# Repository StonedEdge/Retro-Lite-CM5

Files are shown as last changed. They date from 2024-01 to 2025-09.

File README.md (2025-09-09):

<div align="center">
  <h1>Retro Lite/RetrOLED CM5: RK3588s Gaming Handheld</h1>
</div>

<div align="center">
  Image of Retro Lite CM5
</div>
<p align="center">This is the RetroLED CM5, a handheld console designed by GinKage, notime2d8 and StonedEdge.</p>

<div align="center">
  Image of Retro Lite CM5
</div>
<p align="center">Running Hollow Knight via Box64 and Steam on upstream Armbian kernel.</p>

<div align="center">
  Image of Retro Lite CM5
</div>
<p align="center">Official Android support, thanks to the work of notime2d8.</p>

<div align="center">
  Image of Retro Lite CM5
</div>
<p align="center">Latest ROCKNIX images available with Vulkan driver support.</p>

<div align="center">
  Image of Retro Lite CM5
</div>
<p align="center">Open source hardware files available for download.</p>

The Retro Lite/RetrOLED CM5 is an upgrade to the Retro Lite CM4 handheld. The project goal is to create a more powerful handheld that can handle 3DS, PS2 and GC emulation (none of which the Pi can do). I also would like to be able to play some games via Box64/86. It has a relatively large battery so run time should be excellent, considering it is ARM based. **Now with an optional OLED upgrade!**

Powered by the RK3588s compute module from Radxa, which is an SBC SOM module with an ARMv8 64-bit processor. Features 8 cores/threads - 4 x ARM Cortex-A55/A76 cores with A55 cores clocked at 1.8GHz, and A76 cores clocked at 2.4GHz. It also has a built-in Mali G610 GPU. 

The Retro Lite/RetrOLED CM5 offers a more modern gaming experience with DisplayPort via USB Type-C, USB 3.0 & HDMI 2.1. Built-in PCIe WiFI 6.0 & BT 5.2, as well as a new 720p IPS display @ 5.5" with touchscreen support & dual tact trigger buttons for GameCube support, make this a much more viable low-powered ARM SBC gaming PC than the Raspberry Pi 4. 

The operating system will be based on Armbian, with a custom device tree for hardware interfacing & RetroPie pre-installed. However, the user can use it however they would like, either in a Linux desktop environment or with other Linux based frontends, such as ES-DE. This handheld should be able to play the entire PS2 library at least 1x native resolution for all games, as well as GameCube at 1x on Linux with OpenGLES drivers. Android is currently more performant due to Vulkan drivers, however Linux Vulkan blobs should come soon (or someday, who knows). We also now have succesfully compiled ROCKNIX as well. Eventually I will compile all of the final images to GitHub. 

For regular updates/following progress on the build, please check out the forum post here:
https://bitbuilt.net/forums/index.php?threads/retro-lite-cm5.5815/

# Retro Lite/RetrOLED CM5: Radxa RK3588s Handheld 

## Features

Hardware specifications:

- 3D printable housing in PLA. Comfort grips for added ergonomics
- Radxa CM5 Compute Module (8GB RAM/64GB eMMC)
- SoC – Rockchip RK3588S octa-core processor with 4x Cortex‑A76 cores @ up to 2.4GHz, 4x Cortex‑A55 core @ 1.8GHz
Arm Mali-G610 MP4 “Odin” GPU Video decoder – 8Kp60 H.265, VP9, AVS2, 8Kp30 H.264 AVC/MVC, 4Kp60 AV1, 1080p60 MPEG-2/-1, VC-1, VP8 Video encoder – 8Kp30 H.265/H.264 video encoder
- WiFi 6/Bluetooth 5.2 via PCIe E-key slot (Intel AX210) - https://www.intel.com/content/www/us/en/products/sku/204836/intel-wifi-6e-ax210-gig/specifications.html
- 6 layer carrier board with 3 B2B mezzanine connectors to interface with any Radxa CM5 module 
- 5v boost rated at 3.5A continuous current
- RP2040 gamepad - complete with SDL mappings and evdev gyro support/mouse control via MPU6050
- 1280 x 720p (5.5" DSI IPS LCD): DSI video output on internal display
**- New: Optional 1920 x 1080p (5.44" AMOLED): DSI video output on internal display** 
- Up to 4k HDMI video output via HDMI output
- Up to 4k DisplayPort Alternate Mode via Type-C
- USB 2.0/3.1 capable USB-C data transfer
- USB-C dual role port functionality (sink/source)
- Brightness and volume HUD adjustment. Brightness is adjusted by holding plus hotkey + down/up. Volume controlled either by volume buttons or plus hotkey + left right DPAD
- USB-C PD charging support via sink profiles supporting 5V/3A, 9V/3A, 12V/2A & 15V/2.6A (switch charger) via TPS65987D PD controller (see binary in TPS65987D folder). Recommended to use <12V for best charge and play performance 
- Stereo Audio Output via i2s. Dual stereo speakers with ported chambers
- Headphone jack, with automatic switching
- 5000mAh lipo, providing around 1.5-5 hours of gameplay depending on load (to be upgraded soon to >8000mAh)
- Dual stacked shoulder buttons (L, R, LZ, RZ) with dual tact buttons for GameCube functionality (LR analog/LR digital)
- 2x hall effect analog sticks running at 3v3
- Resin casted ABXY, DPAD, start+select, shoulder buttons
- Silicone membranes for nice button feel 

Software specifications:

- Armbian GNOME desktop (Kernel 6.1.57 as of this post)
- Android 13 support (beta)
- Full upstream Rocknix support
- Wayland windowing system (xorg capable)
- Hardware graphics support via Panfrost/OpenGLES/I want a broken vulkan driver "support"
- Safe software/hardware shutdown (either from software or via button)
- Low power sleep mode - in my tests, 24 hours in standby mode draws around 6% of total battery life
- Range adjustable joysticks in software by pressing plus hotkey plus R3 --> A --> rotate sticks --> A combination
-------------------------------------------------------------------------------------------------------

### CAD
Enclosure files have been uploaded in STL and STEP format [here.](https://github.com/StonedEdge/Retro-Lite-CM5/tree/main/enclosure)
Make sure to use v2 as these contain all the latest and greatest changes. 

-------------------------------------------------------------------------------------------------------

### PCB
v1 Controller PCBs have been uploaded [here.](https://github.com/StonedEdge/Retro-Lite-CM5/tree/main/rp2040_gamepad/PCB)
Please note that you will not be able to assemble the unit with the UART/serial debug components soldered onto the boards, so make sure these aren't populated. 

v1.1 CM5 carrier boards have been uploaded [here.](https://github.com/StonedEdge/Retro-Lite-CM5/tree/main/cm5_carrier_pcb)

-------------------------------------------------------------------------------------------------------

### BOM (Bill of Materials) 
v1 Right Controller PCB BOM have been uploaded [here.](https://github.com/StonedEdge/Retro-Lite-CM5/blob/main/rp2040_gamepad/PCB/Retro_Lite_CM5_Right_PCB_v1%20-%20BOM.csv)

v1 Left Controller PCB BOM have been uploaded [here.](https://github.com/StonedEdge/Retro-Lite-CM5/blob/main/rp2040_gamepad/PCB/v1/Retro_Lite_CM5_Left_PCB_v1%20-%20BOM.csv)

v1 V2.2 Carrier PCB BOM has been uploaded [here.](https://github.com/StonedEdge/Retro-Lite-CM5/blob/main/cm5_carrier_pcb/Retro_Lite_CM5_IO_X2.2_BOM.csv) 
The board has been verified and fully functional with Radxa V2.2 CM5 modules! V2.21 also works fine. 

-------------------------------------------------------------------------------------------------------

### To-do
- [x] Hardware familiarization - Orange Pi 5/Radxa CM5/IO board schematics
- [x] Design v1 prototype left/right controller PCBs (ATMEGA32u4 based)
- [x] Design v1 DSI test display board
- [x] Design v1 Power Management/DisplayPort/USB-C PD test board
- [x] Order v1 Power Management/DisplayPort/USB-C PD test board
- [x] Design v2 prototype left/right controller PCBs (RP2040 based)
- [x] Test v1 Power Management/DisplayPort Alternate Mode/USB-C PD test board functionality - works!
- [x] Design CM5 carrier main board (v1.0) that implements new hardware features, such as DisplayPort, USB3 and PCIe
- [x] Order CM5 carrier board (v1.0) with desired fab house. (It's in production!)
- [x] Test CM5 carrier board (v1.0) hardware for a basic functioning prototype
- [x] Redesign CM5 carrier board (v1.1) with fixes for 3rd connector polarity & other small fixes
- [x] Reorder v1.1 carrier board
- [x] Investigate RK806 PMIC issue
- [x] Prepare an Armbian based OS image, including the BSP (bootloader, dtb and kernel) for the RK3588s Armbian rootfs. DTB should include the ILI9881C/WM8960 drivers
- [x] Integrate new 5.5 inch MIPI DSI display. This includes enabling the ILI9881C display driver, device tree customizations for the display
- [x] Test and verify display functionality, including proper backlight & 60 FPS. Verify display works with Armbian 
- [x] WM8960 codec integration via Orange Pi 5/CM5 IO for testing. Integrate the WM8960 i2c code driver including any device tree customizations for codec. Finally, test and verify audio works correctly
- [x] Integrate touch/verify via the GT911 controller 
- [x] Test and verify emulators work correctly with Mali blobs and can be launched via EmulationStation front end
- [x] Setup Mali Open GL blob drivers to work with PS2 (AetherSX2) & GC (Dolphin) emulators due to no Vulkan backend available (yet!)
- [x] Write HID controller code for RP2040. Verify basic gamepad functionality works as intended
- [x] Integrate an IMU into the controller PCB for gyro functionality. Include EKF algorithm (MPU-6050 6-axis IMU) 
- [x] Redesign housing (increase 3mm in all directions) in Solidworks. Improve trigger feel and add battery mounting bracket
- [x] Redesign housing v2 (increase thickness to accomodate 6Ah battery cell at 3.8v, mount battery and fan to front housing)
- [x] Redesign housing with injection molding in mind - include appropriate draft angles, ribs, gussets, radiused corners & bosses
- [x] Redesign housing to use original switch lite fan enclosure 
- [x] Power on/power off/sleep mode via ATtiny84 (Power control)
- [x] Put together a fully functional dts for the CM5 IO Board (Device Tree Source) to understand hardware configuration 
- [x] MAX17055 integration into device tree 
- [x] Prepare reference implementation for launching games via EmulationStation/some form of frontend (likely ES-DE/RetroPie)
- [x] Implement an on-screen indicator for volume, brightness control via GPIOs
- [x] Rocknix upstream support
- [x] Android 13 support 
- [ ] Adjust BQ24292i registers to charge to 4.35v max instead of 4.2v due to using LiHv cell (might not do, given cells may go kaboom)
- [x] Other optimizations/improvements/bug fixes
- [x] Create prototype showcase video for YouTube
- [x] Final GitHub open source release & announcement!
- [x] Integrate OLED RM67199 patches
- [x] Integrate goodix gtx8 patches (GT9886)
-------------------------------------------------------------------------------------------------------

### Firmware 
At the moment, there are a couple of options for firmware which I will separate out into two devices, the Retro Lite CM5 and the RetrOLED CM5. 
We are continuing to work on these - few developers will be getting units soon which should accelerate the process of development as well.  

**Retro Lite CM5**
- [x] ROCKNIX
- [x] Armbian Gnome Desktop (OpenGL/OpenGLES)
- [x] Armbian Gnome Desktop (OpenGLES/Vulkan)
- [x] Android 13 (Beta)
- [ ] Android 14 (kind of lost interest in Android, probably not likely to happen anytime soon). 

**RetrOLED CM5**
- [x] ROCKNIX
- [x] Armbian Gnome Desktop (OpenGL/OpenGLES)
- [x] Armbian Gnome Desktop (OpenGLES/Vulkan)
- [ ] Android 13 (Beta - shit is broken, like brightness control which we never got working)
- [ ] Android 14 (kind of lost interest in Android, probably not likely to happen anytime soon). 
-------------------------------------------------------------------------------------------------------

### Frequently Asked Questions (FAQ) 
Q: How can I get my hand on a Retro Lite/RetrOLED CM5? Do you sell them or will you sell them?

A: Radxa have advised that **this device will not be mass produced**. There is no method to get your hands on one of these at this time. This project is mainly for fun, cost is not a huge consideration here. 

Q: How much does it cost in parts to build one of these?

A: Expect to spend at minimum around $350-400 for a single one-off build. 

Q: Why dont you use an OLED screen? 

A: **Funny you ask. We now have OLED support!** The OLED screen is functioning with touch integration. We are using this OLED screen here: https://www.alibaba.com/product-detail/oled-display-module-5-44inch-oled_60726980273.html
Make sure you confirm the model number is ET055FH06-GT. You will also need to order the flex PCB with JLCPCB (costs around $10). 2 layer is fine, make sure to send them the production files as a reference. I have verified that it works with the current carrier board. 

Q: Why do this when you can get an equivalent handheld from Aliexpress for $150? This is stupid and DOA! Makes no sense! Non-sensical! I'm going to buy myself a better handheld. 

A: Because it's fun to build something awesome. It's not about the end result, its the process for me. Thanks for visiting & farewell, this project probably isn't for you. 

Q: Is Vulkan working yet on Linux?

A: We have a temporarily solution for Vulkan on Linux, but the driver is not conformant yet. PanVk is on its way though. 

Q: Can you please make me one for exposure on YouTube? I promise to give incredible reviews!

A: Nope. I simply don't have time. Sorry. 

### License

[][cc-by-nc-sa]

This work is licensed under a
[Creative Commons Attribution-NonCommercial-ShareAlike 4.0 International License][cc-by-nc-sa].

[][cc-by-nc-sa]

[cc-by-nc-sa]: http://creativecommons.org/licenses/by-nc-sa/4.0/
[cc-by-nc-sa-image]: https://licensebuttons.net/l/by-nc-sa/4.0/88x31.png
[cc-by-nc-sa-shield]: https://img.shields.io/badge/License-CC%20BY--NC--SA%204.0-lightgrey.svg

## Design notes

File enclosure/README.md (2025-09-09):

### Current Status
The shell is complete. Rear triggers have been tweaked to work better than previous versions, but always open to feedback and improvements here. 

After assembling v1 and running tests, I am working on improvements to the design which will be uploaded to STL_v2 folder. It is recommended to assemble v2 only (v1 is now deprecated).

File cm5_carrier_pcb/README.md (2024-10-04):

# Retro Lite CM5 Carrier Board v1.1 

<p align="center">
  
</p>

## What is this folder?
Note: The current files are now tested and verified to work with Radxa v2.2 carrier boards. **Also now verified to work Radxa V2.21 boards!**

This folder contains the BOM, EAGLE schematic (.sch) and board (.brd) files, as well as pick & place files to order the board with JLCPCB or your fab of choice. 
The main carrier board is a 6-layer board and you should order the board with impedance matching, according to the JLC06081H-2116 (Standard) stackup offering (0.8mm thickness). 
Currently, this version is only compatible with the Radxa CM5 (version X2.2/X2.21) & I have not tested it with other SoMs, like the Raspberry Pi CM4. 

Expect to pay around $250 per board to have it fabbed and turnkeyed with JLCPCB.

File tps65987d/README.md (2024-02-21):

# TPS65987D Test Board v3

<p align="center">
   
</p>

## What is this folder? 
This folder contains the test fixture schematic and board files (EAGLE) designed to test the functionality of the TPS65987D PD controller and TUSB546A superspeed mux, as well as other features that will be included on the main carrier board for the final build. Feel free to use it as a reference design for a USB-C DRP application in your designs. 
It also contains the project file that can be used to edit specific parameters in the TPS65987x GUI Application Tool, depending on your required use case. I used an RP2040 to flash the binary to the SPI module & final binary to be used in the CM5 will be uploaded when ready. 

## Purpose of PCB
To provide an environment to test out the TPS6598x GUI Application Tool, change parameters and flash a binary for a USB-C DRP application. The current CM5 is programmed with the parameters found in the .pjt file here. You can use this tool if you want to play around with it or change certain parameters to suit your specific application: https://www.ti.com/tool/TPS6598X-CONFIG

The flash module is an W25X05 and communicates with the PD device over the SPI bus. It loads this flash either via 3V3 power or dead battery mode via VBUS power. You can also program the TPS65987D (the USB-PD controller) via the I2C bus. 

The bottom USB-C connector is for plugging in sink/source device to charge the battery or power a USB device (like a keyboard, mouse or thumb drive). This will be the port on the final handheld itself. 

The top two USB-C ports are for high speed data buses, namely DisplayPort & USB 3.1.

The ATtiny is connected to the button, which is used to control power, sleep & regulator enable. We use this to safely tell the CM5 to shutdown before the enable pin is driven low. The ATtiny is also connected to the BQ24292i over I2C & sets the specific registers required for monitoring the battery - charging current, termination current, and other parameters like charge cutoff voltage. 

Flash the SPI module via the command line, for example, using serprog. 
```flashrom -p serprog:dev=/dev/ttyACM0:115200,spispeed=12M -c W25X05 -w .bin```

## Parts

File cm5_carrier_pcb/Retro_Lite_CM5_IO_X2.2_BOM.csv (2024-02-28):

Qty | Value | Device | Package | Parts | Description
6 | N/A | LEDSML0603 | SML0603 | PDO1, PDO1_SRC, PDO2, PDO3, PDO4, SSMX_DP_ACTIVE, SSMX_FLIP_ACTIVE | BLUE_LED_GENERIC
1 | N/A | LEDSML0603 | SML0603 | CHRG | WHITE_LED_GENERIC
1 | N/A | LEDSML0603 | SML0603 | VBAT_L | RED_LED_GENERIC
5 | 0R | R-EU_R0402 | R0402 | JU_5, R13, R34, R36, R42 | Resistor
1 | 0.047µF | C-EUC0603 | C0603 | C29 | Capacitor
1 | 0.1uF | C-EUC0402 | C0402 | C20 | Capacitor
6 | 0.1uF | C-EUC0402-YVELTAL | C0402 | C17, C19, C39, C54, C62, C65 | Capacitor
4 | 0.1uF | C-EUC0603 | C0603 | C12, C13, C18, C26 | Capacitor
1 | 0.47uF | C-EUC0402-YVELTAL | C0402 | C64 | Capacitor
2 | 0R | R-EU_R0402 | R0402 | R51, R54 | Resistor
1 | 1.0uF | 1.0UF-0603-16V-10% | C0603 | C93 | Capacitor
5 | 1.8k | R-EU_R0402 | R0402 | R38, R47, R48, R52, R53 | Resistor
2 | 100K | R-EU_R0402 | R0402 | R60, R61 | Resistor
3 | 100R | R-EU_R0402 | R0402 | R8, R44, R55 | Resistor
1 | 100k | R-EU_R0402 | R0402 | R50 | Resistor
3 | 100k 1% | R-EU_R0402 | R0402 | R24, R64, R65 | Resistor
18 | 100nF | C-EUC0402 | C0402 | C6, C7, C21, C22, C24, C25, C33, C34, C37, C70, C71, C72, C73, C74, C75, C80, C81, C82 | Capacitor
12 | 100nF | C-EUC0402-YVELTAL | C0402 | C3, C5, C9, C32, C49, C51, C53, C56, C63, C67, C84, C94 | Capacitor
1 | 100pF | C-EUC0402-YVELTAL | C0402 | C57 | Capacitor
2 | 100uF | C-EUC1206 | C1206 | C35, C36 | Capacitor
1 | 105450-0101 | 105450-0101 | MOLEX_105450-0101 | J7 | USB-C Connector
1 | 1072TR | 1072TR | CONN_1072TR_KEY | J11 | Coin Cell Connector
5 | 10K | R-EU_R0402 | R0402 | R11, R27, R40, R62, R90 | Resistor
5 | 10R | R-EU_R0603 | R0603 | R15, R16, R17, R18, R19 | Resistor
12 | 10k | R-EU_R0402 | R0402 | R1, R2, R6, R31, R56, R77, R79, R80, R81, R82, R83, R85 | Resistor
2 | 10k | R-EU_R0603 | R0603 | R26, R35 | Resistor
1 | 10k 1% | R-EU_R0402 | R0402 | R63 | Resistor
1 | 10kΩ | R-EU_R0402 | R0402 | R45 | Resistor
1 | 10kΩ | R-EU_R0603 | R0603 | R46 | Resistor
4 | 10nF | C-EUC0805 | C0805 | C43, C44, C45, C48 | Capacitor
1 | 10uF | 1.0UF-0603-16V-10% | C0603 | C121 | Capacitor
1 | 10uF | 1.0UF-0805-25V-(+80/-20%) | C0805 | C38 | Capacitor
3 | 10uF | C-EUC0402 | C0402 | C86, C87, C89 | Capacitor
3 | 10uF | C-EUC0402-YVELTAL | C0402 | C58, C59, C66 | Capacitor
1 | 10uF | C-EUC0603 | C0603 | C78 | Capacitor
1 | 10uF | C-EUC0805 | C0805 | C83 | Capacitor
5 | 10µF | C-EUC0805 | C0805 | C4, C23, C27, C28, C31 | Capacitor
1 | 12pF | C-EUC0402-YVELTAL | C0402 | C85 | Capacitor
1 | 1M | R-EU_R0402 | R0402 | R92 | Resistor
2 | 1uF | C-EUC0402 | C0402 | C8, C50 | Capacitor
2 | 1uF | C-EUC0603 | C0603 | C30, C55 | Capacitor
1 | 1uH | SPM5020T-1R0M | IND_SPM5020T-1R0M | L3 | Inductor
2 | 1µF | C-EUC0603 | C0603 | C47, C120 | Capacitor
1 | 1µF | C-EUC0805 | C0805 | C1 | Capacitor
2 | 2.2k | R-EU_R0402 | R0402 | R23, R58 | Resistor
1 | 2.2uH | AMDLA4530S-2R2MT | IND_AMDLA4530S-2R2MT | L2 | Inductor
12 | 220nF | C-EUC0402 | C0402 | C10, C11, C40, C41, C42, C68, C76, C77, C79, C95, C96, C97 | Capacitor
1 | 220nF | C-EUC0603 | C0603 | C46 | Capacitor
2 | 220pF | C-EUC0402 | C0402 | C60, C61 | Capacitor
11 | 22R | R-EU_R0402 | R0402 | R9, R10, R12, R14, R20, R22, R25, R28, R29, R37, R86 | Resistor
3 | 22uF | 1.0UF-0805-25V-10% | 805 | C69, C91, C92 | Capacitor
1 | 22uF | C-EUC0402 | C0402 | C52 | Capacitor
1 | 22µH | VLCF4020T-220MR56 | VLCF4020_1 | L1 | Inductor
1 | 232k | R-EU_R0402 | R0402 | R78 | Resistor
1 | 261Ω | R-EU_R0402 | R0402 | R41 | Resistor
1 | 27.4k | R-EU_R0402 | R0402 | R57 | Resistor
2 | 2M | R-EU_R0402 | R0402 | R49, R75 | Resistor
4 | 3.3k | R-EU_R0402 | R0402 | R3, R4, R30, R66 | Resistor
7 | 4.7k | R-EU_R0402 | R0402 | R5, R32, R33, R67, R68, R71, R72 | Resistor
1 | 4.7uF | C-EUC0402 | C0402 | C88 | Capacitor
3 | 4.7uF | C-EUC0603 | C0603 | C14, C15, C16 | Capacitor
1 | 4.7µF 50v | C-EUC0805 | C0805 | C119 | Capacitor
1 | 47K | R-EU_R0402 | R0402 | R7 | Resistor
1 | 47k | R-EU_R0402 | R0402 | R43 | Resistor
1 | 47uF | C-EUC0603 | C0603 | C90 | Capacitor
1 | 5025700893 | 5025700893 | MOLEX_5025700893 | J1 | SD Card Connector
2 | 5034802000 | 5034802000 | CON_5034802000_MOL | J6, J12 | Controller Board Connector
1 | 5040500491 | 5040500491 | MOLEX_5040500491 | J13 | Battery Connector
2 | 5051100492 | 5051100492 | CON_5051100492_MOL | J4, J14 | Fan/Volume/Power Connector
1 | 5051100892 | 5051100892 | CON_5051100892_MOL | J10 | CTP Connector
1 | 5051103091 | 5051103091 | CON_5051103091_MOL | J9 | MIPI Panel Connector
1 | 51k | R-EU_R0402 | R0402 | R84 | Resistor
1 | 5Ω | R-EU_R0603 | R0603 | R21 | Resistor
1 | 685119136923 | 685119136923 | WURTH_685119136923 | J5 | HDMI Mini Connector
9 | AO3400A | AO3400A | SOT95P280X125-3N | Q1, Q2, Q3, Q4, Q5, Q6, Q7, Q8, Q9 | Trans MOSFET N-CH 30V 5.7A 3-Pin SOT-23
1 | ASPI-0630HI | ASPI-0630HI | ASPI-0630HI | L6 | Inductor
2 | B5819WS-TP | B5819WS-TP | SOD2512X115N | D3, D4 | Diode 40 V 1A Surface Mount SOD-323
1 | BQ24292I | BQ24292I | QFN50P400X400X100-25N | U5 | BQ24292i Charger IC Lithium Ion/Polymer 24-VQFN (4x4)
3 | DF40C-100DS-0.4V(51) | DF40C-100DS-0.4V(51) | HRS_DF40C-100DS-0.4V(51) | CONNECTOR1, CONNECTOR2, CONNECTOR3 | DF40 Series 100 Position Dual Row 0.4 mm Pitch Surface Mount Vertical Receptacle (Mezzanines)
1 | ECS-.327-12.5-12R-TR | ECS-.327-12.5-12R-TR | XTAL_ECS-.327-12.5-12R-TR | Y2 | SMD Crystal
1 | ECS-3225MV-240-BN-TR | ECS-3225MV-240-BN-TR | OSC_ECS-2333-160-BN-TR | Y1 | SMD Crystal
1 | 9774015243R (rev1) v1 | 9774015243R (rev1) v1 | 9774015243R (rev1) v1 | H1 | Round Standoff Threaded M2x0.4 Steel 0.059" (1.50mm)
1 | MAX17055ETB+T | MAX17055ETB+T | 21-100013A_T102A2+1C_MXM | U11 | Fuel Gauge
1 | MBR0540T1G | MBR0540T1G | SOD3716X135N | D2 | 0.5A 40V Schottky Rectifier, MBR0540T1G ON Semiconductor MBR0540T1G Schottky Diode, 0.5A, 40V, 2-Pin SOD-123
1 | MCU-ATTINY84A-MU(QFN20) | MCU-ATTINY84A-MU(QFN20) | QFN20G-0.5-4X4MM | U14 | ATtiny84 Microcontroller
1 | MDT320E01001 | MDT320E01001 | AMPHENOL_MDT320E01001 | J8 | 67 Position Female Connector M.2 (NGFF) Mini Card Gold 0.020" (0.50mm) Black - Board Lock, E-Keyed (WiFi)
1 | PS0306DRF7T0R01L | PS0306DRF7T0R01L | PS0306DRF7T0R01L | R39 | 10 mOhms ±0.5% 0.5W, 1/2W Chip Resistor Wide 0603 (1608 Metric), 0306 Current Sense Metal Element
1 | SJ-43516-SMT | SJ-43516-SMT | CUI_SJ-43516-SMT | J2 | Conn 3.5MM Audio Jack F 6 POS Solder RA SMD 6 Terminal 1 Port
2 | SN74LVC1G17DCKR | SN74LVC1G17DCKR | SOT65P210X110-5N | U19, U20 | Buffer, Non-Inverting 1 Element 1 Bit per Element Push-Pull Output SC-70-5
1 | SY8089AAACSY8089AAAC_SGY-L | SY8089AAACSY8089AAAC_SGY-L | SY8089AAAC_SGY-L | U12 | SY8089 and SY8089A are high-efficiency, high frequency synchronous step-down DC-DC regulator IC capable of delivering up to 2A output current
4 | TPD4E05U06DQAR | TPD4E05U06DQAR | IC_TPD4E05U06DQAR | U2, U3, U22, U24 | 14V Clamp 2.5A (8/20µs) Ipp Tvs Diode Surface Mount 10-USON (2.5x1)
1 | TPS61160ADRVT | TPS61160ADRVT | SON65P200X200X80-7N | U16 | White LED Driver with PWM Brightness Control in 2mm x 2mm Package. Up to 10 LEDs in Series
1 | TPS61235PRWLT | TPS61235PRWLT | CONV_TPS61235PRWLT | U7 | TPS6123x 8-A Valley Current Synchronous Boost Converters with Constant Current Output Feature 9-VQFN-HR -40 to 85 Check availability
1 | TPS65987DDHRSHR | TPS65987DDHRSHR | IC_TPS65987DDHRSHR | U21 | USB Type-C™ and USB PD Controller With Integrated Power Switches 56-VQFN -40 to 85 Check availability
1 | HYM8563TS | HYM8563TS | HYM8563TS | U18 | HYM8563 CMOS RTC IC
1 | TUSB546-DCIRNQT | TUSB546-DCIRNQT | QFN40P400X600X80-41N | U23 | Buffer, ReDriver 2 Channel 8.1Gbps 40-WQFN (4x6)
4 | UM3204QQFN14_3.5X3.5_UM3204_USC-L | UM3204QQFN14_3.5X3.5_UM3204_USC-L | QFN14_3.5X3.5_UM3204_USC-L | U8, U9, U10, U13 | Bidirectional Voltage-Level Translators
1 | W25X05CLUXIGTR | W25X05CLUXIGTR | PSON50P300X200X60-9N | U4 | SPI Flash Module
1 | WM8960 | WM8960 | QFN50P500X500X100-33N | U6 | Audio Amplifier

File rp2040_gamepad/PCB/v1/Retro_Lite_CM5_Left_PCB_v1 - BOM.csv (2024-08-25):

Comment | Designator | Footprint | Qty | DNP
0.1uF | C10 C14 | C0402 | 2 | U$8
5034802000 | J2 | CON_5034802000_MOL | 1
BM02B-SURS-TF(LF)(SN) | J1 | JST_BM02B-SURS-TF(LF)(SN) | 1
SWITCHSTICK_BREAKOUT | U$7 | SWITCHSTICK_BREAKOUT | 1
TMHF07 | U$8 | TMHF07 | 1
TPTP07R | TP1 TP2 TP3 TP4 TP5 TP6 TP7 TP8 TP19 TP20 TP21 TP22 TP23 | TP07R | N/A
436333033816 | J3 | CONN3_3033816_WRE | 1
EVQ-Q2B03W | DPAD_DN DPAD_L DPAD_R DPAD_UP DPAD_UP1 SELECT | EVQQ2_3 | 6
MEMBRANEBUTTON | HOTKEY U$1 U$2 U$3 U$4 U$5 | MEMBRANEBUTTON | N/A

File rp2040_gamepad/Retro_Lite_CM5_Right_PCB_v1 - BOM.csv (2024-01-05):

Part Value/No | Designator | Quantity | Unit Price | Total | Footprint | Source Link
0.1uF | C2 C3 C10 C14 C25 C26 C27 C28 C30 C31 C33 C34 C35 C37 | 50 | 0.0054 | 0.27 | C0402 | https://www.digikey.jp/en/products/detail/samsung-electro-mechanics/CL05A104KA5NNNC/3886701
1K | R12 R15 | 10 | 0.015 | 0.15 | R0402 | https://www.digikey.jp/en/products/detail/yageo/RC0402FR-071KL/726513
1uF | C29 C32 C36 | 10 | 0.017 | 0.17 | C0402 | https://www.digikey.jp/en/products/detail/samsung-electro-mechanics/CL05A105KQ5NNNC/3886668
2.2nF | C1 | 1 | 0.11 | 0.11 | C0402 | https://www.digikey.jp/en/products/detail/kemet/C0402C222K3GEC7867/8644401
5.1K | R4 R5 | 10 | 0.012 | 0.12 | R0402 | https://www.digikey.jp/en/products/detail/yageo/RC0402FR-135K1L/14286364
10K | R1 R2 R3 R6 R11 | 10 | 0.012 | 0.12 | R0402 | https://www.digikey.jp/en/products/detail/bourns-inc/CR0402-FX-1002GLF/3593192
10pF | C15 C20 | 10 | 0.025 | 0.25 | C0402 | https://www.digikey.jp/en/products/detail/murata-electronics/GRM1555C1H100JA01D/3661907
10uF | C5 C6 | 10 | 0.019 | 0.19 | C0402 | https://www.digikey.jp/en/products/detail/murata-electronics/GRM155R60J106ME05D/11500166
274R | R9 R10 R16 | 10 | 0.015 | 0.15 | R0402 | https://www.digikey.jp/en/products/detail/yageo/RC0402FR-0727R4L/5280945
100R | R7 R8 | 10 | 0.015 | 0.15 | R0402 | https://www.digikey.jp/en/products/detail/yageo/RC0402FR-07100RL/726527
434133025816 | S1 U9 | 2 | 0.54 | 1.08 | SMD_025816_WRE | https://www.digikey.jp/en/products/detail/w%C3%BCrth-elektronik/434133025816/9950810
5034802000 | J4 | 1 | 1.79 | 1.79 | CON_5034802000_MOL | https://www.digikey.jp/en/products/detail/molex/5034802000/2356628
AP2112K-3.3 | U3 | 1 | 0.35 | 0.35 | SOT23-5 | https://www.digikey.jp/en/products/detail/diodes-incorporated/AP2112K-3-3TRG1/4470746
BM02B-SURS-TF(LF)(SN) | J1 | 1 | 0.44 | 0.44 | JST_BM02B-SURS-TF(LF)(SN) | https://www.digikey.jp/en/products/detail/jst-sales-america-inc/BM02B-SURS-TF/2241777
BM03B-SRSS-TB(LF)(SN) | J5 | 1 | 0.53 | 0.53 | CONN_BM03B-SRSS-TB(LF)(SN)_JST | https://www.digikey.jp/en/products/detail/jst-sales-america-inc/BM03B-SRSS-TB/926695
ECS-120-18-33-JGN-TR3 | Y1 | 1 | 0.4 | 0.4 | XTAL_ECS-120-18-33-JGN-TR3 | https://www.digikey.jp/en/products/detail/ecs-inc/ECS-120-18-33-JGN-TR3/14825142
MPU-6050 | U2 | 1 | 8.71 | 8.71 | QFN24_4MM_SMSC | https://www.digikey.jp/en/products/detail/tdk-invensense/MPU-6050/4038009
RP2040 | U6 | 1 | 0.7 | 0.7 | QFN40P700X700X90-57N | https://www.digikey.jp/en/products/detail/raspberry-pi/SC0914-13/14306010
5051100592 | U1 | 1 | 0.7 | 0.7 | 5051100592 | https://www.digikey.jp/en/products/detail/molex/5051100592/5700453
TMHF07 | U2 | 1 | 0.2 | 0.2 | TMHF07 | https://www.alibaba.com/product-detail/kejian-tmhf07-6-5-6-2_1600173857791.html
U262-161N-4BVC11 | J2 | 1 | 1 | 1 | U262-161N-4BVC11 | https://www.lcsc.com/product-detail/USB-Connectors_XKB-Connectivity-U262-161N-4BVC11_C319148.html
W25Q64JVXGIQ_TR | U5 | 1 | 1.1 | 1.1 | DFN_XGIQ_TR_WIN | https://www.digikey.jp/en/products/detail/winbond-electronics/W25Q64JVXGIQ-TR/15181863
EVQQ2B03W | A B X Y START | 5 | 0.26 | 1.3 | EVQQ2B03W | https://www.digikey.jp/en/products/detail/panasonic-electronic-components/EVQ-Q2B03W/762882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
 |  |  | Total BOM | 19.98

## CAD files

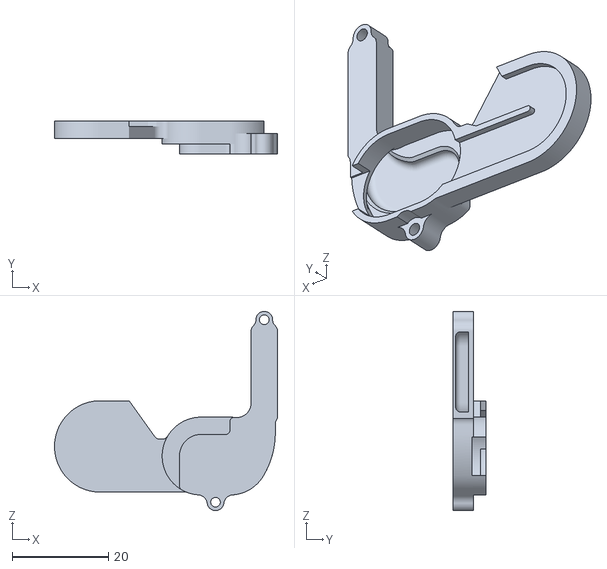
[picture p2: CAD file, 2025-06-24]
enclosure/STL_V2/Left Speaker Chamber Assembly.stl
46.4 x 6.80 x 41.4

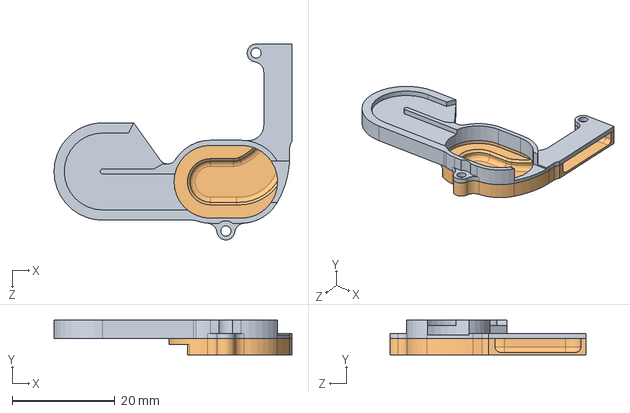
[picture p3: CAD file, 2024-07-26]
enclosure/Solidworks/Speaker Assembly.SLDASM
46.4 x 6.80 x 38.2 mm
Speaker Duct
Speaker Duct Lower

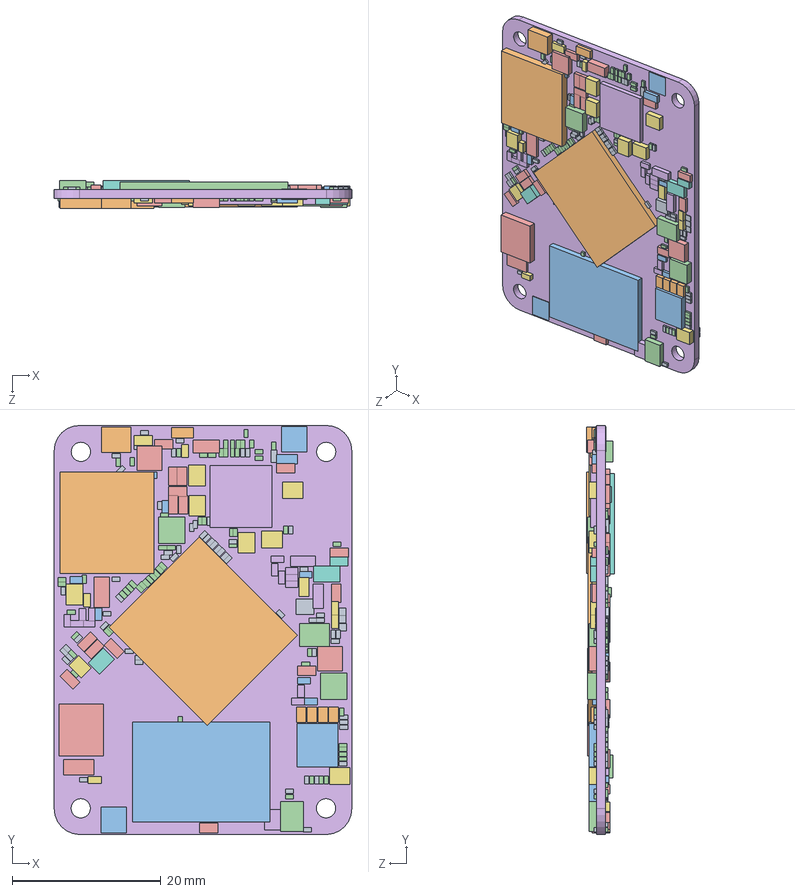
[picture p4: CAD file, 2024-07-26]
enclosure/Solidworks/Radxa CM3.SLDASM
40.0 x 55.0 x 3.70 mm
Board_outline
ANT2
C1 x 27
C10 x 204
C105 x 45
D1 x 2
ED8144 x 5
ED8147
FB1 x 6
FB5 x 4
FB9
J1
J90033 x 2
L1
L10 x 7
L13
L2 x 125
LED1
M1 x 4
Q4
Q5 x 2
R1 x 25
R24 x 5
R9216 x 2
TP1 x 13
U1
U2
U3 x 3
U4300
U4301
U4302
U5
U7
U8
U9
Y1 x 3
Y4
Board_outline(1)

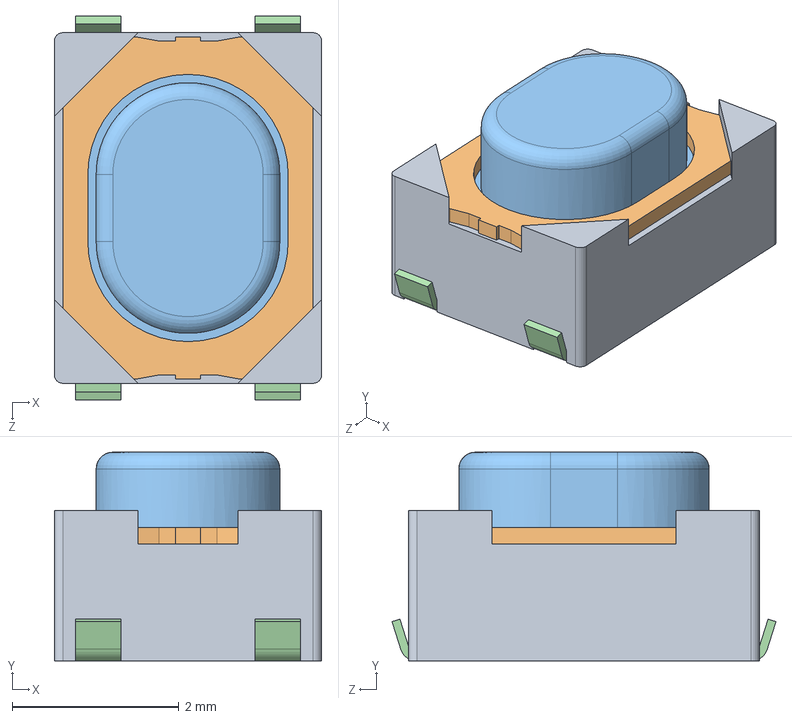
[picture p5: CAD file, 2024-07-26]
enclosure/Solidworks/RESET (rev1) v1.SLDASM
3.20 x 2.50 x 4.60 mm
Frame
Cover
Stem
Terminal x 4

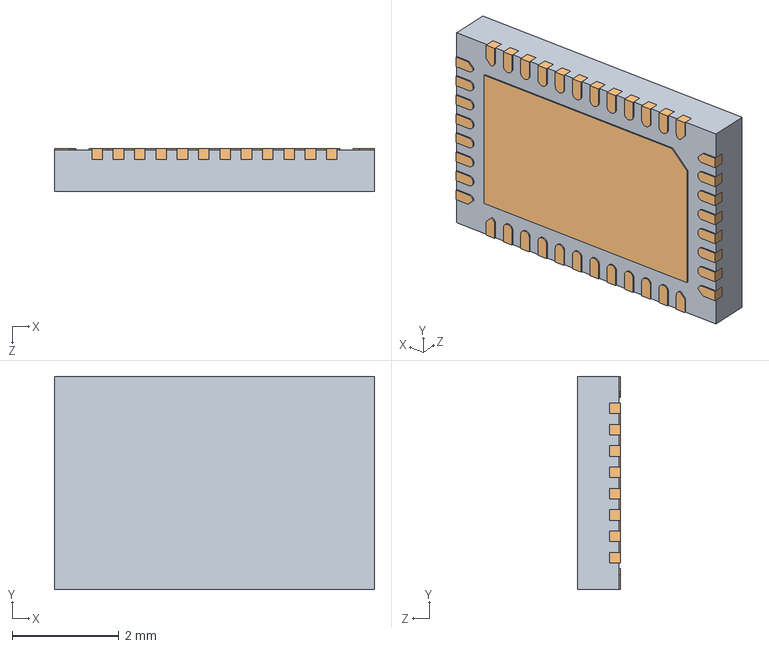
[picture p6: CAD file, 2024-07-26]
enclosure/Solidworks/RNQ0040A v1.SLDASM
6.00 x 4.00 x 0.8 mm
BODY-QFN
FRAME-RNQ0040A

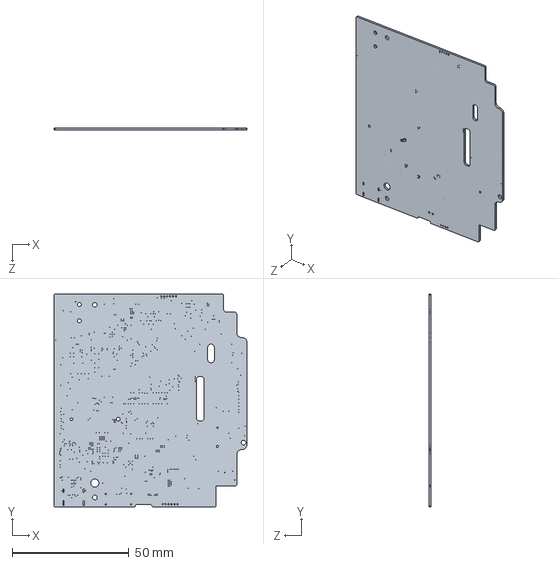
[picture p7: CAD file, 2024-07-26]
enclosure/Solidworks/Retro Lite CM5 Carrier Board_CM5IO_Mapping_X2.0 v3.SLDASM
82.7 x 91.2 x 0.972 mm

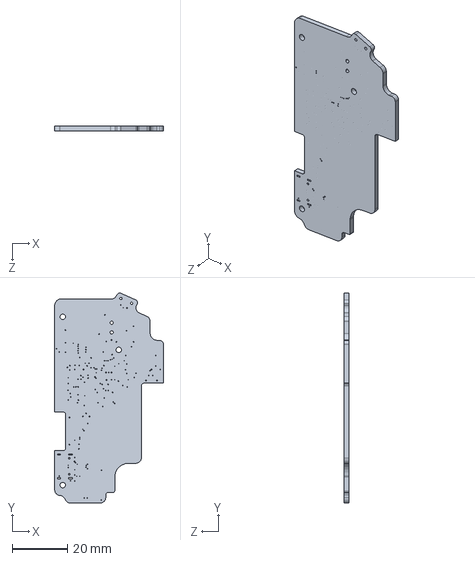
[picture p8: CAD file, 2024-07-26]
enclosure/Solidworks/Retrolite CM5 RCPCB v1 - RP2040 v2.SLDASM
39.5 x 76.1 x 1.67 mm

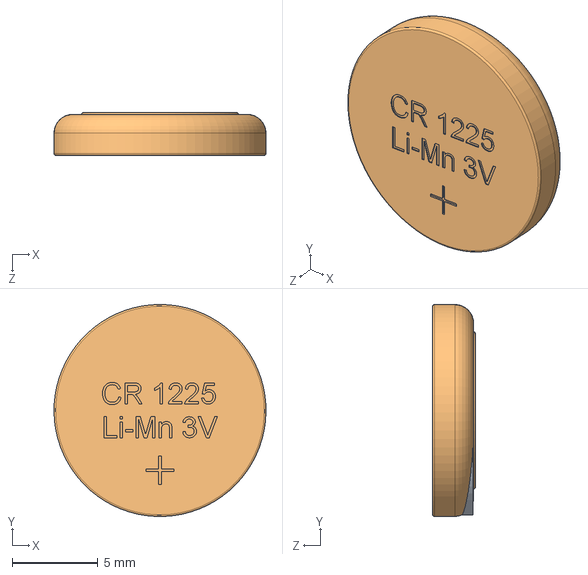
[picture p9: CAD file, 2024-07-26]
enclosure/Solidworks/User Library-CR1225 v1.SLDASM
12.4 x 12.4 x 2.50 mm
refine_Revolution001
refine_Cut001

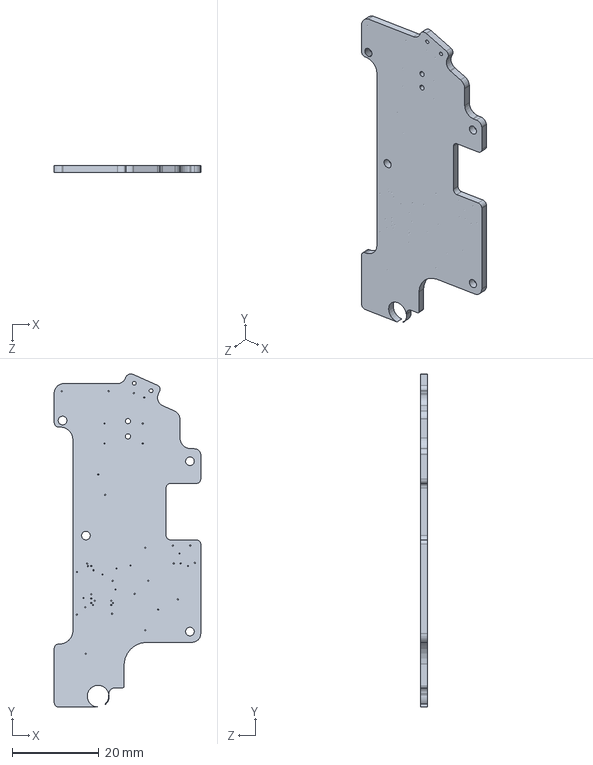
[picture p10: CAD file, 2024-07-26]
enclosure/Solidworks/Retrolite CM5 LCPCB v2 v1 (4).SLDASM
33.8 x 76.7 x 1.67 mm

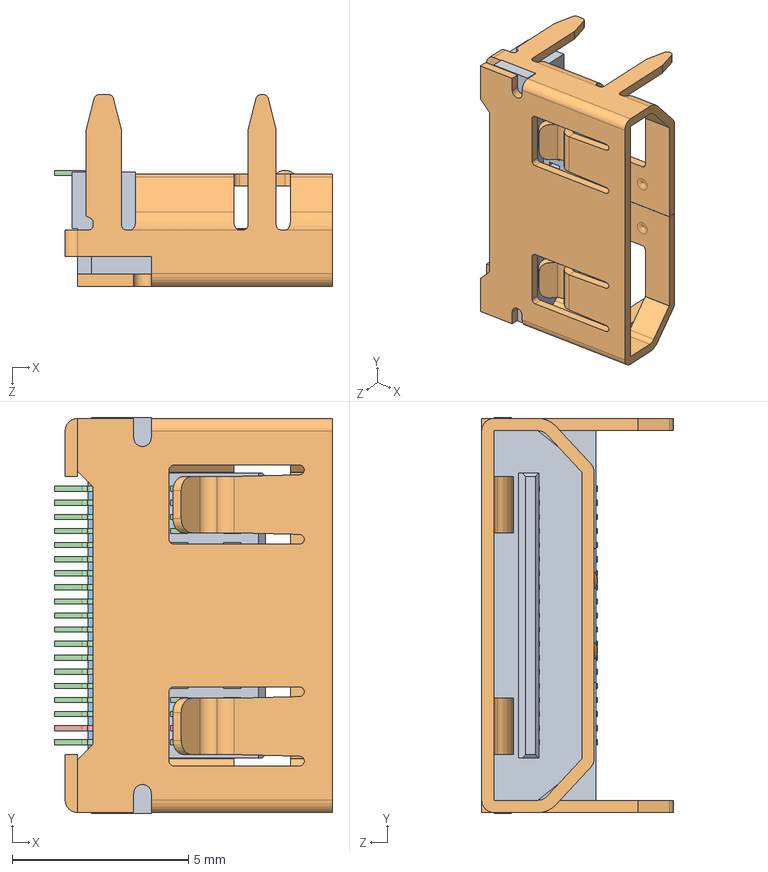
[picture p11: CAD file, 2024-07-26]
enclosure/Solidworks/Mini HDMI 685119136923.SLDASM
7.90 x 11.2 x 5.45 mm
Housing
Shielding
Housing2
Pin1 x 18
Pin2

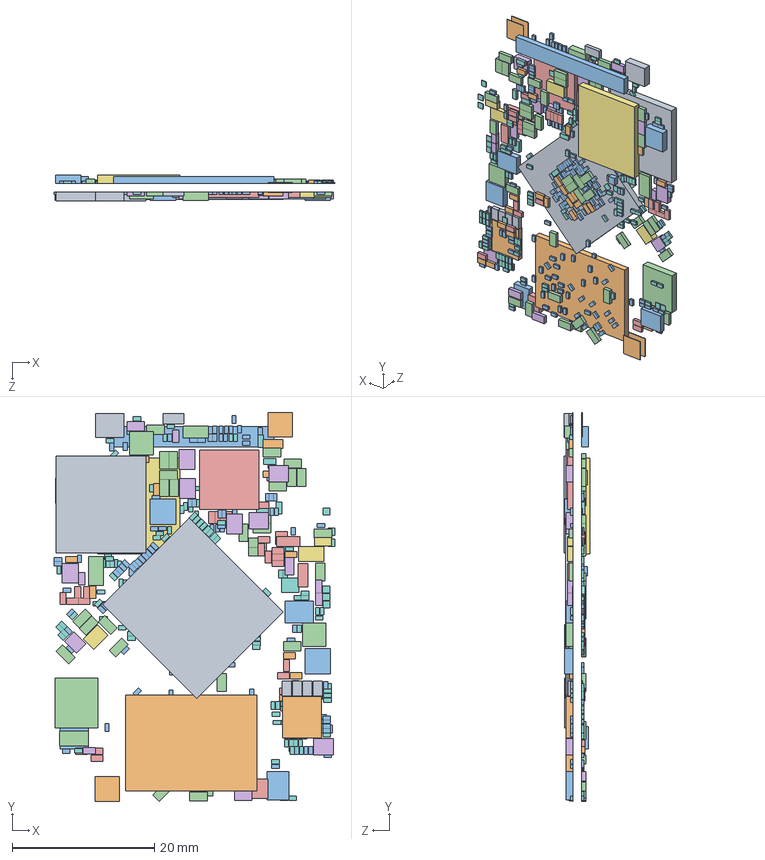
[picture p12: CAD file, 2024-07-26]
enclosure/Solidworks/EMP_Models.SLDASM
39.5 x 54.7 x 3.70 mm
ANT2
C1 x 27
C10 x 204
C105 x 45
D1 x 2
ED8144 x 5
ED8147
FB1 x 6
FB5 x 4
FB9
J1
J90033 x 2
L1
L10 x 7
L13
L2 x 125
LED1
M1 x 4
Q4
Q5 x 2
R1 x 25
R24 x 5
R9216 x 2
TP1 x 13
U1
U2
U3 x 3
U4300
U4301
U4302
U5
U7
U8
U9
Y1 x 3
Y4

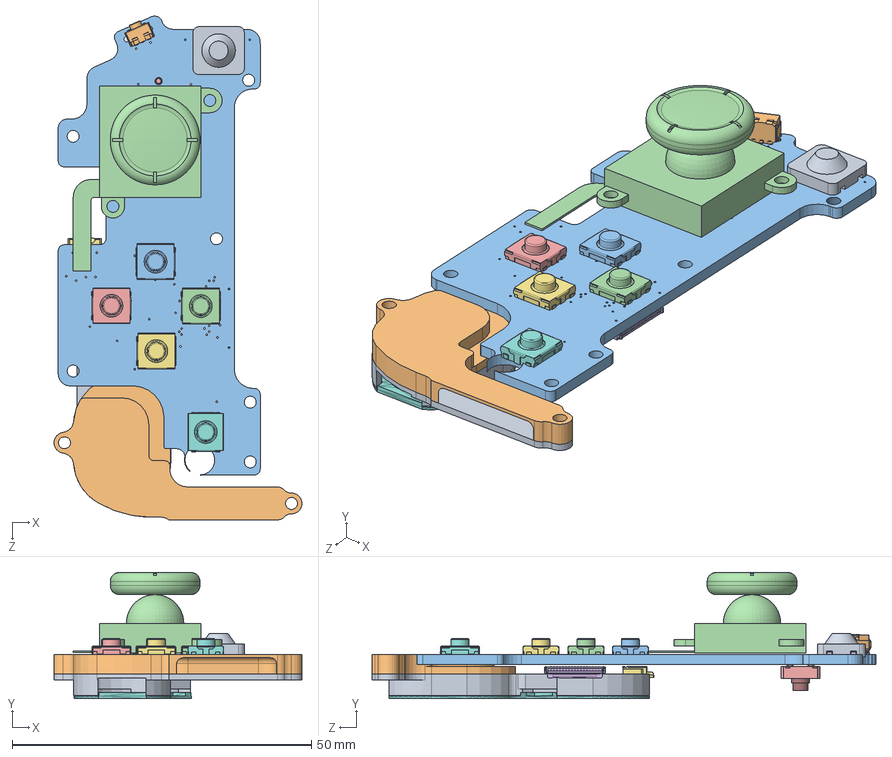
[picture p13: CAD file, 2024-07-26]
enclosure/Solidworks/Assembly Left PCB Controller.SLDASM
41.5 x 21.1 x 84.2 mm
MirrorSpeaker Duct (2)
MirrorSpeaker Duct Lower (2)
Board (38)
Switch Joystick Blank
dualtact_BBStore v1
5034801700 v1
505110-0592 v1
Printed-Speaker-Duct-Lid-Mirrored v1
Single Silicone Cap
436333033816 v1
Retro Lite CM5 (Latest)
Retro Lite CM5 (Latest)-6
Retro Lite CM5 (Latest)-7
Retro Lite CM5 (Latest)-8
Retro Lite CM5 (Latest)-9
Retro Lite CM5 (Latest)-10

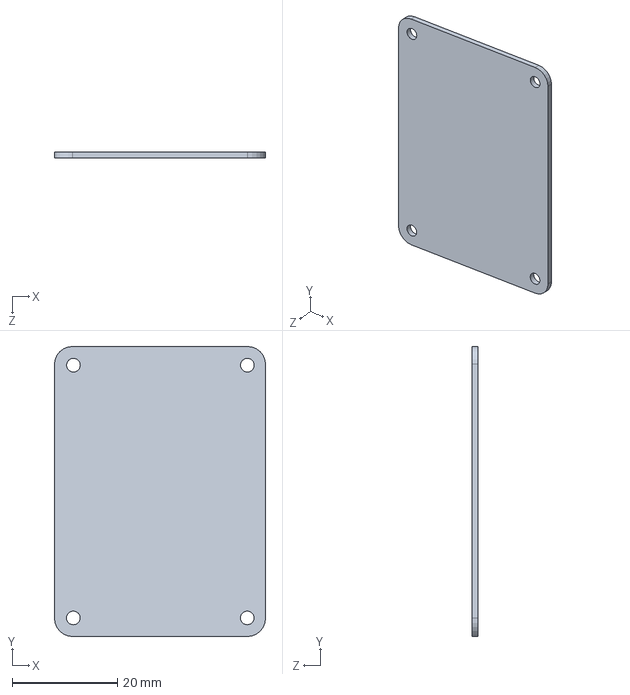
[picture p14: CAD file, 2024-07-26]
enclosure/Solidworks/Board_Geoms.SLDASM
40.0 x 55.0 x 1.20 mm

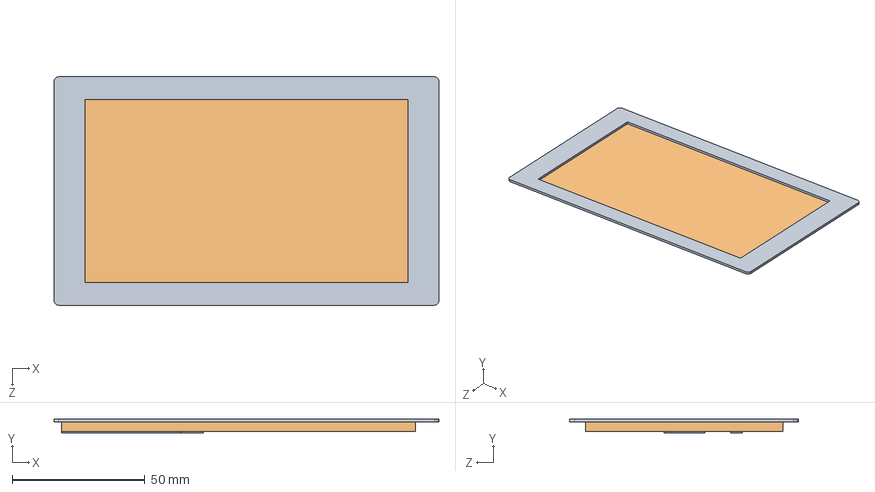
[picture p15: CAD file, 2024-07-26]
enclosure/Solidworks/5.5_ Touch Display MIPI.SLDASM
145.0 x 5.25 x 86.1 mm
CTP
5.5_ Touch Display MIPI-3
5.5_ Touch Display MIPI-4
5.5_ Touch Display MIPI-5

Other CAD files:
enclosure/STL_V2/Right Speaker Chamber Assembly.stl
enclosure/Solidworks/MirrorSpeaker Assembly (2).SLDASM
enclosure/Solidworks/AX210 PCIe Card.SLDASM
enclosure/Solidworks/Assembly Right PCB Controller.SLDASM
enclosure/STL_V2/A.stl
enclosure/STL_V2/B.stl
enclosure/STL_V2/Battery Bracket (5000mAh).stl
enclosure/STL_V2/Battery Bracket (8000mAh).stl
enclosure/STL_V2/Button Rotation Stopper Bracket.stl
enclosure/STL_V2/Button Spacers.stl
enclosure/STL_V2/Case Front (OLED) - Fix outer surface face.stl
enclosure/STL_V2/Case Front (OLED).stl
enclosure/STL_V2/Case Front.stl
enclosure/STL_V2/Case Rear (Smaller Vent Holes).stl
enclosure/STL_V2/Case Rear.stl
enclosure/STL_V2/DPAD.stl
enclosure/STL_V2/Fan Bracket.stl
enclosure/STL_V2/Left Speaker Chamber Bottom.stl
enclosure/STL_V2/Left Speaker Chamber Top.stl
enclosure/STL_V2/Left Speaker Cover.stl
enclosure/STL_V2/Minus Hotkey.stl
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

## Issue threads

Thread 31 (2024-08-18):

Changing pins breaks rp2040 controller

micahvdm, 2024-08-18:
Let me start by saying this is a fantastic project! I’m reusing the rp2040 Gamepad code for my own device, but when I change the pins, then some of the buttons stop working…in particular the R3 button. Are there any other references where the button pins are set that could cause this?

StonedEdge, 2024-08-28:
I will leave this one to @ginkage. Currently we're investigating the R3 shenanigans actually, as I also too had some issues with it freezing the controller with some new firmware.

ginkage, 2024-08-28:
@micahvdm The pins are defined here: https://github.com/StonedEdge/Retro-Lite-CM5/blob/main/rp2040_gamepad/src/gamepad.cpp#L8-L36 and it's the only place, really.
The only reason R3 could misbehave in that code is when HotkeyPlus is pressed at the same time, other than that it's kind of unlikely. What pin are you trying to use, maybe it's mapped to some other function by default (e.g. UART or I2C or something)?

micahvdm, 2024-08-29:
@ginkage I've tried with the default pins as well as with pins that are not mapped to anything else (i2c/spi/uart). The issue happens before I press any buttons. I plugged into a windows machine and all the buttons register except R3. Wiring is good because I wrote a circuitpython code with the same pins and all the buttons work. Not sure why it’s not working…I’ve tried to compile on WSL, an ubuntu machine and a vm and all end with the same result…thought I’d post here as I’ve spent about 4days troubleshooting and still can’t find what going on…baffled is about where I’m at now

ginkage, 2024-09-06:
We've found the issue, will push the fix shortly.

Closed 2024-09-06.

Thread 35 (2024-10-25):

Radxa 10FHD DSI Display

pterodyne, 2024-10-25:
Im interested in using your carrier board to design around a tablet PC.  I have a Radxa FHD10 DSI display.  It appears as if it would be compatible from what I can tell, and uses a standard overlay available from Radxa.  Any thoughts before I endeavor down this path?  Ive denuded a Rockchip Rock 5C, but have 2xRadxaCM5 units.  They work great on CM4 carriers, but Im really wanting to use the DSI display for simplicity.  Dealing with HDMI cables is a PITA.  The Radxa carrier is far to large for my project.  Your carrier looks like it would be perfect.

If you have the time, let me know if you think it would work.

StonedEdge, 2024-10-30:
Sorry, not sure how this is related to our project, but please feel free to use whatever assets in the repository for your use case.

Closed 2024-10-30.

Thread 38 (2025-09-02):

No Main PCB Gerber

Botman64, 2025-09-02:
I have decided to go with the cm5 setup you have going on and noticed the CPL comes with this one already but the gerber folder for the main board is missing.

StonedEdge, 2025-09-09:
Indeed, looks like they were missing. I've generated them and uploaded them now.

Thanks.

Closed 2025-09-09.

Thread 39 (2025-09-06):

SCHEMATIC

nothing76, 2025-09-06:
The PDF files for the RP2040 folder are not available and no explanation has been given about it.
Please upload the pdf file.

StonedEdge, 2025-09-09:
Sorry, what explanation is needed? Can you be more specific? Do you mean schematics in the form of a PDF?

https://github.com/StonedEdge/Retro-Lite-CM5/tree/main/rp2040_gamepad/PCB/v1
The PCB files are here, all you need is a form of EAGLE to open them, or you can view them in an online schematic viewer.

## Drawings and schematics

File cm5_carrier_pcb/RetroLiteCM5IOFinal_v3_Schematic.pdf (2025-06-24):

15 15 | 16 | 16 17 17 | 18 | 18 19 19 | 20 | 20 21 21 | 22 | 22 23 23 | 24 | 24 25 25 | 26 | 26 27 27 | 28 | 28 29 29 | 30 | 30 31 31 | 32 | 32 33 33 | 34 | 34 35 35 | 36 | 36 37 37 | 38 | 38 39 39 | 40 | 40 41 41 | 42 | 42 43 43 | 44 | 44 45 45 | 46 | 46 47 47 | 48 | 48 49 49 | 50 | 50 51 51 | 52 | 52 53 53 | 54 | 54 55 55 | 56 | 56 57 57 | 58 | 58 59 59 | 60 | 60 61 61 | 62 | 62 63 63 | 64 | 64 65 65 | 66 | 66 67 67 | 68 | 68 69 69 | 70 | 70 71 71 | 72 | 72 73 73 | 74 | 74

A

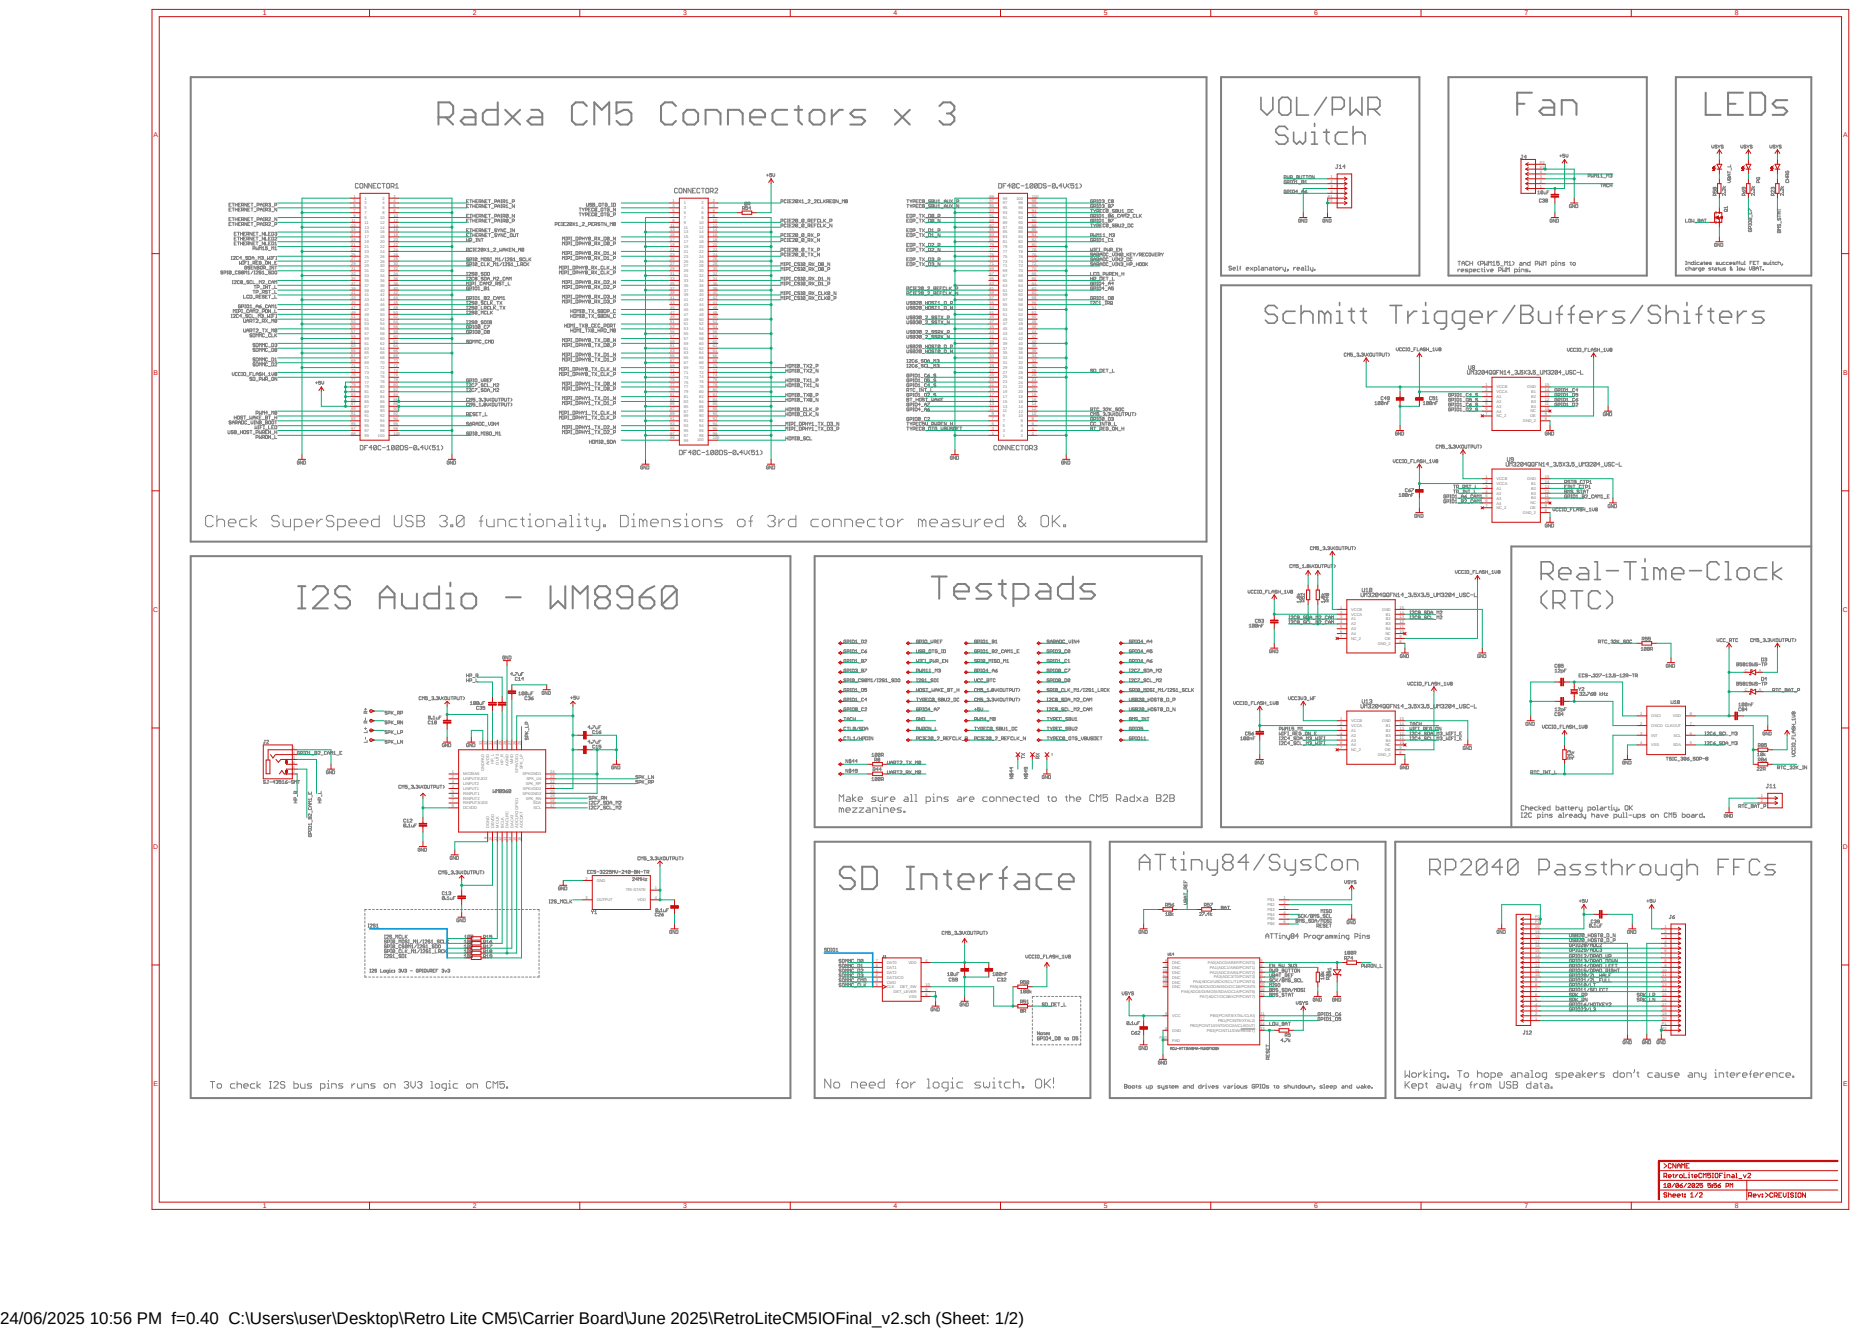
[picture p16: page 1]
MICBIAS 1 LINPUT3/JD2 2 LINPUT2 3 LINPUT1 4 RINPUT1 5 RINPUT2 6 RINPUT3/JD3 7; DCVDD 8; DGND; SCL; 17 SDA; 18 SPK_RN; 19 SPKGND2; 20 SPKVDD2; 21 SPK_RP; 22 SPK_LN; 23 SPKGND1; 24 SPK_LP ²⁵ SPKVDD¹ ²⁶ VMID ²⁷ AGND ²⁸ HP_R ²⁹ OUT3 30 HP_L 31 AVDD ³² GNDPAD ³³; TRI-STATE; VDD; 4 OUTPUT 3; GND 2; VCCB 1 VCCA 2 A1 3 A2 4 A3 5 A4 6 NC_2 7; GND_2; GND; DAT2 1 DAT3/CD 2 CMD 3; CLK 5; VSS; DAT0 7 DAT1 8; DET_LEVER; DET_SW; DNC 18 DNC 19; PB0(PCINT8/XTAL/CLKI) 11; PB2(PCINT10/INT0/OC0A/CLKOUT) 14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

9 DBVDD 10 MCLK 11 BCLK 12 DACLRC 13 DACAT 14 ADCLRC/GPIO1 15 ADCDAT 16

DNC 6
DNC 17 DNC 10 DNC 7

PA4(ADC4/USCK/SCL/T1/PCINT4) 1
PA5(ADC5/DO/MISO/OC1B/PCINT5 20
PA6(ADC6/DI/MOSI/SDA/OC1A/PCINT6) 16

24/06/2025 10:56 PM f=0.40 C:\Users\user\Desktop\Retro Lite CM5\Carrier Board\June 2025\RetroLiteCM5IOFinal_v2.sch (Sheet: 1/2)

A

A

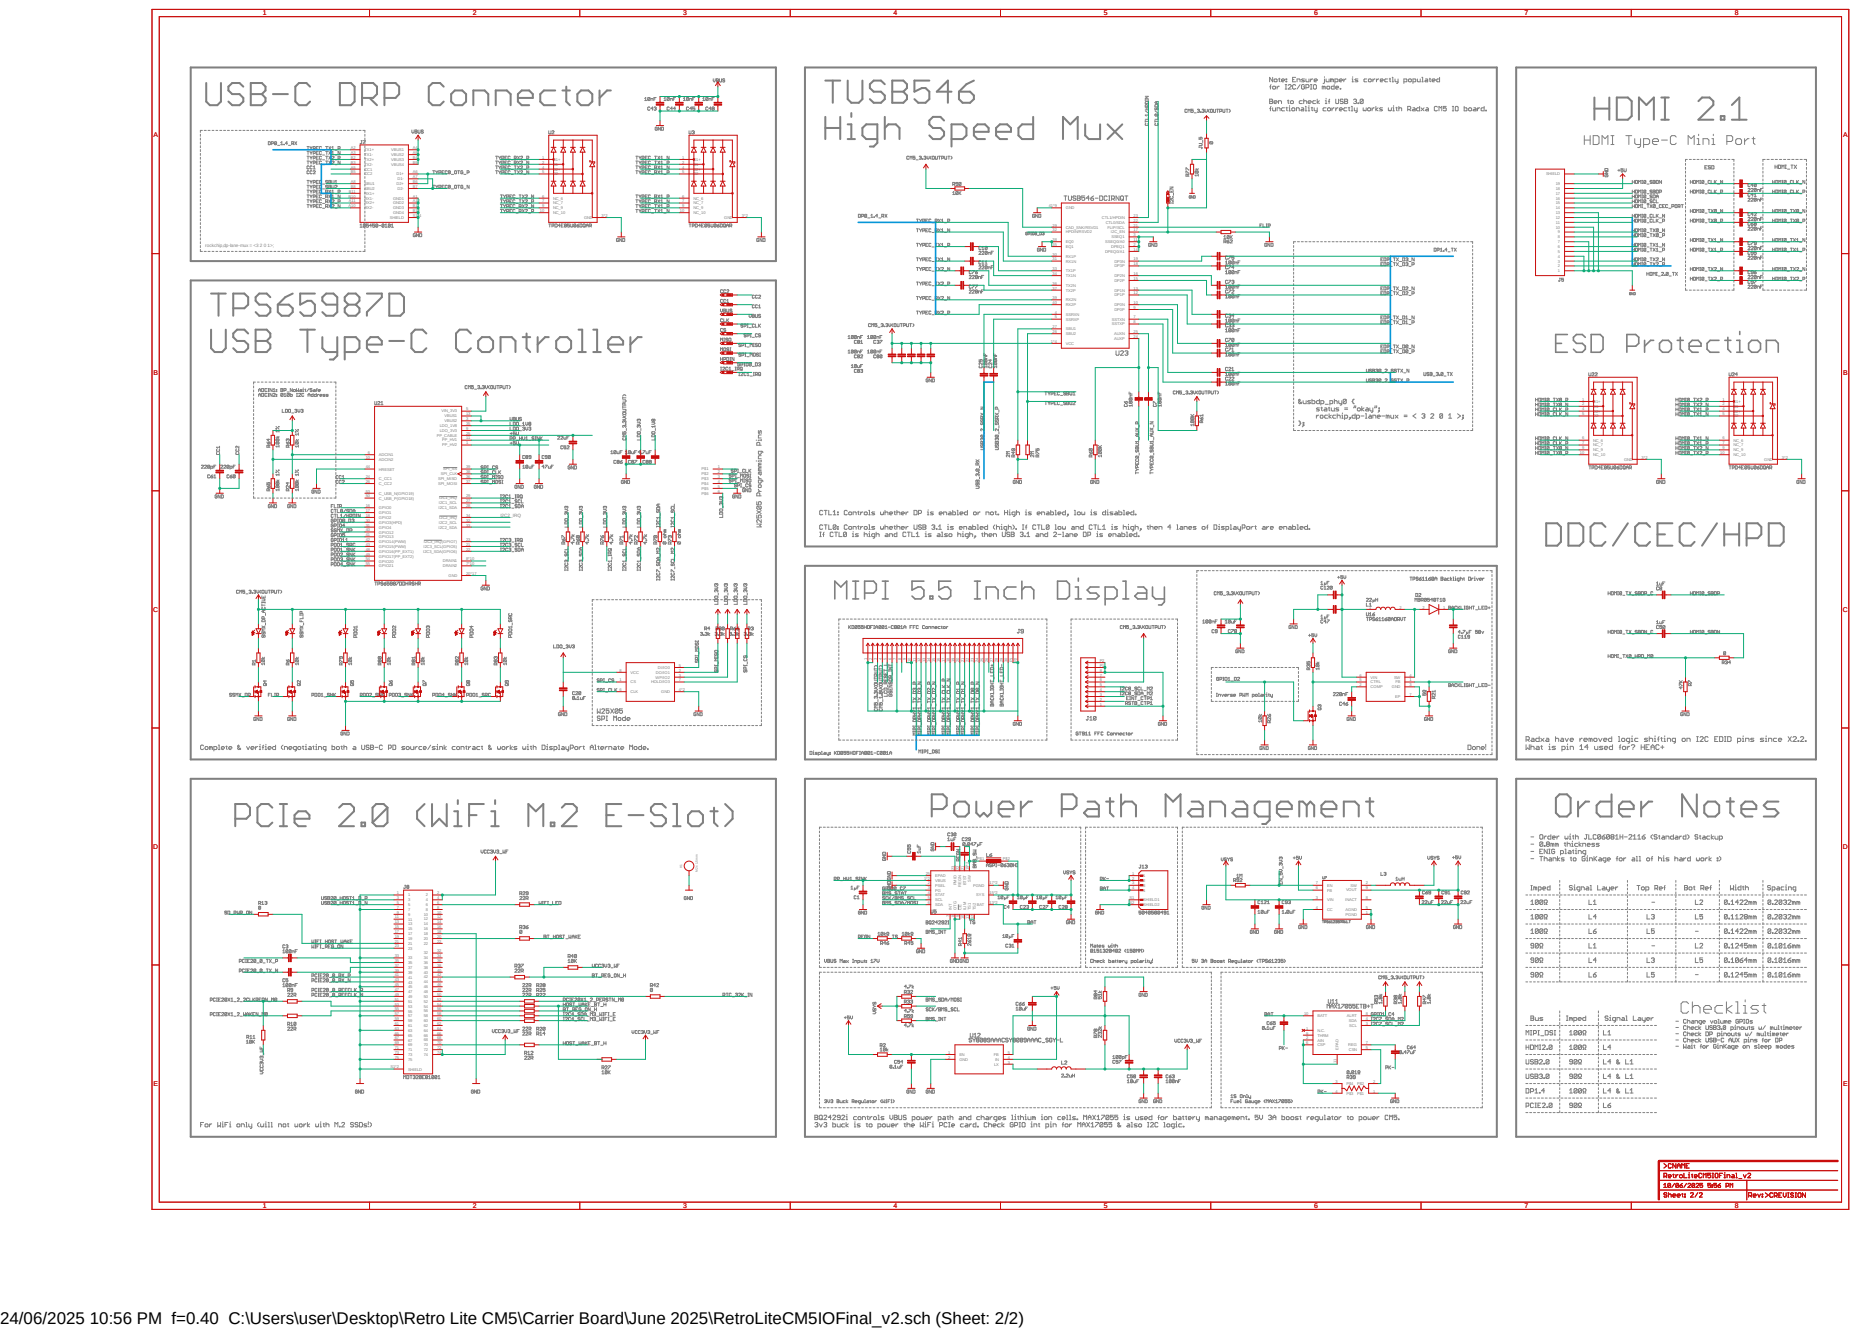
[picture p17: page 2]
ADCIN1 6 ADCIN2 10; C_USB_N(GPIO19) 53 C_USB_P(GPIO18) 50; DRAIN1; DRAIN2; GPIO0 16; GND; GPIO1 17 GPIO2 18 GPIO3(HPD) 30 GPIO4 31; I2C3_SCL(GPIO5); I2C3_SDA(GPIO6); I2C3_IRQ(GPIO7); GPIO12 40; GPIO14(PWM) 42; GPIO13 41; GPIO15(PWM) 43 GPIO16(PP_EXT1) 48 GPIO17(PP_EXT2) 49 GPIO20 54 GPIO21 55; HRESET 44; I2C1_IRQ; I2C1_SCL; I2C2_IRQ; I2C1_SDA; I2C2_SCL; I2C2_SDA; LDO_1V8; LDO_3V3; PP_CABLE; SPI_CLK; SPI_MOSI; 37 SPI_MISO; SPI_SS; VBUS1; VBUS2; VIN_3V3; DPEQ1; SSEQ1; SSRXN 4; SSRXP 5; SSTXN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

rockchip,dp-lane-mux = <3 2 0 1>;

24/06/2025 10:56 PM f=0.40 C:\Users\user\Desktop\Retro Lite CM5\Carrier Board\June 2025\RetroLiteCM5IOFinal_v2.sch (Sheet: 2/2)

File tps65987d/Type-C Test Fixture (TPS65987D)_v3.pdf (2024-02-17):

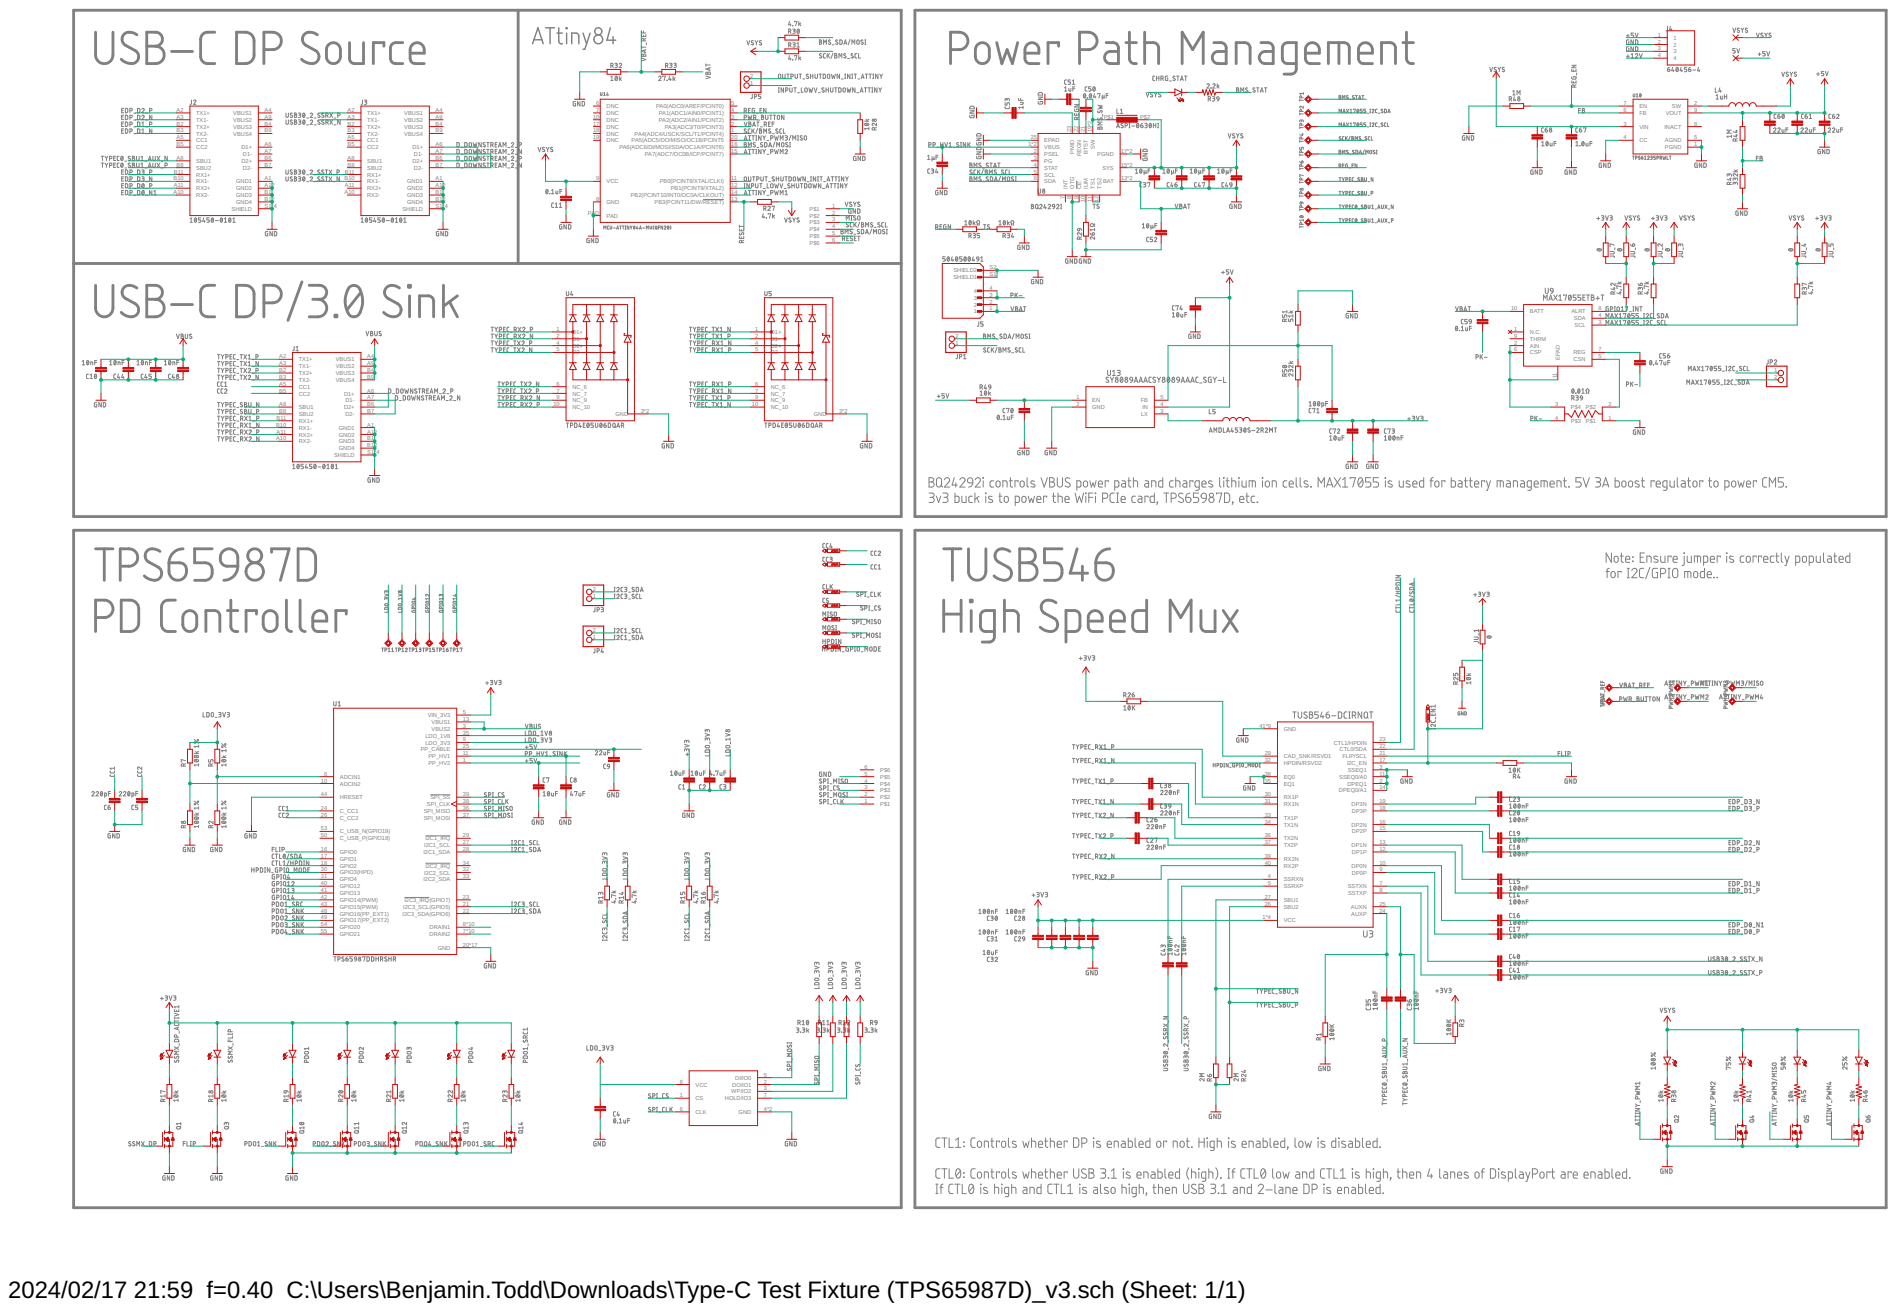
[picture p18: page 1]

2024/02/17 21:59 f=0.40 C:\Users\Benjamin.Todd\Downloads\Type-C Test Fixture (TPS65987D)_v3.sch (Sheet: 1/1)

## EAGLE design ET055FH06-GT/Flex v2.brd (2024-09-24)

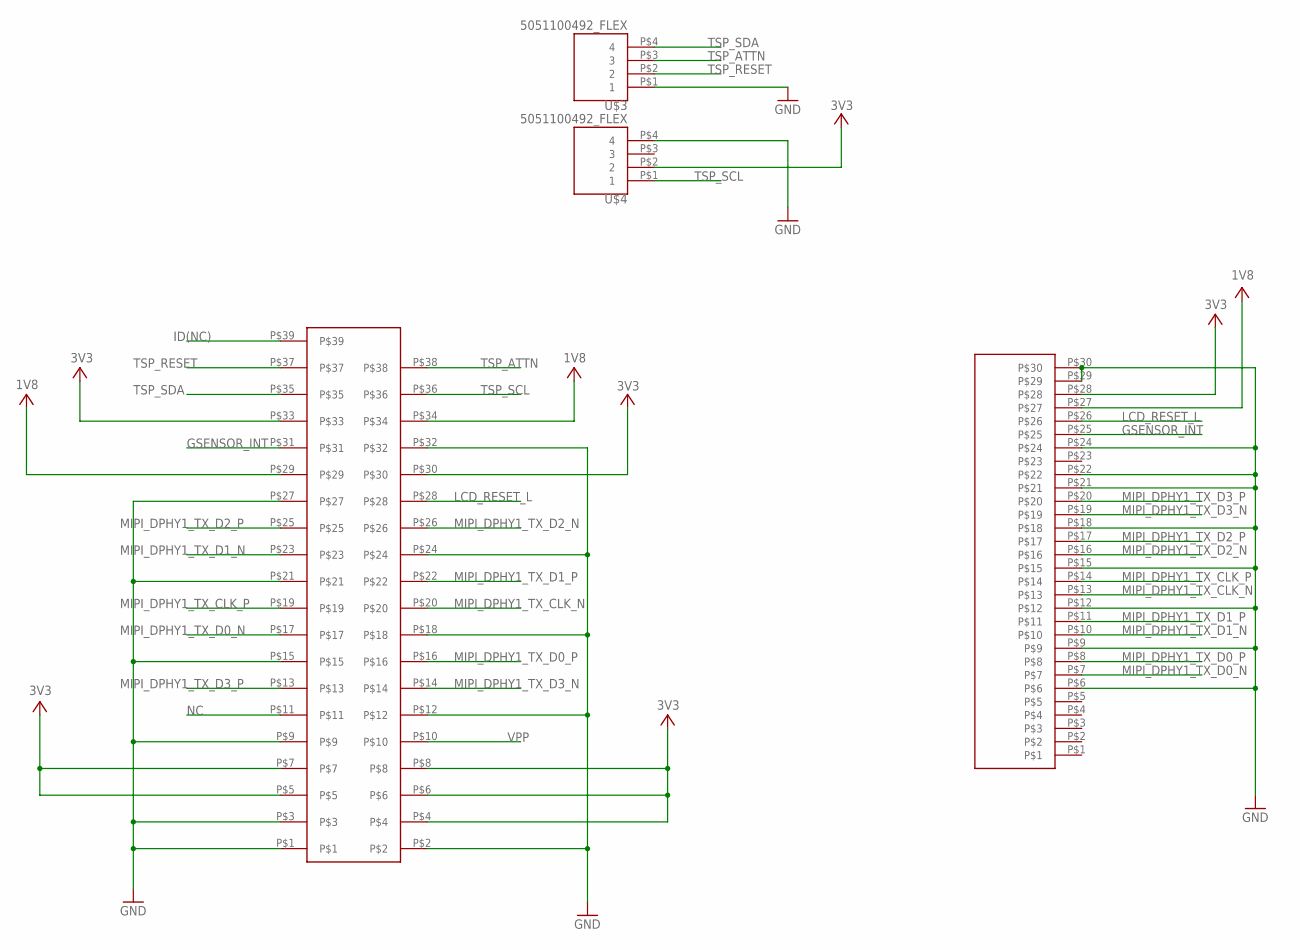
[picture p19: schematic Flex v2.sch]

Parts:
U$1: FH26-39S-0.3SHW_FLEX
U$2: 5051103091
U$3, U$4: 5051100492_FLEX

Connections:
1V8: U$1.P$29, U$1.P$34, U$2.P$27
3V3: U$1.P$4, U$1.P$5, U$1.P$6, U$1.P$7, U$1.P$8, U$1.P$30, U$1.P$33, U$2.P$28, U$4.P$2 (2)
GND: U$1.P$1, U$1.P$2, U$1.P$3, U$1.P$9, U$1.P$12, U$1.P$15, U$1.P$18, U$1.P$21, U$1.P$24, U$1.P$27, U$1.P$32, U$2.P$6, U$2.P$9, U$2.P$12, U$2.P$15, U$2.P$18, U$2.P$21, U$2.P$22, U$2.P$24, U$2.P$29, U$2.P$30, U$3.P$1 (1), U$4.P$4 (4)
GSENSOR_INT: U$1.P$31, U$2.P$25
ID(NC): U$1.P$39
LCD_RESET_L: U$1.P$28, U$2.P$26
MIPI_DPHY1_TX_CLK_N: U$1.P$20, U$2.P$13
MIPI_DPHY1_TX_CLK_P: U$1.P$19, U$2.P$14
MIPI_DPHY1_TX_D0_N: U$1.P$17, U$2.P$7
MIPI_DPHY1_TX_D0_P: U$1.P$16, U$2.P$8
MIPI_DPHY1_TX_D1_N: U$1.P$23, U$2.P$10
MIPI_DPHY1_TX_D1_P: U$1.P$22, U$2.P$11
MIPI_DPHY1_TX_D2_N: U$1.P$26, U$2.P$16
MIPI_DPHY1_TX_D2_P: U$1.P$25, U$2.P$17
MIPI_DPHY1_TX_D3_N: U$1.P$14, U$2.P$19
MIPI_DPHY1_TX_D3_P: U$1.P$13, U$2.P$20
NC: U$1.P$11
TSP_ATTN: U$1.P$38, U$3.P$3 (3)
TSP_RESET: U$1.P$37, U$3.P$2 (2)
TSP_SCL: U$1.P$36, U$4.P$1 (1)
TSP_SDA: U$1.P$35, U$3.P$4 (4)
VPP: U$1.P$10

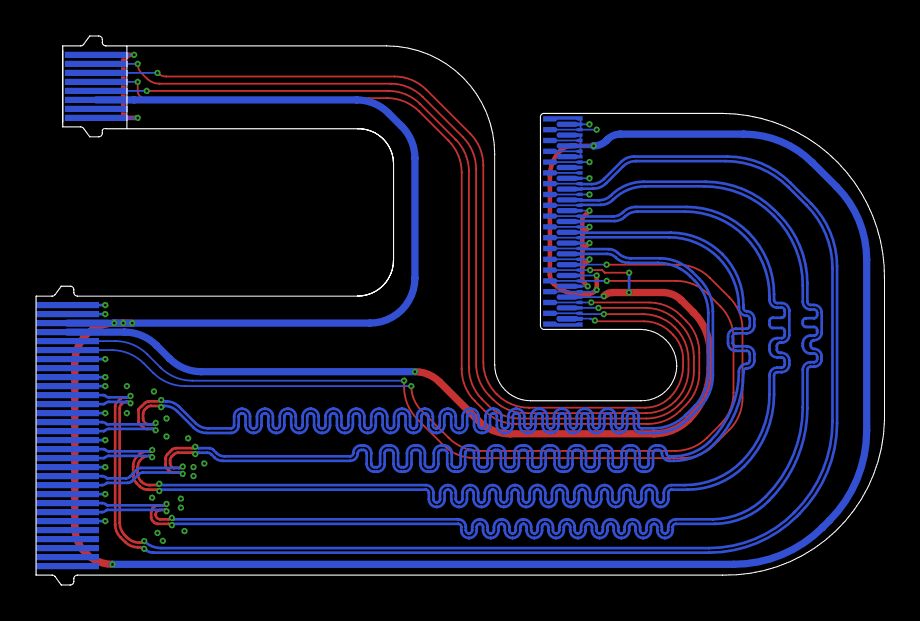
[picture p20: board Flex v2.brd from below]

Board: 2 copper layers, 47.1 x 30.5 mm, 4 parts (4 on the bottom side), 19 nets.

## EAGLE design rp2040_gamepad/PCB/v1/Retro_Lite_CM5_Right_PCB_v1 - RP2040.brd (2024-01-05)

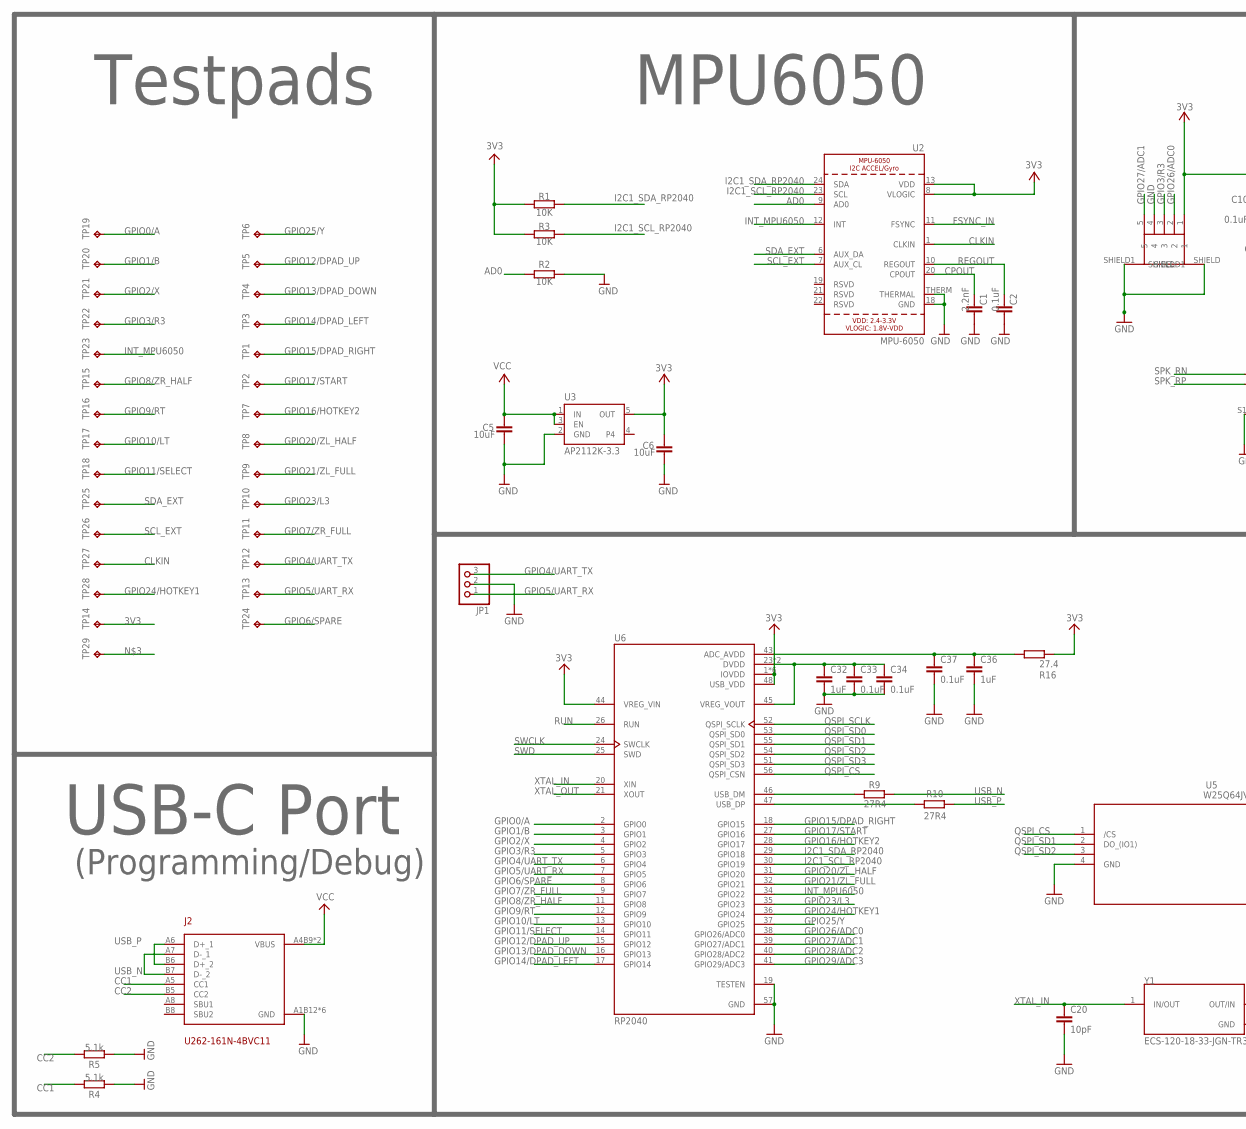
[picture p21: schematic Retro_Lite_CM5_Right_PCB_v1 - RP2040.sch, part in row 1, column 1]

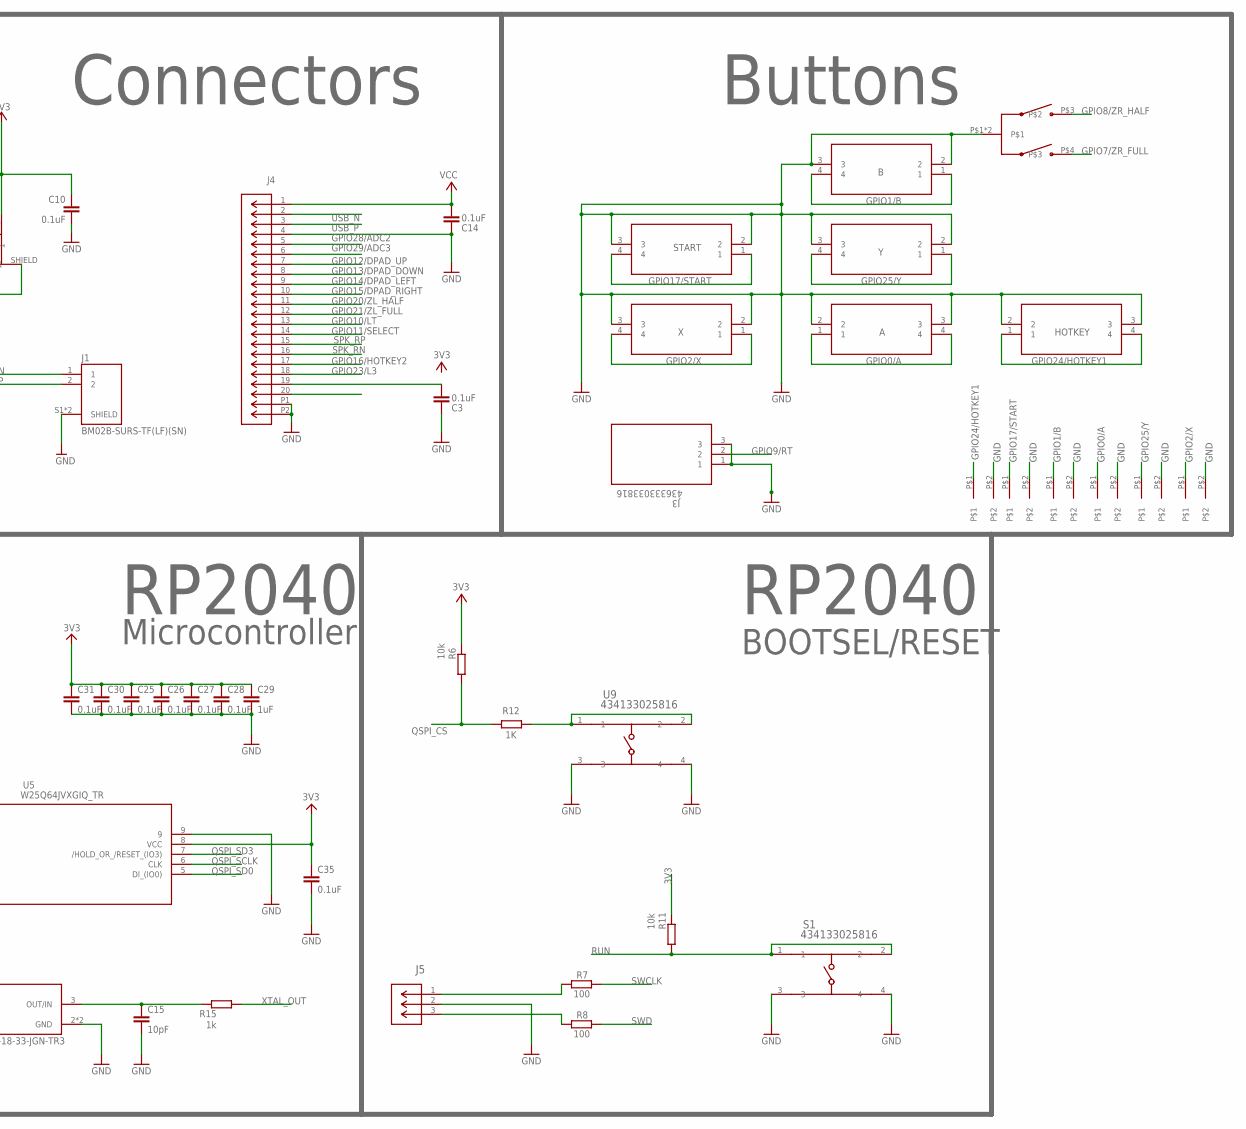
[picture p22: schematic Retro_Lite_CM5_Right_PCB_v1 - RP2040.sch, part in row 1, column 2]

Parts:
A: A; EVQQ2_3
AA: MEMBRANEBUTTON
B: B; EVQQ2_3
BB: MEMBRANEBUTTON
C1: 2.2nF; C0402
C2, C3, C10, C14, C25, C26, C27, C28, C30, C31, C33, C34, C35, C37: 0.1uF; C0402
C5, C6: 10uF; C0402
C15, C20: 10pF; C0402
C29, C32, C36: 1uF; C0402
HOTKEY: A; EVQQ2_3
J1: BM02B-SURS-TF(LF)(SN); JST_BM02B-SURS-TF(LF)(SN)
J2: U262-161N-4BVC11
J3: 436333033816; CONN3_3033816_WRE
J4: 5034802000; CON_5034802000_MOL
J5: BM03B-SRSS-TB(LF)(SN); CONN_BM03B-SRSS-TB(LF)(SN)_JST
JP1: PINHD-1X3; 1X03
R1, R2, R3: 10K; R0402
R4, R5: 5.1k; R0402
R6, R11: 10k; R0402
R7, R8: 100; R0402
R9, R10: 27R4; R0402
R12: 1K; R0402
R15: 1k; R0402
R16: 27.4; R0402
S1: 434133025816; SMD_025816_WRE
START: START; EVQQ2_3
START1: MEMBRANEBUTTON
T1: MEMBRANEBUTTON
TP1, TP2, TP3, TP4, TP5, TP6, TP7, TP8, TP9, TP10, TP11, TP12, TP13, TP14, TP15, TP16, TP17, TP18, TP19, TP20, TP21, TP22, TP23, TP24, TP25, TP26, TP27, TP28, TP29: TPTP07R; TP07R
U2: MPU-6050; QFN24_4MM_SMSC
U3: AP2112K-3.3; SOT23-5
U5: W25Q64JVXGIQ_TR; DFN_XGIQ_TR_WIN
U6: RP2040; QFN40P700X700X90-57N
U9: 434133025816; SMD_025816_WRE
U$1: SWITCHSTICK_BREAKOUT
U$2: TMHF07
X: X; EVQQ2_3
XX: MEMBRANEBUTTON
Y: Y; EVQQ2_3
Y1: ECS-120-18-33-JGN-TR3; XTAL_ECS-120-18-33-JGN-TR3
YY: MEMBRANEBUTTON

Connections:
3V3: C3.2, C6.1, C10.1, C25.1, C26.1, C27.1, C28.1, C29.1, C30.1, C31.1, C35.1, J4.19, R1.1, R3.1, R6.2, R11.2, R16.2, TP14.TP, U2.8 (VLOGIC), U2.13 (VDD), U3.5 (OUT), U5.8 (VCC), U6.1 (IOVDD), U6.10 (IOVDD), U6.22 (IOVDD), U6.33 (IOVDD), U6.42 (IOVDD), U6.44 (VREG_VIN), U6.48 (USB_VDD), U6.49 (IOVDD), U$1.1
AD0: R2.1, U2.9 (AD0)
CC1: J2.A5 (CC1), R4.2
CC2: J2.B5 (CC2), R5.2
CLKIN: TP27.TP, U2.1 (CLKIN)
CPOUT: C1.1, U2.20 (CPOUT)
FSYNC_IN: U2.11 (FSYNC)
GND: A.2, A.3, AA.P$2, B.2, B.3, BB.P$2, C1.2, C2.2, C3.1, C5.2, C6.2, C10.2, C14.1, C15.2, C20.2, C25.2, C26.2, C27.2, C28.2, C29.2, C30.2, C31.2, C32.2, C33.2, C34.2, C35.2, C36.2, C37.2, HOTKEY.2, HOTKEY.3, J1.S1 (SHIELD), J1.S2 (SHIELD), J2.A1B12 (GND), J2.B1A12 (GND), J2.SHIELD_1 (GND), J2.SHIELD_2 (GND), J2.SHIELD_3 (GND), J2.SHIELD_4 (GND), J3.1, J3.3, J4.4, J4.P1, J4.P2, J5.2, JP1.2, R2.2, R4.1, R5.1, S1.3, S1.4, START.2, START.3, START1.P$2, T1.P$2, U2.18 (GND), U2.THERM (THERMAL), U3.2 (GND), U5.4 (GND), U5.9, U6.19 (TESTEN), U6.57 (GND), U9.3, U9.4, U$1.4, U$1.SHIELD, U$1.SHIELD1, U$2.P$1, U$2.P$2, X.2, X.3, XX.P$2, Y.2, Y.3, Y1.2 (GND), Y1.4 (GND), YY.P$2
GPIO0/A: A.1, A.4, AA.P$1, TP19.TP, U6.2 (GPIO0)
GPIO1/B: B.1, B.4, BB.P$1, TP20.TP, U6.3 (GPIO1)
GPIO2/X: TP21.TP, U6.4 (GPIO2), X.1, X.4, XX.P$1
GPIO3/R3: TP22.TP, U6.5 (GPIO3), U$1.3
GPIO4/UART_TX: JP1.3, TP12.TP, U6.6 (GPIO4)
GPIO5/UART_RX: JP1.1, TP13.TP, U6.7 (GPIO5)
GPIO6/SPARE: TP24.TP, U6.8 (GPIO6)
GPIO7/ZR_FULL: TP11.TP, U6.9 (GPIO7), U$2.P$4
GPIO8/ZR_HALF: TP15.TP, U6.11 (GPIO8), U$2.P$3
GPIO9/RT: J3.2, TP16.TP, U6.12 (GPIO9)
GPIO10/LT: J4.13, TP17.TP, U6.13 (GPIO10)
GPIO11/SELECT: J4.14, TP18.TP, U6.14 (GPIO11)
GPIO12/DPAD_UP: J4.7, TP5.TP, U6.15 (GPIO12)
GPIO13/DPAD_DOWN: J4.8, TP4.TP, U6.16 (GPIO13)
GPIO14/DPAD_LEFT: J4.9, TP3.TP, U6.17 (GPIO14)
GPIO15/DPAD_RIGHT: J4.10, TP1.TP, U6.18 (GPIO15)
GPIO16/HOTKEY2: J4.17, TP7.TP, U6.28 (GPIO17)
GPIO17/START: START.1, START.4, START1.P$1, TP2.TP, U6.27 (GPIO16)
GPIO20/ZL_HALF: J4.11, TP8.TP, U6.31 (GPIO20)
GPIO21/ZL_FULL: J4.12, TP9.TP, U6.32 (GPIO21)
GPIO23/L3: J4.18, TP10.TP, U6.35 (GPIO23)
GPIO24/HOTKEY1: HOTKEY.1, HOTKEY.4, T1.P$1, TP28.TP, U6.36 (GPIO24)
GPIO25/Y: TP6.TP, U6.37 (GPIO25), Y.1, Y.4, YY.P$1
GPIO26/ADC0: U6.38 (GPIO26/ADC0), U$1.2
GPIO27/ADC1: U6.39 (GPIO27/ADC1), U$1.5
GPIO28/ADC2: J4.5, U6.40 (GPIO28/ADC2)
GPIO29/ADC3: J4.6, U6.41 (GPIO29/ADC3)
I2C1_SCL_RP2040: R3.2, U2.23 (SCL), U6.30 (GPIO19)
I2C1_SDA_RP2040: R1.2, U2.24 (SDA), U6.29 (GPIO18)
INT_MPU6050: TP23.TP, U2.12 (INT), U6.34 (GPIO22)
unnamed: C15.1, R15.2, Y1.3 (OUT/IN)
unnamed: J5.1, R7.1
unnamed: J4.20, TP29.TP
unnamed: J5.3, R8.1
unnamed: C32.1, C33.1, C34.1, U6.23 (DVDD), U6.45 (VREG_VOUT), U6.50 (DVDD)
unnamed: R9.2, U6.46 (USB_DM)
unnamed: R10.2, U6.47 (USB_DP)
unnamed: R12.1, U9.1, U9.2
unnamed: C36.1, C37.1, R16.1, U6.43 (ADC_AVDD)
QSPI_CS: R6.1, R12.2, U5.1 (/CS), U6.56 (QSPI_CSN)
QSPI_SCLK: U5.6 (CLK), U6.52 (QSPI_SCLK)
QSPI_SD0: U5.5 (DI_(IO0)), U6.53 (QSPI_SD0)
QSPI_SD1: U5.2 (DO_(IO1)), U6.55 (QSPI_SD1)
QSPI_SD2: U5.3 (/WP_(IO2)), U6.54 (QSPI_SD2)
QSPI_SD3: U5.7 (/HOLD_OR_/RESET_(IO3)), U6.51 (QSPI_SD3)
REGOUT: C2.1, U2.10 (REGOUT)
RUN: R11.1, S1.1, S1.2, U6.26 (RUN)
SCL_EXT: TP26.TP, U2.7 (AUX_CL)
SDA_EXT: TP25.TP, U2.6 (AUX_DA)
SPK_RN: J1.1, J4.16
SPK_RP: J1.2, J4.15
SWCLK: R7.2, U6.24 (SWCLK)
SWD: R8.2, U6.25 (SWD)
USB_N: J2.A7 (D-_1), J2.B7 (D-_2), J4.2, R9.1
USB_P: J2.A6 (D+_1), J2.B6 (D+_2), J4.3, R10.1
VCC: C5.1, C14.2, J2.A4B9 (VBUS), J2.B4A9 (VBUS), J4.1, U3.1 (IN), U3.3 (EN)
XTAL_IN: C20.1, U6.20 (XIN), Y1.1 (IN/OUT)
XTAL_OUT: R15.1, U6.21 (XOUT)

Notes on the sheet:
MPU6050
RP2040
Buttons
Connectors
USB-C Port
Testpads
(Programming/Debug)
Microcontroller
BOOTSEL/RESET

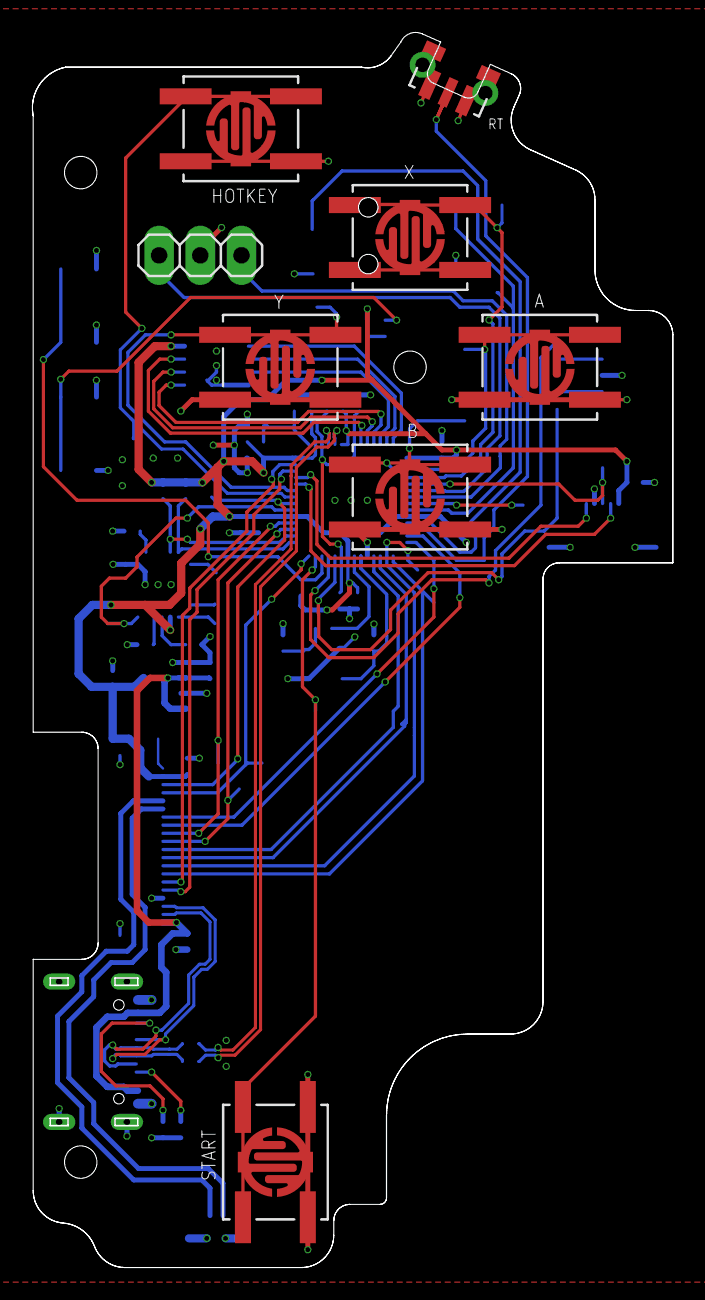
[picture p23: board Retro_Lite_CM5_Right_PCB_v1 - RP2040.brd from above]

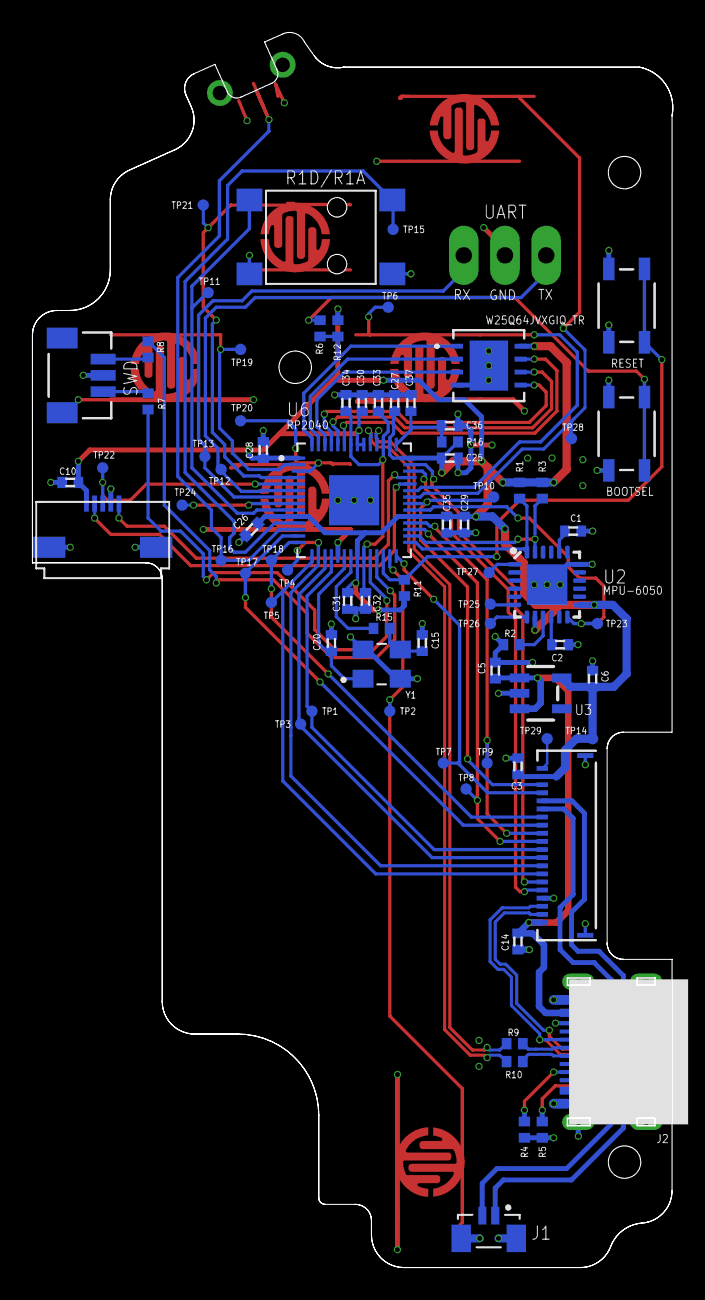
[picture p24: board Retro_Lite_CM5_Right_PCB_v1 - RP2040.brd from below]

Board: 2 copper layers, 39.5 x 76.1 mm, 92 parts (78 on the bottom side), 65 nets.

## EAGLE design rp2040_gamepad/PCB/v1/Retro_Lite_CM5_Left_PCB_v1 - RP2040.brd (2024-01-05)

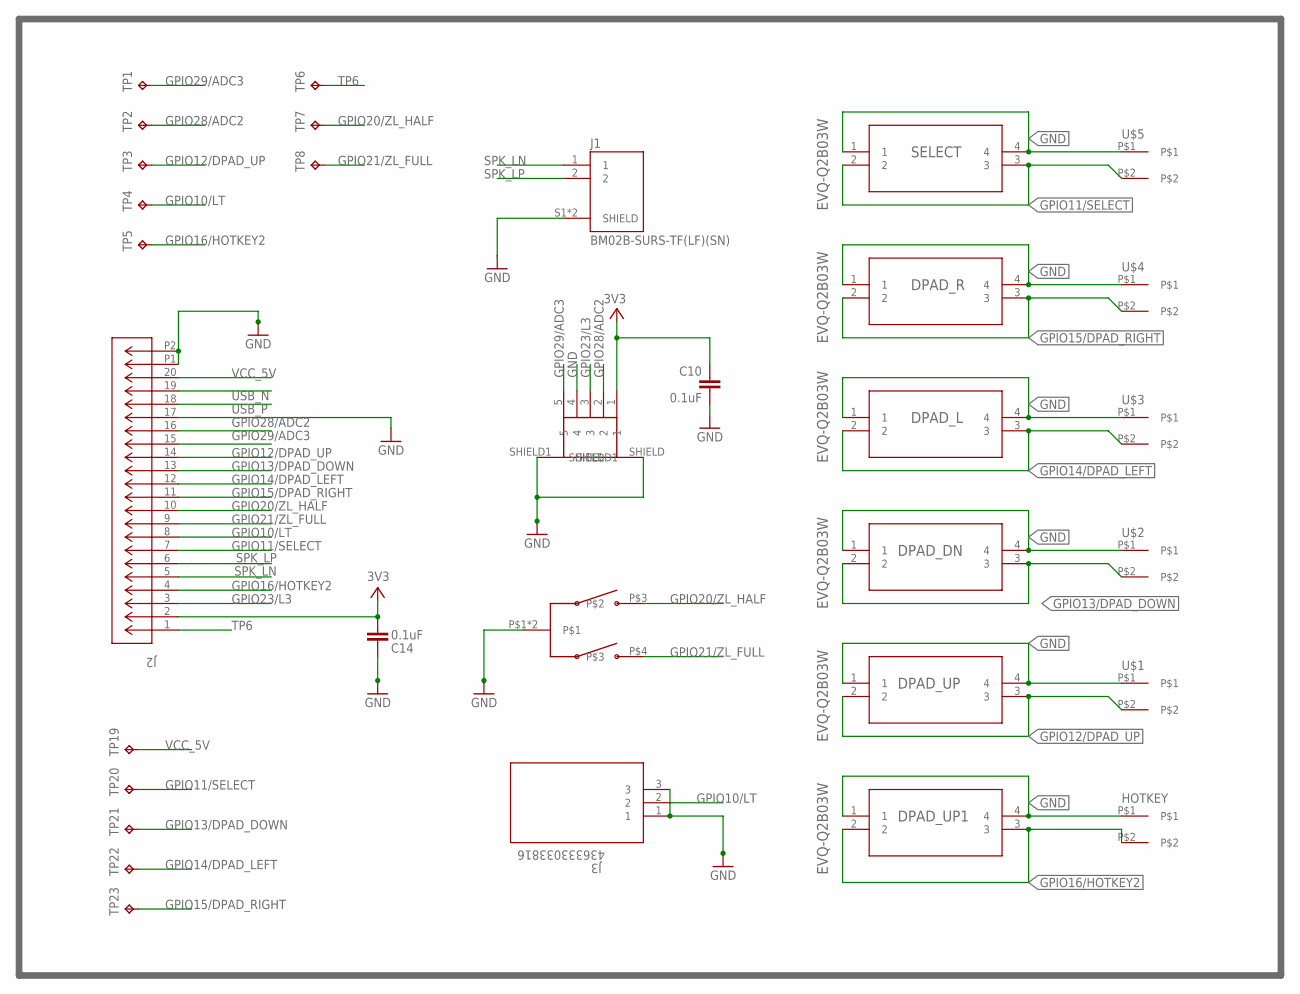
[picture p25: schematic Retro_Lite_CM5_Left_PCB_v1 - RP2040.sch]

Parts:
C10, C14: 0.1uF; C0402
DPAD_DN: EVQ-Q2B03W; EVQQ2_3
DPAD_L: EVQ-Q2B03W; EVQQ2_3
DPAD_R: EVQ-Q2B03W; EVQQ2_3
DPAD_UP, DPAD_UP1: EVQ-Q2B03W; EVQQ2_3
HOTKEY: MEMBRANEBUTTON
J1: BM02B-SURS-TF(LF)(SN); JST_BM02B-SURS-TF(LF)(SN)
J2: 5034802000; CON_5034802000_MOL
J3: 436333033816; CONN3_3033816_WRE
SELECT: EVQ-Q2B03W; EVQQ2_3
TP1, TP2, TP3, TP4, TP5, TP6, TP7, TP8, TP19, TP20, TP21, TP22, TP23: TPTP07R; TP07R
U$1, U$2, U$3, U$4, U$5: MEMBRANEBUTTON
U$7: SWITCHSTICK_BREAKOUT
U$8: TMHF07

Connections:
3V3: C10.1, C14.2, J2.2, U$7.1
GND: C10.2, C14.1, DPAD_DN.1, DPAD_DN.4, DPAD_L.1, DPAD_L.4, DPAD_R.1, DPAD_R.4, DPAD_UP.1, DPAD_UP.4, DPAD_UP1.1, DPAD_UP1.4, HOTKEY.P$1, J1.S1 (SHIELD), J1.S2 (SHIELD), J2.17, J2.P1, J2.P2, J3.1, J3.3, SELECT.1, SELECT.4, U$1.P$1, U$2.P$1, U$3.P$1, U$4.P$1, U$5.P$1, U$7.4, U$7.SHIELD, U$7.SHIELD1, U$8.P$1, U$8.P$2
GPIO10/LT: J2.8, J3.2, TP4.TP
GPIO11/SELECT: J2.7, SELECT.2, SELECT.3, TP20.TP, U$5.P$2
GPIO12/DPAD_UP: DPAD_UP.2, DPAD_UP.3, J2.14, TP3.TP, U$1.P$2
GPIO13/DPAD_DOWN: DPAD_DN.2, DPAD_DN.3, J2.13, TP21.TP, U$2.P$2
GPIO14/DPAD_LEFT: DPAD_L.2, DPAD_L.3, J2.12, TP22.TP, U$3.P$2
GPIO15/DPAD_RIGHT: DPAD_R.2, DPAD_R.3, J2.11, TP23.TP, U$4.P$2
GPIO16/HOTKEY2: DPAD_UP1.2, DPAD_UP1.3, HOTKEY.P$2, J2.4, TP5.TP
GPIO20/ZL_HALF: J2.10, TP7.TP, U$8.P$3
GPIO21/ZL_FULL: J2.9, TP8.TP, U$8.P$4
GPIO23/L3: J2.3, U$7.3
GPIO28/ADC2: J2.16, TP2.TP, U$7.2
GPIO29/ADC3: J2.15, TP1.TP, U$7.5
SPK_LN: J1.1, J2.5
SPK_LP: J1.2, J2.6
TP6: J2.1, TP6.TP
USB_N: J2.19
USB_P: J2.18
VCC_5V: J2.20, TP19.TP

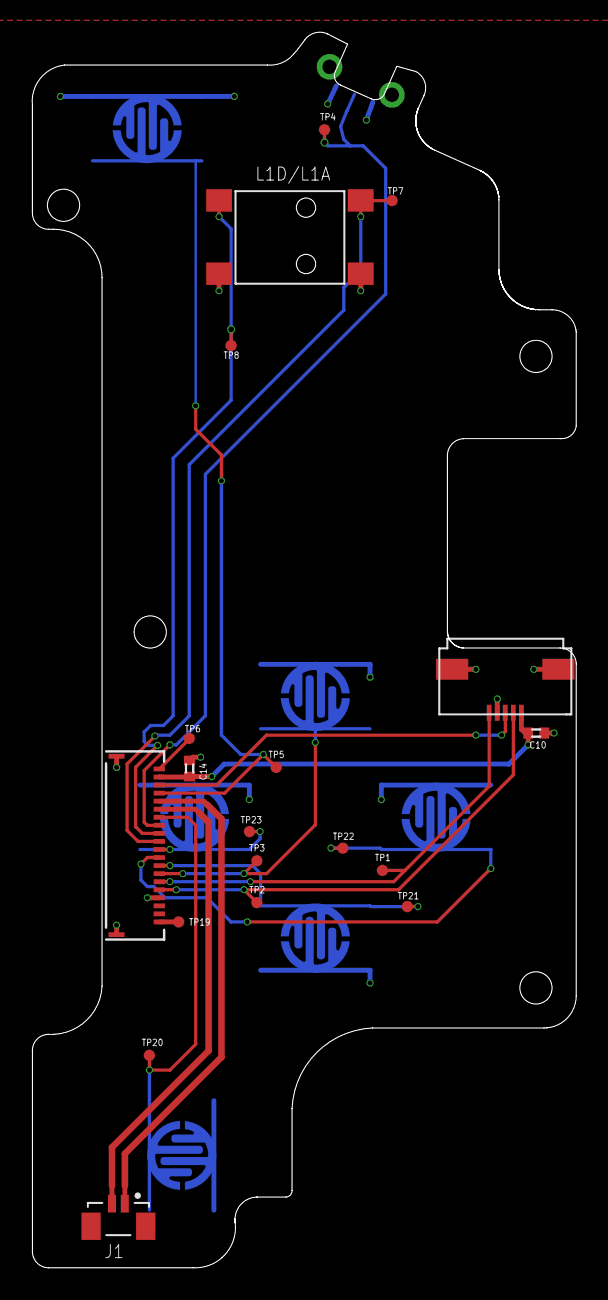
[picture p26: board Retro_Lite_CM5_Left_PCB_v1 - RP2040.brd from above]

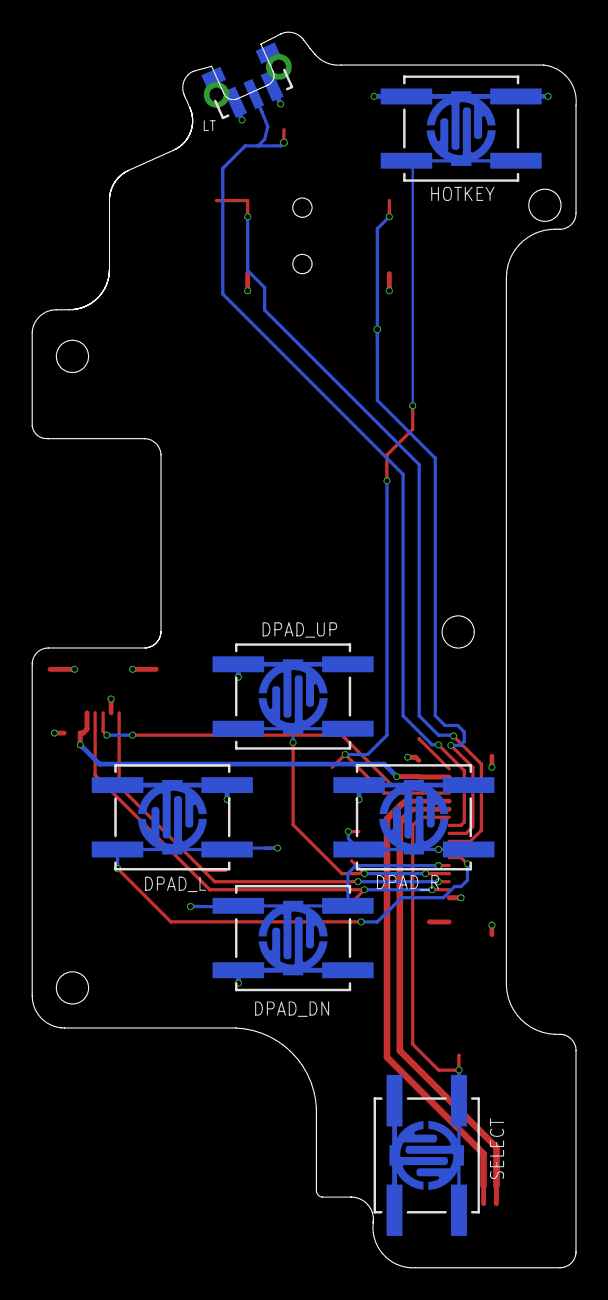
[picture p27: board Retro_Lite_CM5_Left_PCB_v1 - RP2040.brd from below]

Board: 2 copper layers, 33.8 x 76.7 mm, 32 parts (13 on the bottom side), 18 nets.

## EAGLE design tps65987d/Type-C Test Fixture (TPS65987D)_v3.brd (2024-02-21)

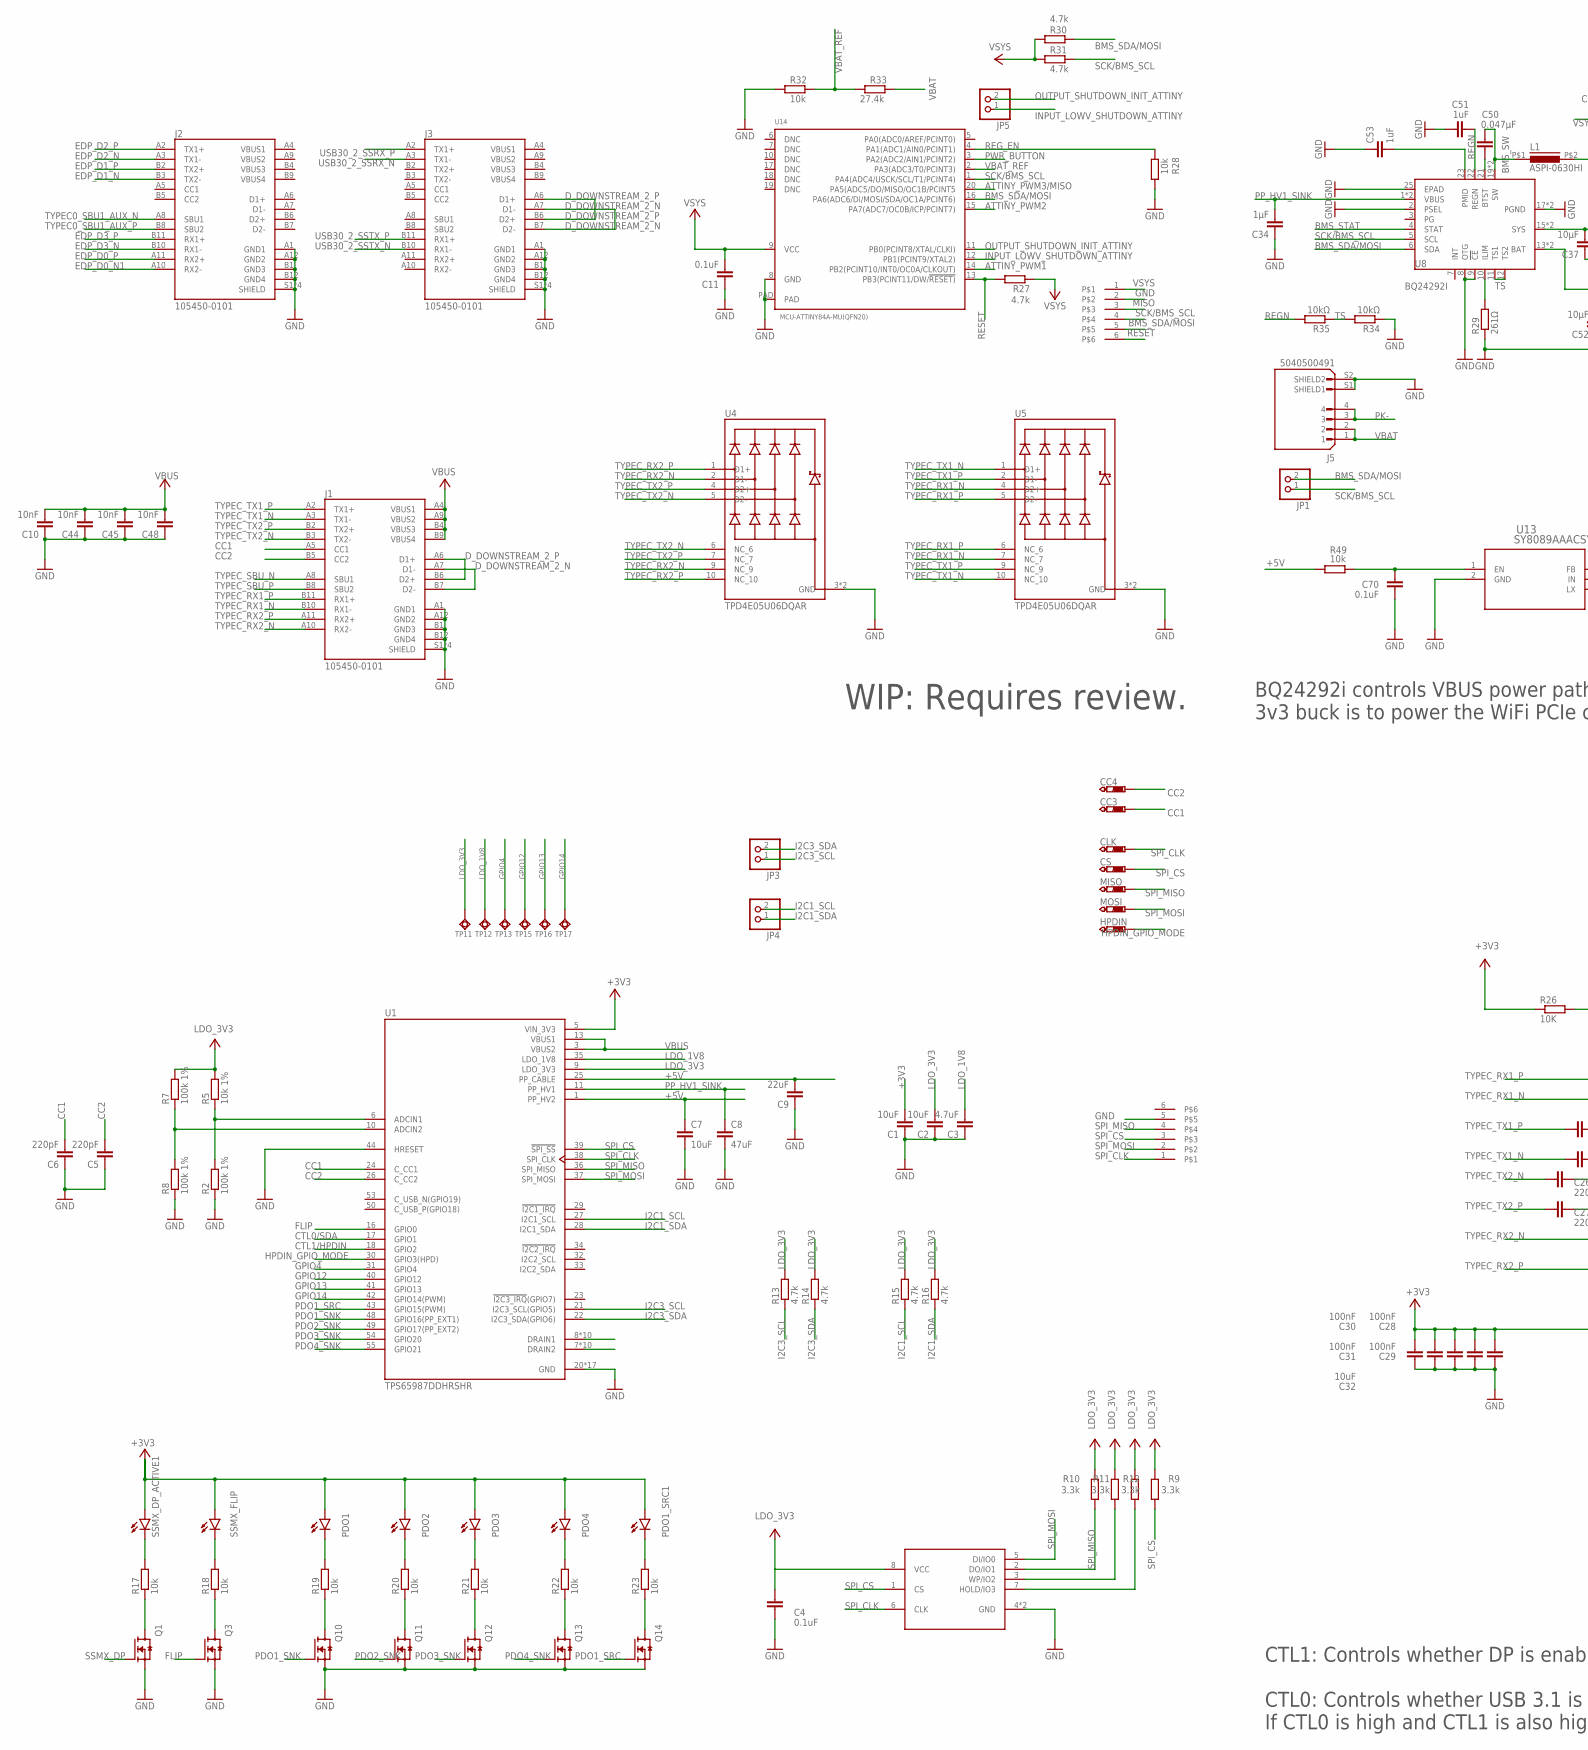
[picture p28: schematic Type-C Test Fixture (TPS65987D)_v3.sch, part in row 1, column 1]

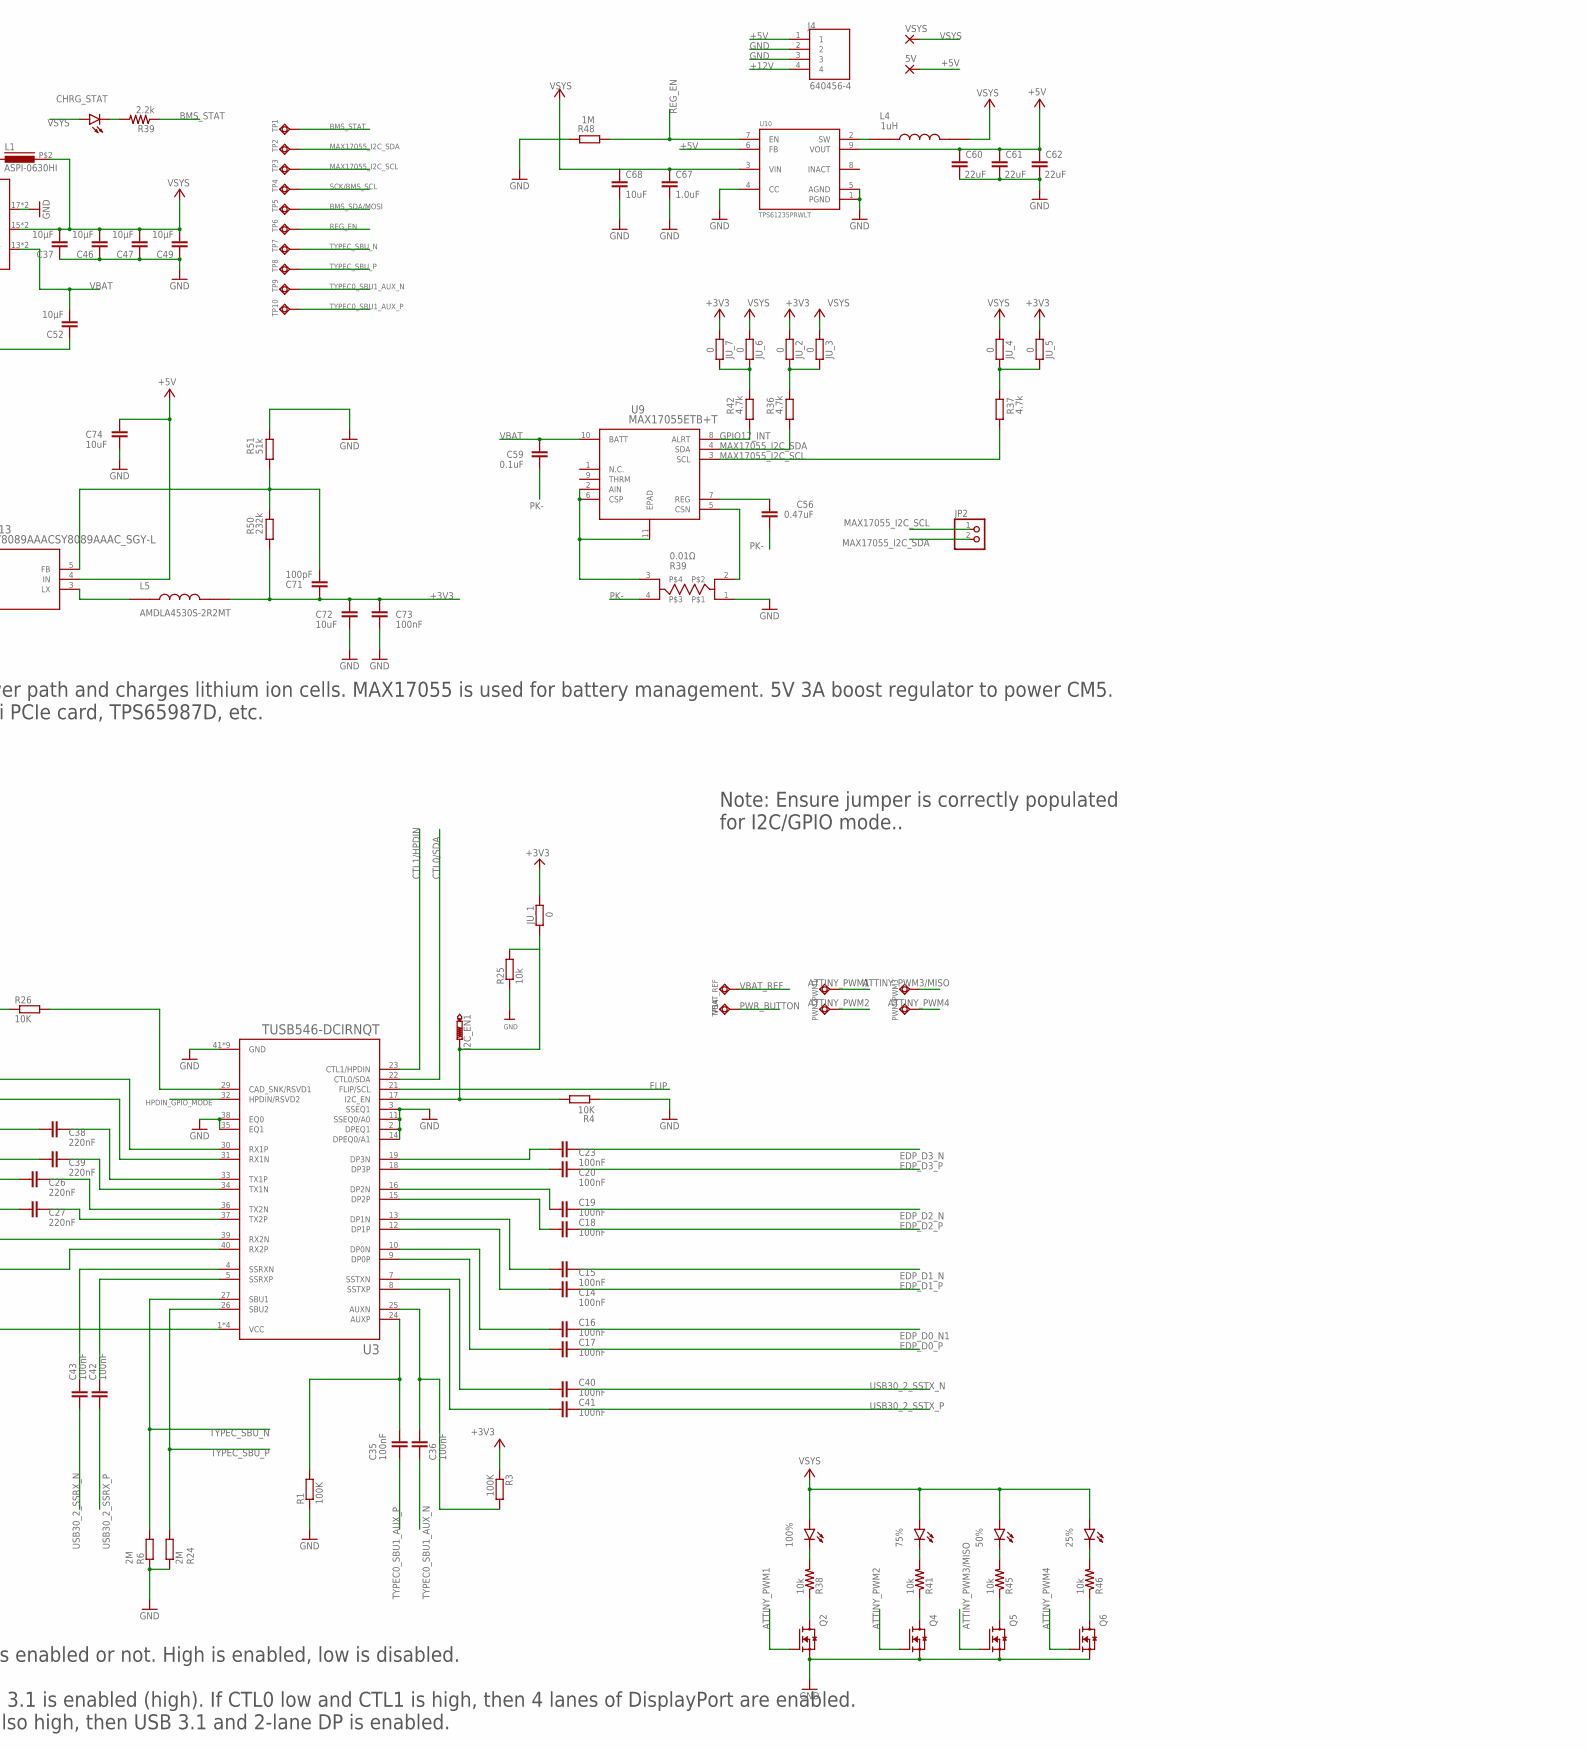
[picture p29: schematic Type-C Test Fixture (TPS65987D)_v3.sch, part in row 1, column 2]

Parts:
5V: SMD5; SMD2,54-5,08
25%, 50%, 75%, 100%: LEDSML0603; SML0603
C1, C2, C7, C72, C74: 10uF; C0402
C3: 4.7uF; C0402
C4, C11, C59, C70: 0.1uF; C0402
C5, C6: 220pF; C0402
C8: 47uF; C0603
C9: 22uF; C0402
C10, C44, C45, C48: 10nF; C0805
C14, C15, C16, C17, C18, C19, C20, C23, C28, C29, C30, C31, C35, C36, C40, C41, C42, C43, C73: 100nF; C0402
C26, C27, C38, C39: 220nF; C0402
C32: 10uF; C0805
C34: 1µF; C0805
C37, C46, C47, C49, C52: 10µF; C0805
C50: 0.047µF; C0603
C51, C53: 1uF; C0603
C56: 0.47uF; C0402
C60, C61, C62: 22uF; 0805
C67: 1.0uF; 0603
C68: 10uF; 0603
C71: 100pF; C0402
CC3, CC4: PTR1TP07R; TP07R
CHRG_STAT: LEDSML0603; SML0603
CLK: PTR1TP07R; TP07R
CS: PTR1TP07R; TP07R
HPDIN: PTR1TP07R; TP07R
I2C_EN1: PTR1TP07R; TP07R
J1, J2, J3: 105450-0101; MOLEX_105450-0101
J4: 640456-4; TE_640456-4
J5: 5040500491; MOLEX_5040500491
JP1, JP2, JP3, JP4, JP5: PINHD-1X2; 1X02
JU_1, JU_2, JU_3, JU_4, JU_5, JU_6, JU_7: 0; R0402
L1: ASPI-0630HI
L4: 1uH; IND_SPM5020T-1R0M
L5: AMDLA4530S-2R2MT; IND_AMDLA4530S-2R2MT
MISO: PTR1TP07R; TP07R
MOSI: PTR1TP07R; TP07R
PDO1, PDO1_SRC1, PDO2, PDO3, PDO4: LEDSML0603; SML0603
PWM1, PWM2, PWM3, PWM4: TPSQTP07R; TP07R
Q1, Q2, Q3, Q4, Q5, Q6, Q10, Q11, Q12, Q13, Q14: AO3400A; SOT95P280X125-3N
R1, R3: 100K; R0402
R2, R7, R8: 100k 1%; R0402
R4, R26: 10K; R0402
R5: 10k 1%; R0402
R6, R24: 2M; R0402
R9, R10, R11, R12: 3.3k; R0402
R13, R14, R15, R16, R27, R30, R31, R36, R37, R42: 4.7k; R0402
R17, R18, R19, R20, R21, R22, R23, R25, R28, R32, R49: 10k; R0402
R29: 261Ω; R0402
R33: 27.4k; R0402
R34: 10kΩ; R0402
R35: 10kΩ; R0603
R38, R41, R45, R46: 10k; R0201
R39: 2.2k; R0201
R40: PS0306DRF7T0R01L
R48: 1M; R0402
R50: 232k; R0402
R51: 51k; R0402
SSMX_DP_ACTIVE1: LEDSML0603; SML0603
SSMX_FLIP_ACTIVE1: SSMX_FLIP; SML0603
TP1, TP2, TP3, TP4, TP5, TP6, TP7, TP8, TP9, TP10, TP11, TP12, TP13, TP14, TP15, TP16, TP17: TPSQTP07R; TP07R
U1: TPS65987DDHRSHR; IC_TPS65987DDHRSHR
U2: W25X05CLUXIGTR; PSON50P300X200X60-9N
U3: TUSB546-DCIRNQT; QFN40P400X600X80-41N
U4, U5: TPD4E05U06DQAR; IC_TPD4E05U06DQAR
U8: BQ24292I; QFN50P400X400X100-25N
U9: MAX17055ETB+T; 21-100013A_T102A2+1C_MXM
U10: TPS61235PRWLT; CONV_TPS61235PRWLT
U13: SY8089AAACSY8089AAAC_SGY-L; SY8089AAAC_SGY-L
U14: MCU-ATTINY84A-MU(QFN20); QFN20G-0.5-4X4MM
U$3, U$5: 6PINEADER; 1MM_PIC-PROGRAMING_HEADER
VBAT_REF: TPSQTP07R; TP07R
VSYS: SMD5; SMD2,54-5,08

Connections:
+3V3: C1.2, C28.2, C29.2, C30.2, C31.2, C32.2, C71.1, C72.1, C73.1, JU_1.2, JU_2.1, JU_5.1, JU_7.1, L5.2, PDO1.A, PDO1_SRC1.A, PDO2.A, PDO3.A, PDO4.A, R3.1, R26.1, R50.2, SSMX_DP_ACTIVE1.A, SSMX_FLIP_ACTIVE1.A, U1.5 (VIN_3V3), U3.1 (VCC), U3.6 (VCC), U3.20 (VCC), U3.28 (VCC)
+5V: 5V.1, C7.1, C9.2, C60.1, C61.1, C62.1, C74.1, J4.1, R49.2, U1.1 (PP_HV2), U1.25 (PP_CABLE), U10.6 (FB), U10.9 (VOUT), U13.4 (IN)
+12V: J4.4
ATTINY_PWM1: PWM1.TP, Q2.1 (G), U14.14 (PB2(PCINT10/INT0/OC0A/CLKOUT))
ATTINY_PWM2: PWM2.TP, Q4.1 (G), U14.15 (PA7(ADC7/OC0B/ICP/PCINT7))
ATTINY_PWM3/MISO: PWM3.TP, Q5.1 (G), U14.20 (PA5(ADC5/DO/MISO/OC1B/PCINT5)
ATTINY_PWM4: PWM4.TP, Q6.1 (G)
BMS_SDA/MOSI: JP1.2, R30.2, TP5.TP, U8.6 (SDA), U14.16 (PA6(ADC6/DI/MOSI/SDA/OC1A/PCINT6)), U$5.5
BMS_STAT: R39.1, TP1.TP, U8.4 (STAT)
BMS_SW: C50.1, L1.P$1 (1), U8.19 (SW), U8.20 (SW)
CC1: C6.2, CC3.TP, J1.A5 (CC1), U1.24 (C_CC1)
CC2: C5.2, CC4.TP, J1.B5 (CC2), U1.26 (C_CC2)
CTL0/SDA: U1.17 (GPIO1), U3.22 (CTL0/SDA)
CTL1/HPDIN: U1.18 (GPIO2), U3.23 (CTL1/HPDIN)
D_DOWNSTREAM_2_N: J1.A7 (D1-), J1.B7 (D2-), J3.A7 (D1-), J3.B7 (D2-)
D_DOWNSTREAM_2_P: J1.A6 (D1+), J1.B6 (D2+), J3.A6 (D1+), J3.B6 (D2+)
EDP_D0_N1: C16.1, C16.2, J2.A10 (RX2-), U3.10 (DP0N)
EDP_D0_P: C17.1, C17.2, J2.A11 (RX2+), U3.9 (DP0P)
EDP_D1_N: C15.1, C15.2, J2.B3 (TX2-), U3.13 (DP1N)
EDP_D1_P: C14.1, C14.2, J2.B2 (TX2+), U3.12 (DP1P)
EDP_D2_N: C19.1, C19.2, J2.A3 (TX1-), U3.16 (DP2N)
EDP_D2_P: C18.1, C18.2, J2.A2 (TX1+), U3.15 (DP2P)
EDP_D3_N: C23.1, C23.2, J2.B10 (RX1-), U3.19 (DP3N)
EDP_D3_P: C20.1, C20.2, J2.B11 (RX1+), U3.18 (DP3P)
FLIP: Q3.1 (G), U1.16 (GPIO0), U3.21 (FLIP/SCL)
GND: C1.1, C2.1, C3.1, C4.1, C5.1, C6.1, C7.2, C8.2, C9.1, C10.1, C11.1, C28.1, C29.1, C30.1, C31.1, C32.1, C34.1, C37.1, C44.1, C45.1, C46.1, C47.1, C48.1, C49.1, C51.1, C52.1, C53.1, C60.2, C61.2, C62.2, C67.2, C68.2, C70.2, C72.2, C73.2, C74.2, J1.A1 (GND1), J1.A12 (GND2), J1.B1 (GND3), J1.B12 (GND4), J1.S1 (SHIELD), J1.S2 (SHIELD), J1.S3 (SHIELD), J1.S4 (SHIELD), J2.A1 (GND1), J2.A12 (GND2), J2.B1 (GND3), J2.B12 (GND4), J2.S1 (SHIELD), J2.S2 (SHIELD), J2.S3 (SHIELD), J2.S4 (SHIELD), J3.A1 (GND1), J3.A12 (GND2), J3.B1 (GND3), J3.B12 (GND4), J3.S1 (SHIELD), J3.S2 (SHIELD), J3.S3 (SHIELD), J3.S4 (SHIELD), J4.2, J4.3, J5.S1 (SHIELD1), J5.S2 (SHIELD2), Q1.2 (S), Q2.2 (S), Q3.2 (S), Q4.2 (S), Q5.2 (S), Q6.2 (S), Q10.2 (S), Q11.2 (S), Q12.2 (S), Q13.2 (S), Q14.2 (S), R1.1, R2.1, R4.1, R6.1, R8.1, R24.1, R25.1, R28.1, R29.1, R32.1, R34.1, R40.1, R48.1, R51.1, U1.20 (GND), U1.44 (HRESET), U1.45 (GND), U1.46 (GND), U1.47 (GND), U1.51 (GND), U1.59 (GND), U1.59_1 (GND), U1.59_2 (GND), U1.59_3 (GND), U1.59_4 (GND), U1.59_5 (GND), U1.59_6 (GND), U1.59_7 (GND), U1.59_8 (GND), U1.59_9 (GND), U1.59_10 (GND), U1.59_11 (GND), U2.4 (GND), U2.9 (GND), U3.2 (DPEQ1), U3.3 (SSEQ1), U3.11 (SSEQ0/A0), U3.14 (DPEQ0/A1), U3.35 (EQ1), U3.38 (EQ0), U3.41 (GND), U3.42 (GND), U3.43 (GND), U3.44 (GND), U3.45 (GND), U3.46 (GND), U3.47 (GND), U3.48 (GND), U3.49 (GND), U4.3 (GND), U4.8 (GND), U5.3 (GND), U5.8 (GND), U8.2 (PSEL), U8.8 (OTG), U8.9 (!CE), U8.17 (PGND), U8.18 (PGND), U8.25 (EPAD), U10.1 (PGND), U10.4 (CC), U10.5 (AGND), U13.2 (GND), U14.8 (GND), U14.PAD, U$3.5, U$5.2
GPIO4: TP13.TP, U1.31 (GPIO4)
GPIO12: TP15.TP, U1.40 (GPIO12)
GPIO13: TP16.TP, U1.41 (GPIO13)
GPIO14: TP17.TP, U1.42 (GPIO14(PWM))
GPIO17_INT: R42.2, U9.8 (ALRT)
HPDIN_GPIO_MODE: HPDIN.TP, U1.30 (GPIO3(HPD)), U3.32 (HPDIN/RSVD2)
I2C1_SCL: JP4.2, R15.1, U1.27 (I2C1_SCL)
I2C1_SDA: JP4.1, R16.1, U1.28 (I2C1_SDA)
I2C3_SCL: JP3.1, R13.1, U1.21 (I2C3_SCL(GPIO5))
I2C3_SDA: JP3.2, R14.1, U1.22 (I2C3_SDA(GPIO6))
INPUT_LOWV_SHUTDOWN_ATTINY: JP5.1, U14.12 (PB1(PCINT9/XTAL2))
LDO_1V8: C3.2, TP12.TP, U1.35 (LDO_1V8)
LDO_3V3: C2.2, C4.2, R5.2, R7.2, R9.2, R10.2, R11.2, R12.2, R13.2, R14.2, R15.2, R16.2, TP11.TP, U1.9 (LDO_3V3), U2.8 (VCC)
MAX17055_I2C_SCL: JP2.1, R37.2, TP3.TP, U9.3 (SCL)
MAX17055_I2C_SDA: JP2.2, R36.2, TP2.TP, U9.4 (SDA)
MISO: U$5.3
unnamed: R2.2, R5.1, U1.6 (ADCIN1)
unnamed: I2C_EN1.TP, JU_1.1, R4.2, R25.2, U3.17 (I2C_EN)
unnamed: R7.1, R8.2, U1.10 (ADCIN2)
unnamed: R26.2, U3.29 (CAD_SNK/RSVD1)
unnamed: JU_6.2, JU_7.2, R42.1
unnamed: JU_2.2, JU_3.2, R36.1
unnamed: JU_4.2, JU_5.2, R37.1
unnamed: C50.2, U8.21 (BTST)
unnamed: U1.8 (DRAIN1), U1.15 (DRAIN1), U1.19 (DRAIN1), U1.58 (DRAIN1), U1.58_1 (DRAIN1), U1.58_2 (DRAIN1), U1.58_3 (DRAIN1), U1.58_4 (DRAIN1), U1.58_5 (DRAIN1), U1.58_6 (DRAIN1)
unnamed: R29.2, U8.10 (ILIM)
unnamed: C53.2, U8.23 (PMID)
unnamed: U1.7 (DRAIN2), U1.52 (DRAIN2), U1.56 (DRAIN2), U1.57 (DRAIN2), U1.57_1 (DRAIN2), U1.57_2 (DRAIN2), U1.57_3 (DRAIN2), U1.57_4 (DRAIN2), U1.57_5 (DRAIN2), U1.57_6 (DRAIN2)
unnamed: R11.1, U2.3 (WP/IO2)
unnamed: R12.1, U2.7 (HOLD/IO3)
unnamed: R17.2, SSMX_DP_ACTIVE1.C
unnamed: R18.2, SSMX_FLIP_ACTIVE1.C
unnamed: Q1.3 (D), R17.1
unnamed: L4.1, U10.2 (SW)
unnamed: Q3.3 (D), R18.1
unnamed: PDO1.C, R19.2
unnamed: PDO2.C, R20.2
unnamed: PDO3.C, R21.2
unnamed: PDO4.C, R22.2
unnamed: PDO1_SRC1.C, R23.2
unnamed: Q14.3 (D), R23.1
unnamed: Q13.3 (D), R22.1
unnamed: Q12.3 (D), R21.1
unnamed: Q10.3 (D), R19.1
unnamed: Q11.3 (D), R20.1
unnamed: C56.1, U9.7 (REG)
unnamed: R40.2, U9.5 (CSN)
unnamed: R40.3, U9.2 (AIN), U9.6 (CSP), U9.11 (EPAD)
unnamed: C70.1, R49.1, U13.1 (EN)
unnamed: L5.1, U13.3 (LX)
unnamed: C71.2, R50.1, R51.2, U13.5 (FB)
unnamed: C36.2, R3.2, U3.25 (AUXN)
unnamed: C35.2, R1.2, U3.24 (AUXP)
unnamed: CHRG_STAT.C, R39.2
unnamed: 100%.C, R38.2
unnamed: 75%.C, R41.2
unnamed: 50%.C, R45.2
unnamed: 25%.C, R46.2
unnamed: Q2.3 (D), R38.1
unnamed: Q4.3 (D), R41.1
unnamed: Q5.3 (D), R45.1
unnamed: Q6.3 (D), R46.1
OUTPUT_SHUTDOWN_INIT_ATTINY: JP5.2, U14.11 (PB0(PCINT8/XTAL/CLKI))
PDO1_SNK: Q10.1 (G), U1.48 (GPIO16(PP_EXT1))
PDO1_SRC: Q14.1 (G), U1.43 (GPIO15(PWM))
PDO2_SNK: Q11.1 (G), U1.49 (GPIO17(PP_EXT2))
PDO3_SNK: Q12.1 (G), U1.54 (GPIO20)
PDO4_SNK: Q13.1 (G), U1.55 (GPIO21)
PK-: C56.2, C59.2, J5.3, J5.4, R40.4
PP_HV1_SINK: C8.1, C34.2, U1.11 (PP_HV1), U8.1 (VBUS), U8.24 (VBUS)
PWR_BUTTON: TP14.TP, U14.3 (PA2(ADC2/AIN1/PCINT2))
REGN: C51.2, R35.2, U8.22 (REGN)
REG_EN: R28.2, R48.2, TP6.TP, U10.7 (EN), U14.4 (PA1(ADC1/AIN0/PCINT1))
RESET: R27.2, U14.13 (PB3(PCINT11/DW/!RESET)), U$5.6
SCK/BMS_SCL: JP1.1, R31.2, TP4.TP, U8.5 (SCL), U14.1 (PA4(ADC4/USCK/SCL/T1/PCINT4)), U$5.4
SPI_CLK: CLK.TP, U1.38 (SPI_CLK), U2.6 (CLK), U$3.1
SPI_CS: CS.TP, R9.1, U1.39 (!SPI_SS), U2.1 (CS), U$3.3
SPI_MISO: MISO.TP, R10.1, U1.36 (SPI_MISO), U2.2 (DO/IO1), U$3.4
SPI_MOSI: MOSI.TP, U1.37 (SPI_MOSI), U2.5 (DI/IO0), U$3.2
SSMX_DP: Q1.1 (G)
TS: R34.2, R35.1, U8.11 (TS1), U8.12 (TS2)
TYPEC0_SBU1_AUX_N: C36.1, J2.A8 (SBU1), TP9.TP
TYPEC0_SBU1_AUX_P: C35.1, J2.B8 (SBU2), TP10.TP
TYPEC_RX1_N: J1.B10 (RX1-), U3.31 (RX1N), U5.4 (D2+), U5.7 (NC_7)
TYPEC_RX1_P: J1.B11 (RX1+), U3.30 (RX1P), U5.5 (D2-), U5.6 (NC_6)
TYPEC_RX2_N: J1.A10 (RX2-), U3.39 (RX2N), U4.2 (D1-), U4.9 (NC_9)
TYPEC_RX2_P: J1.A11 (RX2+), U3.40 (RX2P), U4.1 (D1+), U4.10 (NC_10)
TYPEC_SBU_N: J1.A8 (SBU1), R6.2, TP7.TP, U3.27 (SBU1)
TYPEC_SBU_P: J1.B8 (SBU2), R24.2, TP8.TP, U3.26 (SBU2)
TYPEC_TX1_N: C39.1, C39.2, J1.A3 (TX1-), U3.34 (TX1N), U5.1 (D1+), U5.10 (NC_10)
TYPEC_TX1_P: C38.1, C38.2, J1.A2 (TX1+), U3.33 (TX1P), U5.2 (D1-), U5.9 (NC_9)
TYPEC_TX2_N: C26.1, C26.2, J1.B3 (TX2-), U3.36 (TX2N), U4.5 (D2-), U4.6 (NC_6)
TYPEC_TX2_P: C27.1, C27.2, J1.B2 (TX2+), U3.37 (TX2P), U4.4 (D2+), U4.7 (NC_7)
USB30_2_SSRX_N: C43.1, C43.2, J3.A3 (TX1-), U3.4 (SSRXN)
USB30_2_SSRX_P: C42.1, C42.2, J3.A2 (TX1+), U3.5 (SSRXP)
USB30_2_SSTX_N: C40.1, C40.2, J3.B10 (RX1-), U3.7 (SSTXN)
USB30_2_SSTX_P: C41.1, C41.2, J3.B11 (RX1+), U3.8 (SSTXP)
VBAT: C52.2, C59.1, J5.1, J5.2, R33.2, U8.13 (BAT), U8.14 (BAT), U9.10 (BATT)
VBAT_REF: R32.2, R33.1, U14.2 (PA3(ADC3/T0/PCINT3)), VBAT_REF.TP
VBUS: C10.2, C44.2, C45.2, C48.2, J1.A4 (VBUS1), J1.A9 (VBUS2), J1.B4 (VBUS3), J1.B9 (VBUS4), U1.3 (VBUS2), U1.13 (VBUS1)
VSYS: 25%.A, 50%.A, 75%.A, 100%.A, C11.2, C37.2, C46.2, C47.2, C49.2, C67.1, C68.1, CHRG_STAT.A, JU_3.1, JU_4.1, JU_6.1, L1.P$2 (2), L4.2, R27.1, R30.1, R31.1, U8.15 (SYS), U8.16 (SYS), U10.3 (VIN), U14.9 (VCC), U$5.1, VSYS.1

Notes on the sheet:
CTL1: Controls whether DP is enabled or not. High is enabled, low is disabled. CTL0: Controls whether USB 3.1 is enabled (high). If CTL0 low and CTL1 is high, then 4 lanes of DisplayPort are enabled. If CTL0 is high and CTL1 is also high, then USB 3.1 and 2-lane DP is enabled.
Note: Ensure jumper is correctly populated for I2C/GPIO mode..
WIP: Requires review.
R39
0.01Ω
BQ24292i controls VBUS power path and charges lithium ion cells. MAX17055 is used for battery management. 5V 3A boost regulator to power CM5. 3v3 buck is to power the WiFi PCIe card, TPS65987D, etc.

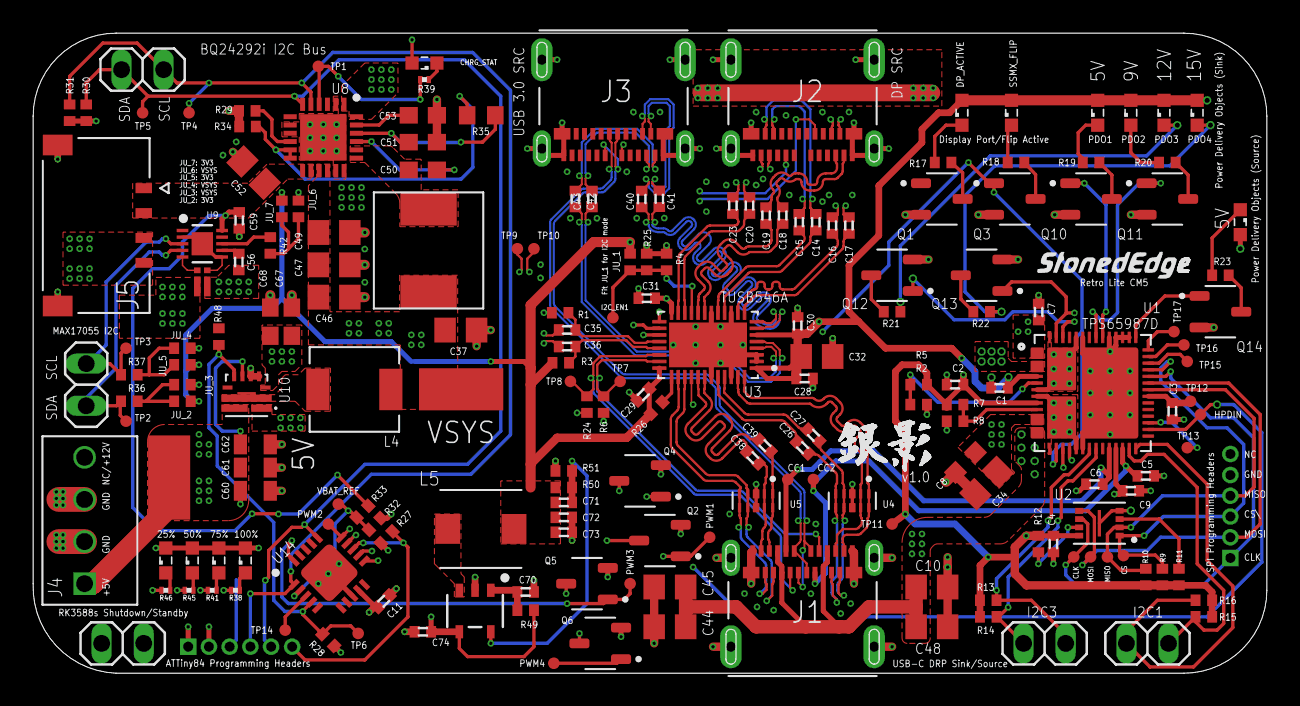
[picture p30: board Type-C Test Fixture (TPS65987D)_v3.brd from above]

Board: 6 copper layers, 74.4 x 38.6 mm, 193 parts (0 on the bottom side), 124 nets.

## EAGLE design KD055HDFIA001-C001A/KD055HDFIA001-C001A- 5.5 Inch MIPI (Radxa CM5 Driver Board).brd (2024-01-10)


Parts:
5V_VBUS: TPTP19R; TP19R
C1: 220nF; C0603
C2, C3: 1µF; C0603
C4: 4.7µF 50v; C0805
D1: MBR0540T1G; SOD3716X135N
L1: 22µH; VLCF4020_1
Q1: AO3400A; SOT95P280X125-3N
R3, R4: 10k; R0603
R5: 5Ω; R0603
U1: TPS61160ADRVT; SON65P200X200X80-7N
U$1: PAD; AMPHENOL_10129381-908001BLF

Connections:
5V_VBUS: 5V_VBUS.TP, C2.1, C3.1, L1.1, R4.2, U1.6 (VIN); also elsewhere on the board
GND: C1.1, C2.2, C3.2, C4.2, Q1.2 (S), R3.2, R5.2, U1.3 (GND), U1.7 (EP); also elsewhere on the board
GPIO_PWM: Q1.1 (G), R3.1, U$1.01
LED+: C4.1, D1.1 (K); also elsewhere on the board
LED-: R5.1, U1.1 (FB); also elsewhere on the board
unnamed: C1.2, U1.2 (COMP)
unnamed: D1.2 (A), L1.2, U1.4 (SW)
unnamed: Q1.3 (D), R4.1, U1.5 (CTRL)


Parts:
IO_VCC_1V8: TPTP19R; TP19R
J1: 10129381-908001BLF; AMPHENOL_10129381-908001BLF
J3: 5051103091; CON_5051103091_MOL
J4: 5051100892; CON_5051100892_MOL
J5: FH35C-39S-0.3SHW(50); HRS_FH35C-39S-0.3SHW(50)
LED+: TPTP19R; TP19R
LED-: TPTP19R; TP19R
R6, R7, R8, R23: 0M; R0402
VCC_A_3V3: TPTP19R; TP19R

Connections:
GND: J1.01, J1.08, J3.1, J3.2, J3.7, J3.9, J3.10, J3.13, J3.16, J3.19, J3.22, J3.25, J3.P1, J3.P2, J4.1, J4.8, J4.P1, J4.P2, J5.7, J5.8, J5.11, J5.12, J5.18, J5.19, J5.22, J5.25, J5.28, J5.31, J5.34; also elsewhere on the board
I2C_SCL_TP: J1.04, J4.5, J5.13, R23.1, R23.2
I2C_SDA_TP: J1.05, J4.4, J5.14, R7.1, R7.2
IO_VCC_1V8: IO_VCC_1V8.TP, J3.4, J5.38
LCD_RESET: J3.5, J5.36
LED+: J3.27, LED+.TP; also elsewhere on the board
LED-: J3.29, LED-.TP; also elsewhere on the board
MIPI_CL_N: J3.18, J5.27
MIPI_CL_P: J3.17, J5.26
MIPI_D0_N: J3.24, J5.33
MIPI_D0_P: J3.23, J5.32
MIPI_D1_N: J3.21, J5.30
MIPI_D1_P: J3.20, J5.29
MIPI_D2_N: J3.15, J5.24
MIPI_D2_P: J3.14, J5.23
MIPI_D3_N: J3.12, J5.21
MIPI_D3_P: J3.11, J5.20
MIPI_TE: J3.6, J5.37
NC: J1.02
TP_INT: J1.06, J4.3, J5.15, R6.1, R6.2
TP_RESET: J1.07, J4.2, J5.17, R8.1, R8.2
VCC_A_3V3: J1.03, J3.3, J4.6, J5.9, J5.10, J5.16, J5.39, VCC_A_3V3.TP
VCC_LEDA_NC: J5.1, J5.2
VCC_LEDK_NC: J5.5, J5.6


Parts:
J2: U262-161N-4BVC11
R1: 5.1K; R0603
R2: 5.1k; R0603

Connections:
5V_VBUS: J2.A4B9 (VBUS), J2.B4A9 (VBUS); also elsewhere on the board
BMS_STAT: J2.B8 (SBU2)
CC1: J2.A5 (CC1), R1.1
CC2: J2.B5 (CC2), R2.1
GND: J2.A1B12 (GND), J2.B1A12 (GND), J2.SHIELD_1 (GND), J2.SHIELD_2 (GND), J2.SHIELD_3 (GND), J2.SHIELD_4 (GND), R1.2, R2.2; also elsewhere on the board
SBU1_DOCK: J2.A8 (SBU1)


Board: 4 copper layers, 56.0 x 38.6 mm, 28 parts (0 on the bottom side), 30 nets.

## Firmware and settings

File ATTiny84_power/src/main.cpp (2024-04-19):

#include <Arduino.h>
#include "SoftwareSerial.h"
#include "bq24292i.h"

#define TEST_FIXTURE 0
#define SERIAL_DEBUG 0

byte in_power_btn = PIN_PA2;  // Power button connected to this pin. Active Low
byte out_power_on = PIN_PA1;  // Regulator power. Active High
byte out_power_btn = PIN_PA0; // CM5 Power "button". Active Low

#if SERIAL_DEBUG
#define rxPin PIN_PB1     // Pin used for Serial receive
#define txPin PIN_PB0     // Pin used for Serial transmit
SoftwareSerial mySerial(rxPin, txPin);
#else
byte out_shutdown = PIN_PB0; // Signal to start CM5 Shutdown. Active Low
byte in_shutdown = PIN_PB1;  // Signal from CM5 saying it's shutting down. Active Low
#endif

byte led_vbat_low = PIN_PB2;
#if TEST_FIXTURE
byte led_power_on = PIN_PA7;
byte led_shutdown = PIN_PA5;
#endif

bool shutdownState = false;
bool lastShutdownState = false;
bool powerState = false;
bool shutdownInit = false;

unsigned long powerBtnTimer;
unsigned long shutdownTimer;
long powerOnDelay = 1000;
long powerOffDelay = 3000;
long shutdownDelay = 10000;
bool btnTimerStarted = false;
bool shutdownTimerStarted = false;
bool lastPowerBtnState = false;

unsigned long lastShutdownDebounce = 0;
unsigned long debounceDelay = 50;

uint32_t vBatSum;
int vBatReadCounter;

// Returns average VBAT in microvolts
uint32_t readAvgVBAT() {
    // microvolts factor is: (R1 + R2) * 1.1v * 1000 / (1024 * R2) ~= 4.017578125
    vBatSum += analogRead(A3) * 4;
    vBatReadCounter++;
    return vBatSum / vBatReadCounter;
}

void BQ_INIT() {
    bq24292i_set_iin_max(BQ_IIN_MAX_3000MA);
    bq24292i_set_vin_max(5080);

    bq24292i_set_vsys_min(3500);
    bq24292i_set_charge_config(BQ_CHG_CONFIG_ENABLE);

    bq24292i_set_charge_current(2496);

    bq24292i_set_term_current(256);
    bq24292i_set_precharge_current(256);

    bq24292i_set_recharge_offset(BQ_VRECHG_100MV);
    bq24292i_set_batlow_voltage(BQ_VBATLOW_2800MV);
    bq24292i_set_max_charge_voltage(4208);

    bq24292i_set_charge_timer(BQ_CHG_TIMER_8H);
    bq24292i_set_wdt_config(BQ_WATCHDOG_DISABLE);
    bq24292i_set_charge_termination(true);

    bq24292i_set_max_temp(BQ_MAX_TEMP_80C);
    bq24292i_set_voltage_clamp(0);
    bq24292i_set_comp_resistor(0);

    bq24292i_set_interrupt_mask(BQ_INT_BAT_AND_CHRG_FAULT);
    bq24292i_set_batfet_enabled(false);
}

bool shutdownDebounce() {
    bool input = !digitalRead(in_shutdown);
    if (input != lastShutdownState)
        lastShutdownDebounce = millis() + debounceDelay;

    if (millis() > lastShutdownDebounce)
        shutdownState = input;

    lastShutdownState = input;

    if (shutdownState && shutdownTimerStarted) {
        unsigned long time = millis() + powerOffDelay;
        if (shutdownTimer > time)
            shutdownTimer = time;
    }

    return powerState && (shutdownState || shutdownInit);
}

void shutdownTimerCheck() {
    if (!shutdownTimerStarted) {
        shutdownTimerStarted = true;
        shutdownTimer = millis() + shutdownDelay;
#if (!SERIAL_DEBUG)
        digitalWrite(out_shutdown, LOW); // Tell CM5 to shut down
#endif
#if TEST_FIXTURE
        digitalWrite(led_shutdown, HIGH);
#endif
        shutdownInit = true;
    }
    else if (millis() > shutdownTimer) {
        shutdownTimerStarted = false;
        digitalWrite(out_power_on, LOW);
#if (!SERIAL_DEBUG)
        digitalWrite(out_shutdown, HIGH);
#endif
#if TEST_FIXTURE
        digitalWrite(led_power_on, LOW);
        digitalWrite(led_shutdown, LOW);
#endif
        powerState = false;
        shutdownInit = false;
    }
}

void powerTimerCheck() {
    if (!btnTimerStarted) {
        btnTimerStarted = true;
        vBatReadCounter = 0;
        vBatSum = 0;
        powerBtnTimer = millis() +
            (powerState ? powerOffDelay : powerOnDelay);
    }
    else if (millis() > powerBtnTimer) {
        btnTimerStarted = false;
        if (powerState) {
#if (!SERIAL_DEBUG)
            digitalWrite(out_shutdown, LOW);
#endif
#if TEST_FIXTURE
            digitalWrite(led_shutdown, HIGH);
#endif
            shutdownInit = true;
        }
        else if (readAvgVBAT() > 3200) { // Check battery voltage before allowing out_power_on to go high
            powerState = true;
            digitalWrite(out_power_on, HIGH);
#if TEST_FIXTURE
            digitalWrite(led_power_on, HIGH);
#endif
        }
        else {
            // Flash LED if the user presses the button down during low battery and system off state
            for (int i = 0; i < 10; i++) {
                digitalWrite(led_vbat_low, HIGH);
                delay(250);
                digitalWrite(led_vbat_low, LOW);
                delay(250);
            }
        }
    }
    else if (!powerState)
        readAvgVBAT();      // Keep reading voltage while button is pressed
}

void setup() {
    cli();                  // Disable interrupts
    CLKPR = (1 << CLKPCE);  // Prescaler enable
    CLKPR = 0x00;           // Clock division factor
    sei();                  // Enable interrupts

    pinMode(in_power_btn, INPUT_PULLUP);
    pinMode(out_power_on, OUTPUT);
    pinMode(out_power_btn, OUTPUT);
#if (!SERIAL_DEBUG)
    pinMode(out_shutdown, OUTPUT);
    pinMode(in_shutdown, INPUT_PULLUP);
#endif
    pinMode(led_vbat_low, OUTPUT);
#if TEST_FIXTURE
    pinMode(led_power_on, OUTPUT);
    pinMode(led_shutdown, OUTPUT);
#endif

    pinMode(A3, INPUT);
    analogReference(INTERNAL);  // Setup the ADC voltage ref as 1.1V

    digitalWrite(out_power_on, LOW);
    digitalWrite(out_power_btn, HIGH);
#if (!SERIAL_DEBUG)
    digitalWrite(out_shutdown, HIGH);
#endif
    digitalWrite(led_vbat_low, LOW);
#if TEST_FIXTURE
    digitalWrite(led_power_on, LOW);
    digitalWrite(led_shutdown, LOW);
#endif

    i2c_master_init();

    BQ_INIT();

#if SERIAL_DEBUG
    mySerial.begin(9600);
    delay(2000);
    mySerial.println("SETUP Complete");
    if (bq24292i_is_present())
        mySerial.println("bq24292i is present")
#endif
}

void loop() {
    bool powerBtnState = !digitalRead(in_power_btn);

    if (shutdownDebounce())
        shutdownTimerCheck();
    else if (powerBtnState)
        powerTimerCheck();
    else if (lastPowerBtnState && btnTimerStarted) {
        // User released the power button before timer elapsed, pass it on.
        digitalWrite(out_power_btn, LOW);
        delay(200);
        digitalWrite(out_power_btn, HIGH);
    }
    else
        btnTimerStarted = false;

    lastPowerBtnState = powerBtnState;
}

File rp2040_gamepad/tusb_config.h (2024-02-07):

/*
 * The MIT License (MIT)
 *
 * Copyright (c) 2019 Ha Thach (tinyusb.org)
 *
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
 */

#ifndef _TUSB_CONFIG_H_
#define _TUSB_CONFIG_H_

#ifdef __cplusplus
 extern "C" {
#endif

//--------------------------------------------------------------------
// COMMON CONFIGURATION
//--------------------------------------------------------------------

// defined by board.mk
#ifndef CFG_TUSB_MCU
  #error CFG_TUSB_MCU must be defined
#endif

// RHPort number used for device can be defined by board.mk, default to port 0
#ifndef BOARD_DEVICE_RHPORT_NUM
  #define BOARD_DEVICE_RHPORT_NUM     0
#endif

// RHPort max operational speed can defined by board.mk
// Default to Highspeed for MCU with internal HighSpeed PHY (can be port specific), otherwise FullSpeed
#ifndef BOARD_DEVICE_RHPORT_SPEED
  #if (CFG_TUSB_MCU == OPT_MCU_LPC18XX || CFG_TUSB_MCU == OPT_MCU_LPC43XX || CFG_TUSB_MCU == OPT_MCU_MIMXRT10XX || \
       CFG_TUSB_MCU == OPT_MCU_NUC505  || CFG_TUSB_MCU == OPT_MCU_CXD56 || CFG_TUSB_MCU == OPT_MCU_SAMX7X)
    #define BOARD_DEVICE_RHPORT_SPEED   OPT_MODE_HIGH_SPEED
  #else
    #define BOARD_DEVICE_RHPORT_SPEED   OPT_MODE_FULL_SPEED
  #endif
#endif

// Device mode with rhport and speed defined by board.mk
#if   BOARD_DEVICE_RHPORT_NUM == 0
  #define CFG_TUSB_RHPORT0_MODE     (OPT_MODE_DEVICE | BOARD_DEVICE_RHPORT_SPEED)
#elif BOARD_DEVICE_RHPORT_NUM == 1
  #define CFG_TUSB_RHPORT1_MODE     (OPT_MODE_DEVICE | BOARD_DEVICE_RHPORT_SPEED)
#else
  #error "Incorrect RHPort configuration"
#endif

#ifndef CFG_TUSB_OS
#define CFG_TUSB_OS               OPT_OS_NONE
#endif

// CFG_TUSB_DEBUG is defined by compiler in DEBUG build
// #define CFG_TUSB_DEBUG           0

/* USB DMA on some MCUs can only access a specific SRAM region with restriction on alignment.
 * Tinyusb use follows macros to declare transferring memory so that they can be put
 * into those specific section.
 * e.g
 * - CFG_TUSB_MEM SECTION : __attribute__ (( section(".usb_ram") ))
 * - CFG_TUSB_MEM_ALIGN   : __attribute__ ((aligned(4)))
 */
#ifndef CFG_TUSB_MEM_SECTION
#define CFG_TUSB_MEM_SECTION
#endif

#ifndef CFG_TUSB_MEM_ALIGN
#define CFG_TUSB_MEM_ALIGN          __attribute__ ((aligned(4)))
#endif

//--------------------------------------------------------------------
// DEVICE CONFIGURATION
//--------------------------------------------------------------------

#ifndef CFG_TUD_ENDPOINT0_SIZE
#define CFG_TUD_ENDPOINT0_SIZE    64
#endif

//------------- CLASS -------------//
#define CFG_TUD_HID               1
#define CFG_TUD_CDC               1
#define CFG_TUD_MSC               0
#define CFG_TUD_MIDI              0
#define CFG_TUD_VENDOR            0

// HID buffer size Should be sufficient to hold ID (if any) + Data
#define CFG_TUD_HID_EP_BUFSIZE    64

// CDC FIFO size of TX and RX
#define CFG_TUD_CDC_RX_BUFSIZE   (TUD_OPT_HIGH_SPEED ? 512 : 64)
#define CFG_TUD_CDC_TX_BUFSIZE   (TUD_OPT_HIGH_SPEED ? 512 : 64)

// CDC Endpoint transfer buffer size, more is faster
#define CFG_TUD_CDC_EP_BUFSIZE   (TUD_OPT_HIGH_SPEED ? 512 : 64)

#ifdef __cplusplus
 }
#endif

#endif /* _TUSB_CONFIG_H_ */

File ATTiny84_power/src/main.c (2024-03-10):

#include <Arduino.h>
#include "bq24292i.h"

byte power_btn = PIN_PA2;           // Power button connected to this pin. Low Active
byte sys_on = PIN_PA1;              // Regulator power. Active High
byte sht_dwn = PIN_PB0;             // Connected to GPIO25. Signal to start CM5 Shutdown. Active High
byte low_volt_shutdown = PIN_PB1;   // Connected to GPIO16 on CM5. Used for low voltage shut down

byte led1 = PIN_PB2;
byte led2 = PIN_PA7;
byte led3 = PIN_PA5;

bool lowVoltInState = false;
bool lastLowVoltInState = false;
bool systemState = false;
bool shutdownInit = false;

unsigned long powerBtnTimer;
unsigned long shutDown;
long powerOnDelay = 1000;
long powerOffDelay = 3000;
long shutDownDelay = 10000;
bool btnTimerStarted = false;
bool shutDownTimerStarted = false;

unsigned long lastLowVoltDebounce = 0;
unsigned long debounceDelay = 50;

const float R1 = 10000.0;  // Value of R1 resistor div 
const float R2 = 27400.0;  // Value of R2 resistor div
float vBatSum;
uint8_t vBatReadCounter;

float readAvgVBAT() {
    uint8_t vBatADCRaw = analogRead(A3);              // Store ADC reading
    float vBatADCVoltage = (vBatADCRaw * 1.1) / 256.0;  // Convert analog to voltage value
    float vBatAdj = vBatADCVoltage / (R2 / (R1 + R2));  // Adjust voltage for divider
    vBatSum += vBatAdj;
    vBatReadCounter++;
    return vBatSum / vBatReadCounter;
}

void BQ_INIT() {
    bq24292i_set_iin_max(BQ_IIN_MAX_3000MA);
    bq24292i_set_vin_max(5080);

    bq24292i_set_vsys_min(3500);
    bq24292i_set_charge_config(BQ_CHG_CONFIG_ENABLE);

    bq24292i_set_charge_current(2496);

    bq24292i_set_term_current(256);
    bq24292i_set_precharge_current(256);

    bq24292i_set_recharge_offset(BQ_VRECHG_100MV);
    bq24292i_set_batlow_voltage(BQ_VBATLOW_2800MV);
    bq24292i_set_max_charge_voltage(4208);

    bq24292i_set_charge_timer(BQ_CHG_TIMER_8H);
    bq24292i_set_wdt_config(BQ_WATCHDOG_DISABLE);
    bq24292i_set_charge_termination(true);

    bq24292i_set_max_temp(BQ_MAX_TEMP_80C);
    bq24292i_set_voltage_clamp(0);
    bq24292i_set_comp_resistor(0);

    bq24292i_set_interrupt_mask(BQ_INT_BAT_AND_CHRG_FAULT);
    bq24292i_set_batfet_enabled(false);
}

void lowVoltShutdownDebounce() {
    bool input = !digitalRead(low_volt_shutdown);
    if (input != lastLowVoltInState)
        lastLowVoltDebounce = millis() + debounceDelay;

    if (millis() > lastLowVoltDebounce)
        lowVoltInState = input;

    lastLowVoltInState = input;
}

void shutdownTimer() {
    if (!shutDownTimerStarted) {
        shutDown = millis() + shutDownDelay;
        shutDownTimerStarted = true;
        digitalWrite(sht_dwn, HIGH); // Tell CM5 to Shut down
        digitalWrite(led3, HIGH);
        shutdownInit = true;
    }
    else if (millis() > shutDown) {
        digitalWrite(sys_on, LOW);
        digitalWrite(sht_dwn, LOW);
        digitalWrite(led2, LOW);
        digitalWrite(led3, LOW);
        systemState = 0;
        shutDownTimerStarted = false;
        shutdownInit = false;
    }
}

void powerTimerCheck() {
    if (!btnTimerStarted) {
        btnTimerStarted = true;
        vBatReadCounter = 0;
        vBatSum = 0;
        powerBtnTimer = millis() +
            ((systemState == 0) ? powerOnDelay : powerOffDelay);
    }
    else if (millis() > powerBtnTimer) {
        btnTimerStarted = false;
        if (systemState) {
            systemState = false;
            digitalWrite(sht_dwn, HIGH);
            digitalWrite(led3, HIGH);
            shutdownInit = true;
        }
        else if (readAvgVBAT() > 3.2) { // Check battery voltage before allowing sys_on to go high
            systemState = true;
            digitalWrite(sys_on, HIGH);
            digitalWrite(led2, HIGH);
        }
        else {
            // Flash LED1 if the user presses the button down during low battery and system off state
            for (int i = 0; i < 10; i++) {
                digitalWrite(led1, HIGH);
                delay(250);
                digitalWrite(led1, LOW);
                delay(250);
            }
        }
    }
    else if (!systemState)
        readAvgVBAT();      // Keep reading voltage while button is pressed
}

void setup() {
    cli();                  // Disable interrupts
    CLKPR = (1 << CLKPCE);  // Prescaler enable
    CLKPR = 0x00;           // Clock division factor
    sei();                  // Enable interrupts
    
    pinMode(power_btn, INPUT_PULLUP);
    pinMode(sys_on, OUTPUT);
    pinMode(sht_dwn, OUTPUT);
    pinMode(low_volt_shutdown, INPUT_PULLUP);
    pinMode(led1, OUTPUT);
    pinMode(led2, OUTPUT);
    pinMode(led3, OUTPUT);

    pinMode(A3, INPUT);
    analogReference(INTERNAL);  // Setup the ADC voltage ref as 1.1V

    // Not sure if these are needed?
    ADMUX  |= (1 << ADLAR);     // Left Adjust the ADCH and ADCL registers for 8-bit resolution. No need for 10-bit
    ADCSRA |= (1 << ADEN);      // ADC enable 
    ADCSRA |= (1 << ADPS1);     // Set prescaler 
    ADCSRA |= (1 << ADPS0);     // Set division factor-8 for 1MHz ADC clock

    digitalWrite(led1, LOW);
    digitalWrite(led2, LOW);
    digitalWrite(led3, LOW);

    i2c_master_init();

    // digitalWrite(led1, bq24292i_is_present());

    BQ_INIT(); 
}

void loop() {
    bool powerBtnState = !digitalRead(power_btn);
    lowVoltShutdownDebounce();

    if (shutdownInit || lowVoltInState)
        shutdownTimer();
    else if (powerBtnState)
        powerTimerCheck();
    else
        btnTimerStarted = false;
}

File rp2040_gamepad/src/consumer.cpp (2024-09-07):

#include "gamepad.h"

static uint16_t lastKey = 0;

uint16_t get_consumer_report(uint8_t* buffer, uint16_t reqlen)
{
    if (reqlen >= 2) {
        *(uint16_t*)buffer = 0;
        return 2;
    }

    return 0;
}

bool send_consumer_report()
{
    // Poll every 10ms
    const uint32_t interval_ms = 10;
    static uint32_t start_ms = 0;

    if (board_millis() - start_ms < interval_ms)
        return false; // not enough time
    start_ms += interval_ms;

    uint16_t key = 0;
    if (buttonState[BTN_HOTKEY_PLUS]) {
        if (dpadPinState[DPAD_UP])
            key = HID_USAGE_CONSUMER_BRIGHTNESS_INCREMENT;
        else if (dpadPinState[DPAD_DOWN])
            key = HID_USAGE_CONSUMER_BRIGHTNESS_DECREMENT;
        else if (dpadPinState[DPAD_LEFT])
            key = HID_USAGE_CONSUMER_VOLUME_DECREMENT;
        else if (dpadPinState[DPAD_RIGHT])
            key = HID_USAGE_CONSUMER_VOLUME_INCREMENT;
    }

    if (lastKey != key) {
        tud_hid_report(REPORT_ID_CONSUMER_CONTROL, &key, 2);
        lastKey = key;
        return true;
    }

    return false;
}

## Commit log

2023-11-06 Working buttons
2023-11-07 Label buttons, bring back calibration
2023-11-16 Remove DMP, bring back Keyboard, add Multi-Axis controller and one more button
2023-12-04 Initial framework for RP2040 (as an air mouse)
2024-01-05 RP2040 v1 alpha PCB schematics/BOM
    [Retro_Lite_CM5_Right_PCB_v1 - BOM.csv, Retro_Lite_CM5_Right_PCB_v1 - RP2040.brd, Retro_Lite_CM5_Right_PCB_v1 - RP2040.sch]
2024-01-05 Update and rename rp2040_gamepad/Retro_Lite_CM5_Right_PCB_v1 - BOM.csv to rp2040_gamepad/PCB/Retro_Lite_CM5_Right_PCB_v1 - BOM.csv
    [Retro_Lite_CM5_Right_PCB_v1 - BOM.csv]
2024-01-05 Rename rp2040_gamepad/Retro_Lite_CM5_Right_PCB_v1 - RP2040.brd to rp2040_gamepad/PCB/Retro_Lite_CM5_Right_PCB_v1 - RP2040.brd
    [Retro_Lite_CM5_Right_PCB_v1 - RP2040.brd]
2024-01-05 Rename rp2040_gamepad/Retro_Lite_CM5_Right_PCB_v1 - RP2040.sch to rp2040_gamepad/PCB/Retro_Lite_CM5_Right_PCB_v1 - RP2040.sch
    [Retro_Lite_CM5_Right_PCB_v1 - RP2040.sch]
2024-01-07 Add Type-C TPS65987D/TUSB546 PCB design files
    [Type-C Test Fixture (TPS65987D)_v1.brd, Type-C Test Fixture (TPS65987D)_v1.sch]
2024-01-10 Rename Type-C Test Fixture (TPS65987D)_v1.brd to tps65987d/Type-C Test Fixture (TPS65987D)_v1.brd
    [Type-C Test Fixture (TPS65987D)_v1.brd]
2024-01-10 Rename Type-C Test Fixture (TPS65987D)_v1.sch to tps65987d/Type-C Test Fixture (TPS65987D)_v1.sch
    [Type-C Test Fixture (TPS65987D)_v1.sch]
2024-01-10 Rename KD055HDFIA001-C001A- 5.5 Inch MIPI (Radxa CM5 Driver Board) - Gerbers.zip to KD055HDFIA001-C001A/KD055HDFIA001-C001A- 5.5 Inch MIPI (Radxa CM5 Driver Board) - Gerbers.zip
2024-01-10 Rename KD055HDFIA001-C001A- 5.5 Inch MIPI (Radxa CM5 Driver Board).brd to KD055HDFIA001-C001A/KD055HDFIA001-C001A- 5.5 Inch MIPI (Radxa CM5 Driver Board).brd
    [KD055HDFIA001-C001A- 5.5 Inch MIPI (Radxa CM5 Driver Board).brd]
2024-01-10 Rename KD055HDFIA001-C001A- 5.5 Inch MIPI (Radxa CM5 Driver Board).sch to KD055HDFIA001-C001A/KD055HDFIA001-C001A- 5.5 Inch MIPI (Radxa CM5 Driver Board).sch
    [KD055HDFIA001-C001A- 5.5 Inch MIPI (Radxa CM5 Driver Board).sch]
2024-01-12 Fix ADCIN1 resistor div
    [Type-C Test Fixture (TPS65987D)_v2.brd, Type-C Test Fixture (TPS65987D)_v2.sch]
2024-01-15 Placeholder for STL files
2024-01-15 Initial (broken) placeholder for gamepad code
    [consumer.cpp, gamepad.cpp, main.cpp]
2024-01-15 Use flash to store calibration
2024-01-15 Enable ADC
2024-01-17 Minor fixes and formatting nits
    [gamepad.cpp, main.cpp]
2024-01-18 Remove delays from calibration
2024-01-29 Add v1.0 Retro Lite CM5 enclosure STLs
    [A_Button.stl, B_Button.stl, Battery Bracket.stl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]
2024-01-29 Fix button issues
    [A_Button.stl, B_Button.stl, DPAD.stl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]
2024-01-29 Remove STL files due to errors
    [A_Button.stl, B_Button.stl, Battery Bracket.stl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]
2024-02-06 Fix button mapping
2024-02-06 Mouse toggle should be different from calibration
2024-02-06 Fix I2C and UART
    [main.cpp]
2024-02-06 Fix calibration persist
2024-02-08 Add v14 individual CM5 enclosure files
    [A.stl, B.stl, Case Front.stl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]
2024-02-10 Swap USB30_2_SSTX_* & USB30_2_SSRX_* lanes
    [Type-C Test Fixture (TPS65987D)_v3.brd, Type-C Test Fixture (TPS65987D)_v3.sch]
2024-02-12 Add mouse calibration, swap axes
    [calibration.cpp, consumer.cpp, gamepad.cpp]
2024-02-13 Update and rename Select .step to Select.step
    [Select.step]
2024-02-17 Upload v3 schematic (PDF)
2024-02-19 Upload BoM
    [Type-C Test Fixture (TPS65987D)_v3_BOM.xlsx]
2024-02-19 Upload BoM (CSV)
    [Type-C Test Fixture (TPS65987D)_v3_BOM.csv]
2024-02-21 Fix 5V FB resistors
    [Type-C Test Fixture (TPS65987D)_v3.brd, Type-C Test Fixture (TPS65987D)_v3.sch]
2024-02-21 Fix 5V feedback resistors
2024-02-22 Fix pins and timings
    [main.c]
2024-02-23 Invert low voltage logic + pull down
    [main.c]
2024-02-23 Add bq24292i driver copyright
2024-02-23 Use LEDs for monitoring current state
2024-02-28 Upload v1.0 CM5 carrier board
    Order at your own risk! Untested.
    [Retro_Lite_CM5_IO_X2.2.brd, Retro_Lite_CM5_IO_X2.2.sch]
2024-02-28 Fix M.2 standoff hole size for 9774015243R
    [Retro_Lite_CM5_IO_X2.2.brd, Retro_Lite_CM5_IO_X2.2.sch]
2024-02-28 Gib gerbers. Untested!
2024-02-28 Upload mnt (top) placement co-ordinates
    [Retro_Lite_CM5_IO_X2.2_CPL.csv]
2024-03-04 Fix plus hotkey tolerances
    [Plus Hotkey.stl]
2024-03-05 Add BG_STAT, PG_GOOD pins to CM5 GPIOs
    [Retro_Lite_CM5_IO_X2.2.brd, Retro_Lite_CM5_IO_X2.2.sch]
2024-03-05 Fix rear triggers (0.5mm tolerance gap)
    [Rear Trigger Mirror.stl, Rear Trigger.stl, Trigger Mount Mirror.stl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]
2024-03-08 Initial device tree draft
2024-03-10 Avoid turning the system on when battery is low
    [main.c]
2024-03-10 Fix VBAT limit handling
    [bq24292i.cpp, main.cpp]
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2024-03-31 Add speaker chambers
    [Left Speaker Chamber Bottom.stl, Left Speaker Chamber Top.stl, Left Speaker Cover.stl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]
2024-03-31 Update rear trigger pivot slots to 2.0mm thickness
    [Rear Trigger Mirror.stl, Rear Trigger.stl]
2024-04-15 Simplify device tree, add MAX17055 model config
2024-04-18 Switch shutdown signal to active low.
2024-04-18 Patch logind to respond to the "lid" button
2024-04-26 Positive for silicone mould creation
2024-04-26 Upload silicone membrane moulds
    [Silicone_Membrane_Mold_Lower.stl, Silicone_Membrane_Mold_Upper.stl]
2024-05-15 Re-arrange folders
    [Retro_Lite_CM5_Left_PCB_v1 - RP2040.brd, Retro_Lite_CM5_Left_PCB_v1 - RP2040.sch, Retro_Lite_CM5_Right_PCB_v1 - BOM.csv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]
2024-06-08 Upload new v2 STLs
    [A.stl, B.stl, Case Front.stl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]
2024-06-27 Add final case assets
    [A.stl, B.stl, Battery Bracket (5000mAh).stl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]
2024-06-27 Upload final working CM5 carrier board
    [RetroLiteCM5IOFinal.sch]
2024-07-11 Increase battery bracket to 1mm and add spacer
    [Battery Bracket (5000mAh).stl, Trigger_Spacer.stl]
2024-07-20 Remove board config, move patches to "vendor" kernel
2024-08-16 Fix multiaxis device product ID
2024-08-25 Swap back OTG/host lanes
    [RetroLiteCM5IOFinal.sch]
2024-08-25 Upload left PCB BOM
    [Retro_Lite_CM5_Left_PCB_v1 - BOM.csv]
2024-09-06 Add GET_REPORT support, fix R3 issue, increase dead zone
    [consumer.cpp, gamepad.cpp, main.cpp]
2024-09-10 Add 5.5" OLED panel timings
    [ET055FH06-GT-Timings.xlsx]
2024-09-10 Upload fan FFC gerbers/flex files
    [Retro Lite CM5 Fan FFC.brd, Retro Lite CM5 Fan FFC.sch]
2024-09-24 Add OLED carrier board flex adapter files
    [Flex v2.brd, Flex v2.sch]
2024-09-26 Add OLED panel front case
    [Case Front (OLED).stl]
2024-10-11 Turn down fan speed and change freq to 25kHz
2024-12-22 Add alternative rear case with smaller exhaust vents
    [Case Rear (Smaller Vent Holes).stl]
2025-02-25 Fix volume minus GPIO, add TPS6598x IRQ to GPIO1_D1
    [RetroLiteCM5IOFinal_v2.sch]
2025-02-25 Add main PCB latest gerbers
2025-02-25 Add left PCB gerbers
2025-02-25 Upload right PCB gerber files
2025-06-03 Rename Battery Bracket (5000mAh).stl to Battery Bracket (8000mAh).stl
    [Battery Bracket (8000mAh).stl]
2025-06-07 Upload button spacers + rotation stopper for silicone membranes
    [Button Rotation Stopper Bracket.stl, Button Spacers.stl]
2025-06-10 Flip TPS65987D jumper clock/data (I2C)
    [RetroLiteCM5IOFinal_v2.sch]
2025-06-13 Fix HDMI ground pads
    [RetroLiteCM5IOFinal_v3.sch]
2025-06-24 Add PDF schematic (mainboard)
2025-06-24 Add assemblies (speaker housings) fused
    [Left Speaker Chamber Assembly.stl, Right Speaker Chamber Assembly.stl]
2025-09-07 Fix placement of tab screw holes
2025-09-09 Upload carrier PCBs in gerber format

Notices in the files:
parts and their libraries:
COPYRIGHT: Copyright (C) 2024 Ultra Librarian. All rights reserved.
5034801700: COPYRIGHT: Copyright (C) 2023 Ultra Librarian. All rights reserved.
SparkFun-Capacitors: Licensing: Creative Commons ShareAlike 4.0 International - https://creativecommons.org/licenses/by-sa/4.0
